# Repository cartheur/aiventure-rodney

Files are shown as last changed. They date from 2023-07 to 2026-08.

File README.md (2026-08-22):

# aiventure-rodney

A project revolving around Heiserman's 1979 robotics proposition. The focus is _scratch-building_ computer that possesses and executes self-learning machine code. They [ref]--(I think an Motorola 6800 computer design book) say this is _a dangerous practice_ having a comptuer self-generate code - with the notion that it programs - but if we do not start seriously exploring in slower formats (slow that our brains can recognize *good* from *bad*), then we we stay stuck. Given the time spent with _Ideal_, games will get one just so far; an effort begins today where we emplant Rodney onto a wheeled platform. Once there, we will backpropagate different kinds of dangerous things. I think this has been accomplished before, I mean the robot by the unknown designer and creator a late academic dubbed _Tati_. And I've watched his films, they are subtley brilliant.

## Challenge

This repository contains a revitialization of the idea of a self-programming robot coupled with the ambition to learn the deepest aspects of how a computer functions at its most basic level. The book, written in 1979, leverages an Intel 8085 8-bit (the very last CPU made to this specification) where the reader builds up the system from scratch including the logic, buffers, and memory systems. Additionally, a tape-drive storage interface is described. Not just an historical curiousity, Rodney continues to teach readers by having them build one step at a time. The challenge of this project is to make a build of the microcomputer system to examine the merit of the "self-programming" claim. On this rests *everything* claimed 'A.I.'. This is a total misnomer and will need to be discussed in great detail.

Current scope note: an `MTK-85`/single-board `8085` trainer was considered as a possible parallel development track and explicitly rejected. This repo stays focused on the Rodney-native `Vector 8801-6` wire-wrap path rather than a separate trainer-board line.

### The Build

There is _a lot_ of work to be done for this project. It is parceled into sections:

* [Chassis Design](/design/README.md)
* [The Front Panel UI](/build/5-front-panel/README.md)
* [Function-Select Circuitry](/build/6-function-select/README.md)
* [RAM and Ports](/build/7-ram-ports/README.md)
* [Motor-Drive Assembly](/build/8-motor-control/README.md)
* [The Microprocessor](/build/9-microprocessor/README.md)
* [Tests](/tests/README.md)

### Pubbing

The publication for this is drafted [here](https://github.com/pub-n-dub/native-self-programming).

### Errata

Tooling used for this project is kept [here](/tools/README.md).

As it is necessary to explore the algorithm of [ideal](https://github.com/cartheur/ideal), we are stretching into unknown realms. How do we document this unexpected journey?

* An alternative to the Von Neumann architecture is the [initiative](/literature/s41565-020-0738-x.pdf).
* A combination of hardware and software [implementation](https://en.wikipedia.org/wiki/In-memory_processing).
* What are some forward-looking paths, considering the initiatives, without going into the nanoscale esoteric?
* SRAM and DRAM are perfectly capable of performing in-memory logic operations while NAND Flash memory is fit for matrix–vector multiplication operations.
* In the context of the application-specific approach to computation, memory-based computational primitives can be used in a variety of tasks ranging from high-precision scientific computing to largely imprecise stochastic computing and everything in-between including deep learning in artificial neural networks (ANNs).
* Development of microFORTH in 1976 for processors like Intel 8080 and Motorola 6800.

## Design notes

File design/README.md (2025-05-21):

## The physical characteristics of this robot

The robot chassis is based on this diagram:

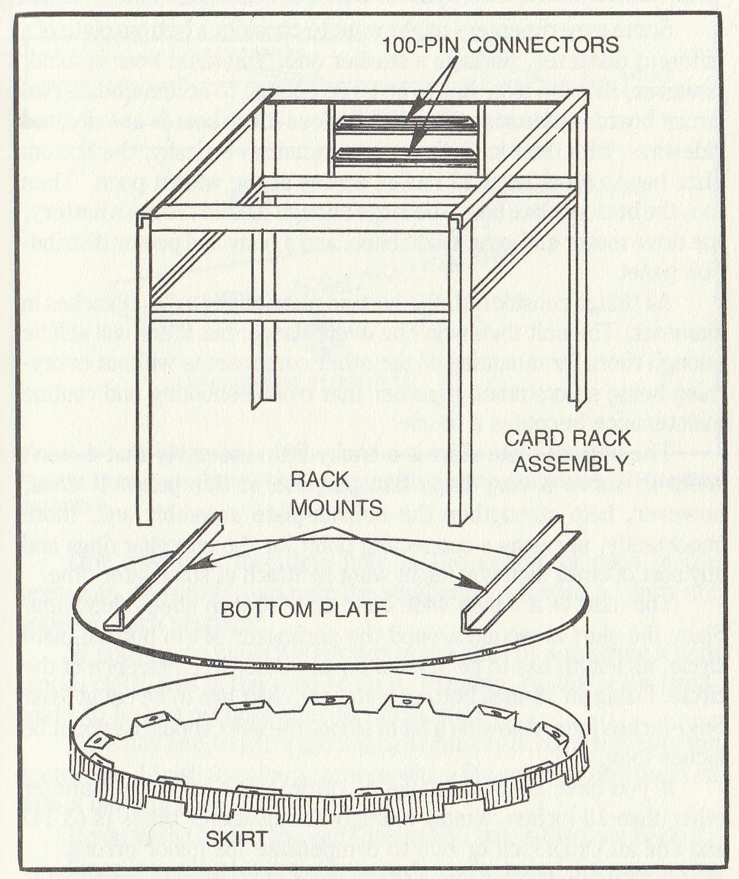
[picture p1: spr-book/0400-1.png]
base


Where the disk is 457 mm (18").

With an upward construct to hold the boards:

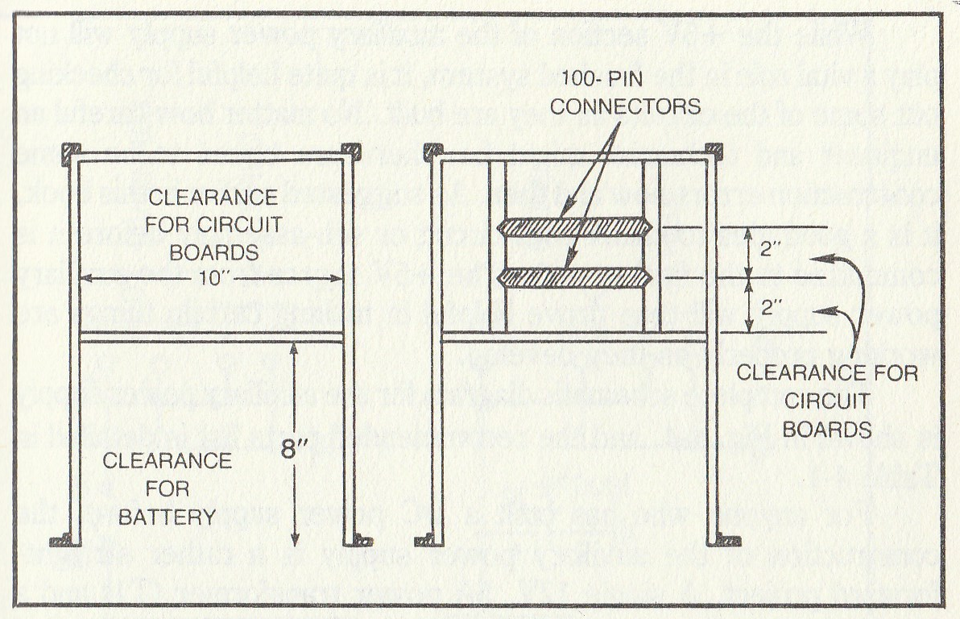
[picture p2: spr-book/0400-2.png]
rack


Re-contemplating the design architecture: Grok analyzed the photos and has come-up with his estimate, given the information regarding Vector 8801 boards that are mounted internally:

* Width: 280 mm
* Depth: 280 mm
* Height: 360 mm
* Weight: 23 kg

### The Vector board 8801-6 using a S-100 bus

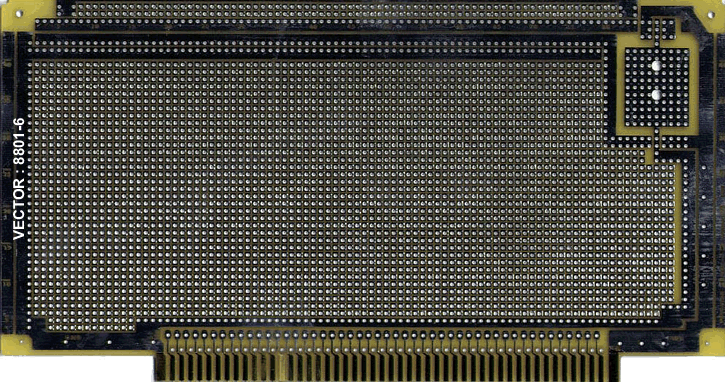
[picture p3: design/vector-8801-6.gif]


_Specification_

| Dimensions  (H x W x Thick) | 10.50" x 5.30" x 0.062"  (266.7mm x 134.6mm x 1.57mm) |
|---|---|
| Hole Diameter | 0.042" (1.067mm) Plated Thru |
| Grid | 0.100" x 0.100" square  (2.54mm x 2.54mm) |
| Circuit Pattern | Pad per hole - both sides |
| Material | FR4 |
| UL Flammability Class | 94V-0 |
| 16 Pin DIP Capacity | 80 |
| Wire-Wrap Terminals | T125, T126 |
| Wire-Wrap Socket Pins | R32 |
| Solder Connector | R681-3 |
| Wire-Wrap Connector | R681-2 |

_Description_

* 100 Gold plated edge contacts (50 each side) on 0.125"(3.175mm) centers
* Pad per hole (square) both sides
* I/O mounting area for ribbon cable header
* Row and column legends provided
* S-100 Form Factor
* Pin `1` and `51` committed to power.
* Pin `50` and `100` committed to ground.

### Grok-generated 3D printing design suggestions

The textual description is [here](/design/GROK.md), while details of FreeCAD design are [here](/design/PRINT.md).

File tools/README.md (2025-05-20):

## Tools to be used to accomplish assembly

This project will follow the advice of the author and perform wirewrapping for each of the connections, except soldering to the switches and LED connections.

_Wire_

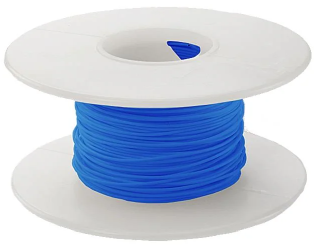
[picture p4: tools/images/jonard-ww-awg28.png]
ww-awg28


Several colors of wirewrap wire will be used to correspond to the different colors utilized in the [interface](/build/5-front-panel/README.md). These are:

* Blue
* Red (mock orange)
* Black (common)
* Raw tinned (common connection)
* Yellow
* Green

All are of the size:`AWG28`.

_Tooling_

The wirewrap tool to be used is this one:

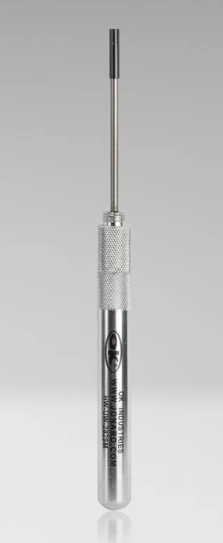
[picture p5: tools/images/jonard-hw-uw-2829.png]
ww-tool


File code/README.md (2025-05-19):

# Example 8085 Assembly Program with Self-Modifying Code

_The following is Grok output from my query of what Heiserman is claiming in his book:_

This Intel 8085 assembly program demonstrates self-modifying code, illustrating runtime adaptability as a crude mechanism for dynamic behavior, aligning with Turing’s idea of machines adapting to experience. It modifies a `JMP` instruction’s target address based on an input condition, while highlighting risks that led Intel to discourage such practices for the 8085.

## Program Description

- **Purpose**: Reads an input value at memory address `2000H` (e.g., simulating sensor data). If the value is ≥ 50, it modifies a `JMP` instruction to point to `HIGH_ROUTINE` (outputs “HIGH”). If < 50, it points to `LOW_ROUTINE` (outputs “LOW”).
- **Self-Modification**: Overwrites the `JMP` instruction’s 16-bit address at runtime to redirect program flow.
- **Context**: Shows adaptability but underscores risks like unpredictability, debugging complexity, and potential memory overwrites.

## How It Demonstrates Self-Modifying Code

1. **Dynamic Modification**:
   - The `JMP_MOD` instruction (initially `JMP 0000H`) is overwritten with the `JMP` opcode (`0C3H`) and the 16-bit address of either `LOW_ROUTINE` or `HIGH_ROUTINE` at `JMP_MOD`, `JMP_MOD+1`, and `JMP_MOD+2`.
   - This redirects program flow based on the input, showcasing runtime adaptability.

2. **Adaptability**:
   - The program adapts by selecting a routine based on the input value at `2000H` (e.g., 60 → `HIGH_ROUTINE`, 40 → `LOW_ROUTINE`), mimicking a response to environmental input, akin to Turing’s experiential learning concept.

3. **Risks Highlighted**:
   - **Unpredictability**: If the 8085 fetches the `JMP` instruction before modification completes, it may execute the outdated `JMP 0000H`, causing incorrect behavior.
   - **Debugging Difficulty**: The dynamic `JMP` target complicates tracing program flow, especially with 1980s tools like in-circuit emulators.
   - **Memory Overwrite Risk**: Errors in address calculations could overwrite critical code or data, reflecting Intel’s reliability concerns.

## Why This Is Crude

- **Not True Learning**: The modification is predefined (choosing between two routines), not a generalized response learned from experience, unlike Turing’s vision of neural-like learning.
- **Limited Scope**: Adaptability is limited to switching between two predefined paths, not a scalable learning mechanism.
- **Hardware Constraints**: The 8085’s 64 KB memory and simple fetch-execute cycle restrict complex self-modification.

## Notes

- **Simulation**: Assumes an input value at `2000H` (e.g., set by external hardware) and writes output to `2001H`. In real systems, I/O ports might be used.
- **Assembly Syntax**: Uses standard 8085 mnemonics, compatible with assemblers like Intel’s ASM80 or modern cross-assemblers.
- **Testing**: Set a value at `2000H` (e.g., 60 for high, 40 for low) and run on an 8085 emulator (e.g., Jubin’s 8085 Simulator). Check `2001H` for ‘H’ or ‘L’.

This example illustrates self-modifying code’s potential for runtime adaptability while highlighting its risks and limitations, reinforcing why Intel advised against it for the 8085.

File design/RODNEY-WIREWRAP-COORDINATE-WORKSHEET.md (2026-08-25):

# Rodney Wire-Wrap Coordinate Worksheet

First-pass socket worksheet for the `3 x Vector 8801-6` Rodney bench build.

This turns the block diagrams and placement plan into **board-local placement coordinates** that are concrete enough to start socket layout and hole counting.

Companion docs:

- [RODNEY-WIREWRAP-BLOCK-DIAGRAM.md](/home/cartheur/ame/aiventure/aiventure-github/cartheur/aiventure-rodney/design/RODNEY-WIREWRAP-BLOCK-DIAGRAM.md:1)
- [RODNEY-WIREWRAP-PLACEMENT-PLAN.md](/home/cartheur/ame/aiventure/aiventure-github/cartheur/aiventure-rodney/design/RODNEY-WIREWRAP-PLACEMENT-PLAN.md:1)
- [RODNEY-WIREWRAP-DESIGN-SPEC.md](/home/cartheur/ame/aiventure/aiventure-github/cartheur/aiventure-rodney/design/RODNEY-WIREWRAP-DESIGN-SPEC.md:1)

Rendered planning images:

- [Board A worksheet JPG](/home/cartheur/ame/aiventure/aiventure-github/cartheur/aiventure-rodney/diagrams/RodneyBoardA-worksheet.jpg)
- [Board B worksheet JPG](/home/cartheur/ame/aiventure/aiventure-github/cartheur/aiventure-rodney/diagrams/RodneyBoardB-worksheet.jpg)
- [Board C worksheet JPG](/home/cartheur/ame/aiventure/aiventure-github/cartheur/aiventure-rodney/diagrams/RodneyBoardC-worksheet.jpg)
- [Overall stack JPG](/home/cartheur/ame/aiventure/aiventure-github/cartheur/aiventure-rodney/diagrams/RodneyWirewrapWorksheetStack.jpg)

Silkscreen-style overlays on the actual board image:

- [Silkscreen overlay doc](/home/cartheur/ame/aiventure/aiventure-github/cartheur/aiventure-rodney/design/RODNEY-WIREWRAP-SILKSCREEN-OVERLAYS.md:1)

## Coordinate System

- Each board uses a **planning grid** in `0.1"` hole increments.
- Coordinates are written as `Xnn, Ynn`.
- `X1` is the left side of the usable component field.
- `Y1` is the top of the usable component field.
- The bottom connector/breakout band is reserved as `Y35-Y40`.
- Default orientation is viewed from the **component side**, with the edge connector at the bottom.
- `Pin-1 origin` means the coordinate marks the **pin 1 hole** for the socket.
- `E-W` means the long axis of the package runs left-to-right.

This worksheet is intentionally a **build-planning grid**, not a claim about the original Vector silkscreen row/column labels.

## Planning Lanes

Apply these on all three boards unless routing forces a local exception:

- `X1-X6`: power lane
- `X87-X96`: bus, breakout, or service lane
- `Y1-Y5`: test points, jumpers, and top-edge service area
- `Y35-Y40`: connector, power entry, and bus ingress/egress

## Package Span Reference

These spans are for worksheet planning only.

| Package | Typical Use Here | Span |
|---|---|---|
| DIP-14 narrow | `74LS04`, `74LS164`, `74LS93` | `7 x 4` |
| DIP-16 narrow | `74LS138`, `74LS139` | `8 x 4` |
| DIP-20 narrow | `74LS245`, `74LS373`, latch/buffer choices | `10 x 4` |
| DIP-28 wide | `6264`, `62256`, EEPROM | `14 x 7` |
| DIP-40 wide | `8085A` | `20 x 7` |

## Board A Worksheet

Role: CPU, clock/reset, latch, transceiver, coarse decode, bus breakout.

### Planned Placements

| Ref | Function | Package | Pin-1 origin | Orientation | Notes |
|---|---|---|---|---|---|
| `U1` | `8085A` CPU | DIP-40 wide | `X39, Y16` | `E-W` | keep central |
| `U2` | `74LS373` address latch | DIP-20 narrow | `X17, Y16` | `E-W` | bus-side pins face CPU |
| `U3` | `74LS245` data buffer | DIP-20 narrow | `X70, Y16` | `E-W` | short shared-data path |
| `U4` | `74LS138` coarse decode | DIP-16 narrow | `X72, Y24` | `E-W` | decode fan-out toward bus lane |
| `U5` | `74LS04` clock/reset glue | DIP-14 narrow | `X73, Y8` | `E-W` | keep clear of bus bundles |
| `Y1` | crystal | 2-pin oscillator part | `X61, Y8` | `E-W` | adjacent to `U5` |
| `SW1` | reset pushbutton | panel or PCB pushbutton | `X54, Y8` | `E-W` | top-edge access |
| `TP1-TP6` | `CLK`, `ALE`, `/RD`, `/WR`, `IO/M`, `/RESET_OUT` | test posts | `X10-X40, Y3` | row | leave clip clearance |
| `J1` | board bus header / service header | 2-row header | `X84, Y26` | vertical | export shared bus |
| `Cbulk` | board bulk capacitor | radial | `X4, Y31` | n/a | near power entry |

### Routing Intent

- `AD0-AD7` should stay between `U1` and `U2`.
- `D0-D7` shared path should stay between `U1` and `U3`.
- `CLK` and reset traces should stay in the upper-right quiet zone.
- Bus breakout should drop into `J1` without crossing the top test-point strip.

## Board B Worksheet

Role: program RAM, monitor ROM, learned-state memory, decode, MMA/MMD path.

### Planned Placements

| Ref | Function | Package | Pin-1 origin | Orientation | Notes |
|---|---|---|---|---|---|
| `U1` | `62256` main memory | DIP-28 wide | `X37, Y10` | `E-W` | selected part `Alliance AS6C62256-55PIN`; dominant board feature |
| `U2` | `74LS138` region decode | DIP-16 narrow | `X13, Y20` | `E-W` | close to bus ingress |
| `U3` | `74LS139` subdecode | DIP-16 narrow | `X24, Y20` | `E-W` | pairs with `U2` |
| `U4` | MMA low latch | DIP-20 narrow | `X48, Y20` | `E-W` | close to lower memory address side |
| `U5` | MMA high latch | DIP-20 narrow | `X60, Y20` | `E-W` | close to upper memory address side |
| `U6` | MMD path register / gate | DIP-20 narrow | `X73, Y20` | `E-W` | keep close to `U1` data side |
| `U7` | `6264` program RAM | DIP-28 wide | `X12, Y28` | `E-W` | selected part `Alliance AS6C6264-55PCN`; easy to isolate during bring-up |
| `U8` | EEPROM / monitor ROM | DIP-28 wide | `X61, Y28` | `E-W` | opposite side from program RAM |
| `TP1-TP8` | `/PRG_RAM_CS`, `/ROM_CS`, `/MMA_L_CS`, `/MMA_H_CS`, `/MMD_CS`, `MMA0`, `MMA8`, `D0` | test posts | `X10-X50, Y3` | row | keep contiguous |
| `J1` | bus in / service header | 2-row header | `X84, Y26` | vertical | one clean ingress point |
| `Cbulk` | board bulk capacitor | radial | `X4, Y31` | n/a | near power entry |

### Routing Intent

- `U4` and `U5` should sit adjacent to the `62256` address side.
- `U6` should sit on the `62256` data side with a short read/write gate path.
- `U7` and `U8` should route down toward the lower bus band rather than across `U1`.
- Decode outputs should fan from left to right, not back through the bus lane.

### Board B ZIF Clearance Note

If you choose `3 x 28-pin ZIFs` on Board B, treat `U1`, `U7`, and `U8` as **clearance footprints**, not just DIP bodies.

- keep at least one empty hole row around each of `U1`, `U7`, and `U8` where practical
- do not place tall headers, posts, or electrolytics immediately beside the ZIF lever side
- keep the area above `U7` and `U8` free of tie-downs or harness crossings
- leave `J1` wiring low and to the right so it does not interfere with the `U8` lever

The current Board B placement is acceptable for `3 x 28-pin ZIFs`, but only if we preserve those three memory areas as no-crowding zones during final socket placement.

## Board C Worksheet

Role: bench inputs, random source, output latch, LED observability, local decode.

### Planned Placements

| Ref | Function | Package | Pin-1 origin | Orientation | Notes |
|---|---|---|---|---|---|
| `SW1` | `ENVL` DIP switch pack | 8-position DIP switch | `X8, Y17` | `E-W` | selected part `CTS 195-8MST`; top/piano access |
| `SW2` | `ENVH` optional DIP switch | 8-position DIP switch | `X8, Y27` | `E-W` | selected part `CTS 195-8MST`; can leave unpopulated |
| `U1` | input buffer | DIP-20 narrow | `X29, Y17` | `E-W` | between switches and bus |
| `U2` | output latch | DIP-20 narrow | `X49, Y17` | `E-W` | short path to LEDs |
| `U3` | local decode | DIP-16 narrow | `X29, Y27` | `E-W` | local register select |
| `U4` | `TSWR` LFSR / random source | DIP-14 narrow | `X49, Y9` | `E-W` | distinct top-center block |
| `LED1-LED8` | `ACTL` LED row | LED bar or discrete row | `X73, Y17` | vertical row | keep readable |
| `LED9-LED16` | debug / `ACTH` row | LED bar or discrete row | `X73, Y27` | vertical row | optional second bank |
| `TP1-TP4` | `ENVL`, `TSWR`, `ACTL`, `spare` | test posts | `X10-X28, Y3` | row | top edge probing |
| `JP1-JP3` | mode / readback jumpers | 0.1" jumpers | `X74-X86, Y3` | row | configurable behavior |
| `J1` | bus in / service header | 2-row header | `X84, Y31` | vertical | lower-right ingress |
| `Cbulk` | board bulk capacitor | radial | `X4, Y31` | n/a | near power entry |

### Routing Intent

- Manual inputs stay left.
- Decode and buffering stay central.
- Visual outputs stay right.
- `TSWR` stays above the switch path so it does not get lost in LED or pull-up wiring.

### Optional Joy Circuit

If the `ETI Systems J1-00105` joystick is installed as **the joy circuit**:

- place the panel wiring landing point near the `SW2` / `ENVH` side of `Board C`
- map `JOY_UP`, `JOY_DN`, `JOY_LT`, and `JOY_RT` onto `4` `ENVH` input bits through the existing `U1` input-buffer path
- use `4 x 10k` pull-ups to `+5V` or one equivalent resistor network so each line idles high and the joystick contact pulls low when active
- keep the first-pass circuit simple: no latch, no ADC, and no extra state machine
- add optional small series resistors only if the panel wiring run proves noisy
- handle debounce in software first; add RC or Schmitt cleanup later only if testing shows a real need

## Board-to-Board Cable Worksheet

Use two main cable groups and one optional service group.

| Cable | Source | Destination | Signals |
|---|---|---|---|
| `CAB-A-B` | Board A `J1` | Board B `J1` | `A0-A15`, `D0-D7`, `/RD`, `/WR`, `IO/M`, `/RESET_OUT`, `+5V`, `GND` |
| `CAB-A-C` | Board A `J1` | Board C `J1` | `A0-A15`, `D0-D7`, `/RD`, `/WR`, `IO/M`, `/RESET_OUT`, `+5V`, `GND` |
| `CAB-SVC` optional | Board A service header | Board B/C service posts | `CLK`, `ALE`, `READY`, spare debug lines |

## Practical Build Order

1. Mark the power lane, bus lane, top service strip, and bottom connector band on all three boards.
2. Place only the largest sockets first: `8085A`, `62256`, `6264`, EEPROM, and the two main central latches.
3. Dry-fit headers and test-post rows before soldering sockets permanently.
4. Confirm wrap-tool hand clearance around `U1` on each board.
5. Add decouplers and bulk capacitors before any dense signal wrapping.

## Swap / ZIF Strategy

These are the devices most worth isolating for swap testing:

| Priority | Ref | Device | Recommendation | Reason |
|---|---|---|---|---|
| `1` | `U8` | EEPROM / monitor ROM | use a **ZIF on top of a machine-pin wire-wrap socket** | most likely image-swapped device during bring-up |
| `2` | `U7` | `6264` program RAM | use a **ZIF on top of a machine-pin wire-wrap socket** if you have one | useful for RAM substitution and fault isolation |
| `3` | `U1` Board A | `8085A` CPU | keep mechanically isolated and consider ZIF only if you expect CPU swapping | helpful if testing multiple 8085s, but ZIF height and lever access matter |
| `4` | `U1` Board B | `62256` main memory | normal wire-wrap socket is fine unless you expect repeated memory experiments | usually less frequently swapped than ROM or program RAM |

Recommended default:

- definitely ZIF: `U8` EEPROM
- good candidate for ZIF: `U7` program RAM
- optional ZIF: `Board A U1` `8085A`
- usually leave normal: `Board B U1` `62256`

If you are committing to `3 x 28-pin ZIFs` on Board B, promote `Board B U1` from optional to planned and preserve clearance around all three memory positions from the start.

Mechanical caution:

- A ZIF should plug into a **machine-pin/socket-pin carrier**, not directly into fragile loose headers.
- For Board B, the intended stack is: **Vector board -> soldered machine-pin wire-wrap socket -> plugged-in 28-pin ZIF -> device under test**.
- Leave extra side clearance for the ZIF lever, especially around `Board A U1` and `Board B U8`.
- On the current layout, `Board B U8` is the cleanest ZIF location, `Board B U7` is also reasonable, and `Board B U1` is workable if its surrounding wrap field is kept open.

## Assumptions and Cautions

- These are **first-pass placement coordinates**, not museum-faithful original socket locations.
- `U4-U6` on Board B and `U1-U4` on Board C are defined by role and package size; exact part substitutions may shift placement by a hole or two.
- If you decide to move EEPROM to Board A later, Board B has enough room to reclaim that block as a debug header or wider MMD section.
- Before committing to wrap, it would still be smart to print this worksheet and do one paper overlay against the actual `8801-6`.

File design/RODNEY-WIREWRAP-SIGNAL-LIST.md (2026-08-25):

# Rodney Wire-Wrap Signal List

Board-to-board signal list for the `3 x Vector 8801-6` bench-first Rodney self-programming core.

Companion to:

- [RODNEY-WIREWRAP-DESIGN-SPEC.md](/home/cartheur/ame/aiventure/aiventure-github/cartheur/aiventure-rodney/design/RODNEY-WIREWRAP-DESIGN-SPEC.md:1)
- [RODNEY-WIREWRAP-DECODE-TABLE.md](/home/cartheur/ame/aiventure/aiventure-github/cartheur/aiventure-rodney/design/RODNEY-WIREWRAP-DECODE-TABLE.md:1)
- [RODNEY-WIREWRAP-PLACEMENT-PLAN.md](/home/cartheur/ame/aiventure/aiventure-github/cartheur/aiventure-rodney/design/RODNEY-WIREWRAP-PLACEMENT-PLAN.md:1)

## Board Names

- `Board A`: CPU and bus support
- `Board B`: memory and decode
- `Board C`: bench I/O and observability

## Naming Convention

- `Axx` means address line
- `Dxx` means data line
- leading `/` means active-low
- `MMA` means main-memory address register path
- `MMD` means main-memory data path

## Interconnect Philosophy

- `Board A` is the bus source.
- `Board B` is the primary bus consumer for memory.
- `Board C` is the bus consumer for memory-mapped I/O.
- Keep all bus lines straight-through and avoid unnecessary daisy-chained detours.
- Route from `Board A` to `Board B` first, then to `Board C`, unless physical rack placement makes `A -> C -> B` materially shorter.

## System Buses

## Address Bus

These are the de-multiplexed, stable address lines after the `74LS373` latch on `Board A`.

| Signal | Source | Destinations | Notes |
|---|---|---|---|
| `A0` | Board A | Board B, Board C | latched low address |
| `A1` | Board A | Board B, Board C | |
| `A2` | Board A | Board B, Board C | |
| `A3` | Board A | Board B, Board C | |
| `A4` | Board A | Board B, Board C | |
| `A5` | Board A | Board B, Board C | |
| `A6` | Board A | Board B, Board C | |
| `A7` | Board A | Board B, Board C | |
| `A8` | Board A | Board B, Board C | direct from 8085 |
| `A9` | Board A | Board B, Board C | |
| `A10` | Board A | Board B, Board C | |
| `A11` | Board A | Board B, Board C | |
| `A12` | Board A | Board B, Board C | |
| `A13` | Board A | Board B, Board C | |
| `A14` | Board A | Board B, Board C | |
| `A15` | Board A | Board B, Board C | |

## Data Bus

| Signal | Source | Destinations | Notes |
|---|---|---|---|
| `D0` | shared | Board B, Board C | keep stub short |
| `D1` | shared | Board B, Board C | |
| `D2` | shared | Board B, Board C | |
| `D3` | shared | Board B, Board C | |
| `D4` | shared | Board B, Board C | |
| `D5` | shared | Board B, Board C | |
| `D6` | shared | Board B, Board C | |
| `D7` | shared | Board B, Board C | |

## CPU Control Signals

| Signal | Source | Destinations | Notes |
|---|---|---|---|
| `ALE` | Board A | Board A local, Board B optional test | usually only local, but export to test post |
| `/RD` | Board A | Board B, Board C | memory and I/O reads |
| `/WR` | Board A | Board B, Board C | memory and I/O writes |
| `IO/M` | Board A | Board B, Board C | decode qualifier |
| `/RESET_OUT` | Board A | Board B, Board C | fan out to reset tables/latches |
| `CLK` | Board A | Board B optional, Board C optional | only if synchronous logic on remote boards needs it |
| `READY` | Board A | local | optional export if wait-state logic later added |
| `HOLD` | local tie | local | not exported in first build |
| `HLDA` | Board A | test post only | optional |

## Power and Ground

| Signal | Source | Destinations | Notes |
|---|---|---|---|
| `+5V` | power entry | Boards A, B, C | heavier gauge wire |
| `GND` | power entry | Boards A, B, C | multiple returns preferred |
| `+12V` optional | future | Board C / actuator stage | not required for bench-first logic |

## Board A Local Signals

These do not need to leave `Board A` except to test posts.

| Signal | Purpose |
|---|---|
| `AD0-AD7` | raw multiplexed 8085 low address/data bus |
| `CLK_INT` | oscillator output |
| `RESET_RC` | reset timing node |
| `LATCH_EN` | same function as `ALE`, local reference |

## Board B Interface

## Memory Devices

| Logical Function | Suggested Device | Bus Signals |
|---|---|---|
| program RAM | `6264` | `A0-A12`, `D0-D7`, `/PRG_RAM_CS`, `/RD`, `/WR` |
| EEPROM/monitor | `28C16` or `28C64` | `A0-A12`, `D0-D7`, `/ROM_CS`, `/RD`, `/WR` optional |
| main memory | `62256` | CPU-visible via `MMA` and `MMD` register path, not directly linear CPU map unless desired |

## Board B Internal Control Signals

| Signal | Source | Destination | Notes |
|---|---|---|---|
| `/PRG_RAM_CS` | Board B decode | 6264 | `0000h-1FFFh` |
| `/ROM_CS` | Board B decode | EEPROM | `2000h-3FFFh` |
| `/MMA_L_CS` | Board B decode | MMA low latch | `8004h` |
| `/MMA_H_CS` | Board B decode | MMA high latch | `8005h` |
| `/MMD_CS` | Board B decode | MMD data register / main memory data path | `8006h` |
| `/MAIN_RAM_CS` | Board B local | 62256 | generated from MMA path, not CPU address bus directly |
| `MMA0-MMA7` | MMA low latch | 62256 address | lower learned-state address |
| `MMA8-MMA15` | MMA high latch | 62256 address | upper learned-state address |

## Board B Main-Memory Path

Recommended implementation:

- CPU writes `8004h` to load `MMA low`
- CPU writes `8005h` to load `MMA high`
- CPU reads or writes `8006h` to access the byte at `main_memory[MMA]`

Signal detail:

| Signal | Source | Destination | Notes |
|---|---|---|---|
| `MMA_L[7:0]` | low latch | main memory address lines `A0-A7` | |
| `MMA_H[7:0]` | high latch | main memory address lines `A8-A15` | upper unused bits may be tied or reserved |
| `MMD_IN[7:0]` | CPU data bus | 62256 data path during write | |
| `MMD_OUT[7:0]` | 62256 data path | CPU data bus during read | |
| `/MMD_READ_GATE` | decode + `/RD` | data path enable | |
| `/MMD_WRITE_GATE` | decode + `/WR` | data path write enable | |

## Board C Interface

## I/O Registers

| Logical Function | Address | Direction |
|---|---|---|
| `ENVL` | `8000h` | read |
| `ENVH` optional | `8001h` | read |
| `TSWR` pseudo-random source | `8002h` | read |
| `ACTL` | `8008h` | write |
| `ACTH` optional | `8009h` | write |

## Board C Internal Control Signals

| Signal | Source | Destination | Notes |
|---|---|---|---|
| `/ENVL_CS` | Board C decode | input buffer or switch read path | |
| `/ENVH_CS` | Board C decode | optional second input port | |
| `/TSWR_CS` | Board C decode | LFSR/random source | |
| `/ACTL_CS` | Board C decode | output latch | |
| `/ACTH_CS` | Board C decode | optional output latch | |

## Recommended ENVL Bit Assignment

Bench-first assignment:

| Bit | Name | Meaning |
|---:|---|---|
| `D0` | `LMR` | left motor reverse or symbolic action feedback |
| `D1` | `LMF` | left motor forward or left run status |
| `D2` | `RMR` | right motor reverse or symbolic action feedback |
| `D3` | `RMF` | right motor forward or right run status |
| `D4` | `LSTALL` | left-side fault or stall |
| `D5` | `RSTALL` | right-side fault or stall |
| `D6` | `FEED` | charge/feed/contact |
| `D7` | `HUNGRY` or spare | internal need bit or spare |

This keeps later Beta/Gamma mapping close to the book’s naming scheme without forcing exact original hardware.

Optional joy circuit overlay:

- if the `ETI Systems J1-00105` operator joystick is installed, treat it as **the joy circuit**
- recommended named inputs: `JOY_UP`, `JOY_DN`, `JOY_LT`, `JOY_RT`
- preferred first-pass mapping: land the joy circuit on `ENVH` or another spare `Board C` read path so the baseline `ENVL` motor or status mapping stays intact
- alternative temporary mapping: repurpose spare `ENVL` bits during bench experiments if a dedicated second read path is not yet populated
- intended use: human environmental feedback, corrective cueing, reward-direction tagging, and manual behavior nudging during trainer experiments

## Recommended ACTL Bit Assignment

| Bit | Name | Meaning |
|---:|---|---|
| `D0-D3` | action nibble | primary learned response code |
| `D4-D5` | confidence passthrough or debug | optional LED mirror |
| `D6-D7` | spare | future actuator or debug use |

## Cross-Board Cable Groups

## Group 1: main bus cable

Recommended between `Board A` and `Board B`:

- `A0-A15`
- `D0-D7`
- `/RD`
- `/WR`
- `IO/M`
- `/RESET_OUT`
- `+5V`
- `GND`

## Group 2: I/O bus cable

Recommended between `Board A` and `Board C`:

- `A0-A15`
- `D0-D7`
- `/RD`
- `/WR`
- `IO/M`
- `/RESET_OUT`
- `+5V`
- `GND`

## Group 3: optional service cable

Only if physically useful:

- `CLK`
- `ALE`
- `READY`
- spare debug lines

## Test Points

Add these on each board:

### Board A

- `CLK`
- `/RESET_OUT`
- `ALE`
- `/RD`
- `/WR`
- `IO/M`
- `A0`
- `A15`
- `D0`
- `D7`

### Board B

- `/PRG_RAM_CS`
- `/ROM_CS`
- `/MMA_L_CS`
- `/MMA_H_CS`
- `/MMD_CS`
- one `MMA` low bit
- one `MMA` high bit
- one main-memory data bit

### Board C

- `/ENVL_CS`
- `/TSWR_CS`
- `/ACTL_CS`
- `ENVL D0`
- `TSWR D0`
- `ACTL D0`

## Grounding Notes

- Use multiple ground wraps between boards, not a single return.
- Run one dedicated heavier `+5V` feed per board.
- Tie logic grounds first before bringing up the CPU.

## Revision Notes

This signal list is intentionally conservative. It favors simpler routing and clear observability over connector minimization.

For the current physical build, we are using `2` edge connectors total and hard-wiring `Board C` into the stack harness. That keeps `Board A` and `Board B` removable during CPU and memory bring-up while leaving the lower-risk bench I/O board fixed.

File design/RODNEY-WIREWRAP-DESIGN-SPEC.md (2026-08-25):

# Rodney Self-Programming Core

Design spec for a new wire-wrap implementation on `Vector 8801-6` plugboards.

## Purpose

This spec defines a **bench-first** hardware build that preserves the book's actual self-programming mechanism:

- environment-indexed main memory
- Beta confidence update loop
- Gamma generalization pass

It does **not** attempt a museum-faithful chip-for-chip recreation of every 1979 board. The goal is a buildable, debuggable system that can run the same class of learning behavior on new wire-wrapped hardware.

## Scope

This design covers the minimum viable self-programming core:

- `8085A` CPU
- writable program memory
- writable main memory
- simple environment inputs
- simple action outputs
- random source
- bench I/O for bring-up
- optional expansion path to motors and sensors later

This first build is intended to validate the self-programming claim on the bench before integrating with a mobile robot chassis.

## Design Principles

- Keep the logical model from the book, even when parts change.
- Prefer parts that are still obtainable in DIP packages.
- Reduce wire-wrap risk by using fewer chips and clearer decode boundaries.
- Make the first system observable: LEDs, DIP switches, test headers, single-step-friendly reset and halt controls.
- Preserve the separation between:
  - program store
  - learned main memory
  - environment inputs
  - action outputs

## Assumptions

- We are reproducing the **behavioral architecture**, not every original schematic detail.
- The CPU remains `8085A`.
- The original `2114` and `2147` RAMs may be replaced with newer SRAM where that simplifies the build.
- The first version uses **bench environment simulation** with switches instead of motors and charger sensing.
- A later version can map the same logical ports to real sensors and actuators.

## System Architecture

## Functional Blocks

1. `CPU board`
   - `8085A`
   - clock
   - reset
   - address latch for multiplexed low address bus
   - data bus transceiver/buffering
   - expansion headers

2. `memory board`
   - program RAM
   - optional monitor/bootstrap EEPROM
   - main memory
   - decode logic

3. `I/O board`
   - `ENVL` input
   - optional `ENVH` input
   - `ACTL` output
   - optional `ACTH` output
   - random source
   - status LEDs
   - bench control inputs

## Recommended Board Partition

Use `3 x Vector 8801-6` boards.

- `Board A`: CPU and bus support
- `Board B`: memory and decode
- `Board C`: bench I/O and observability

This keeps the wire-wrap density reasonable and follows the spirit of the repo's existing split-board work.

## Logical Memory and I/O Map

Suggested initial map:

- `0000h-1FFFh` program RAM, `8 KB`
- `2000h-3FFFh` monitor/EEPROM window, optional, `8 KB`
- `4000h-7FFFh` main memory, `16 KB`
- `8000h` `ENVL`
- `8001h` `ENVH`, optional
- `8002h` random source
- `8004h` main-memory address low register
- `8005h` main-memory address high register
- `8006h` main-memory data register
- `8008h` `ACTL`
- `8009h` `ACTH`, optional

Notes:

- This is not a claim about the exact original book map.
- It is a clean memory-mapped organization that preserves the same concepts.
- If desired, the port labels can later be aliased in source to match book terminology more closely.

## Data Model

## Environment

Minimum first-pass environment:

- `ENVL`, `8 bits`
  - reserve bits for:
    - left run state
    - left stall
    - right run state
    - right stall
    - feed/contact
    - hungry or internal need
    - spare 2 bits

Optional:

- `ENVH`, `8 bits`
  - additional sensor growth

## Action

Minimum first-pass action:

- `ACTL`, `8 bits`
  - lower nibble for motion or symbolic response code
  - upper bits reserved for flags, lamps, or later actuator expansion

Optional:

- `ACTH`, `8 bits`

## Learned Main-Memory Word

Store one byte per environment state in the first system:

- lower nibble: action code
- upper 2 bits: confidence
- remaining bits: reserved

This matches the Beta/Gamma evidence well enough to prototype the learning mechanism cleanly.

## Bring-Up Strategy

Phase 1:

- build the CPU board
- prove reset, clock, address latch, and RAM execution

Phase 2:

- add bench `ENVL` switches and `ACTL` LEDs
- run Alpha/Beta routines with random source

Phase 3:

- add main-memory board and validate confidence update behavior

Phase 4:

- enable Gamma generalization pass

Phase 5:

- only after bench validation, map `ENV` and `ACT` lines to real robot electronics

## Recommended IC Choices

## CPU and bus

- `8085A` DIP-40
- `74LS373` for AD0-AD7 latch
- `74LS245` for data bus buffering
- `74LS138` for decode
- `74LS00` and `74LS04` for glue logic

Rationale:

- These are easier to source than some original parts.
- `74LS245` is a practical substitute for older bus-interface parts in a fresh build.

## Memory

- `6264` SRAM, `8 KB x 8`, for program RAM
  - selected first-pass part: `Alliance AS6C6264-55PCN`, `DIP-28`, `55ns`
- `62256` SRAM, `32 KB x 8`, for main memory
  - selected first-pass part: `Alliance AS6C62256-55PIN`, `DIP-28`, `55ns`
- `28C16` or `28C64` EEPROM for bootstrap or monitor ROM

Rationale:

- Fewer chips
- easier wire-wrap routing
- simpler power and troubleshooting

## Random source

Use one of these:

1. `74LS164` pseudo-random LFSR
2. `74LS93` plus XOR feedback
3. noise source plus Schmitt trigger if later needed

Recommendation:

- start with a synchronous pseudo-random generator using TTL

## Bench I/O

- `74LS273` latch for LED output register
- DIP switch packs for `ENVL` and `ENVH`
  - selected first-pass part: `CTS 195-8MST`, through-hole, `8-position`, piano/top-actuated
- LED bar or discrete LEDs for `ACTL` and debug signals

## Electrical Requirements

- `+5V` logic rail, regulated
- current first-pass bench source: `+5V` USB battery clipped onto the logic rail with `2` HP `5004A` signature-analyzer style grabber leads
- separate bench `+12V` only if later actuator hardware is attached
- local `0.1uF` decoupler per IC
- one bulk capacitor per board, `47uF` to `470uF`
- star-ish grounding between boards
- short bus runs between board connectors where possible

Preferred bring-up strategy:

- use the lightweight USB battery setup for first power-up, reset checks, and initial logic validation
- fall back to a wall-powered bench supply only if behavior suggests power droop, clip resistance, or inadequate current delivery

Bring-up caution:

- confirm the USB source holds close to `5V` with the full logic load attached
- clip both `+5V` and `GND` at firm board input points, not at random logic nodes
- if reset or clock behavior looks unstable, suspect power-source droop or clip resistance early

## Wire-Wrap Construction Rules

- Use machine-pin wire-wrap sockets only.
- Put one `0.1uF` capacitor physically adjacent to each IC power pair.
- Reserve one edge of each board for bus ingress and egress.
- Keep the address and data buses straight and color-coded.
- Run power and ground first, then clock/reset, then bus, then decode, then local signals.
- Use heavier insulated wire for power rails and `30 AWG` Kynar for logic wraps.
- Add test posts for:
  - `CLK`
  - `RESET`
  - `/RD`
  - `/WR`
  - `ALE`
  - `IO/M`
  - `A0`
  - `A15`
  - `D0`
  - `D7`

## Bill of Materials

## Core Boards

| Item | Qty | Notes |
|---|---:|---|
| Vector `8801-6` wire-wrap plugboard | 3 | CPU, memory, I/O |
| 100-pin wire-wrap edge connector | 2 | use on `Board A` and `Board B`; hard-wire `Board C` in the stack |
| Vector wire-wrap terminals or equivalent | 300+ | optional depending on board strategy |

## CPU Board BoM

| Item | Qty | Notes |
|---|---:|---|
| `8085A` DIP-40 | 1 | CPU |
| `74LS373` DIP-20 | 1 | multiplexed address latch |
| `74LS245` DIP-20 | 1 | data bus transceiver |
| `74LS138` DIP-16 | 1 | decode |
| `74LS00` DIP-14 | 1 | glue logic |
| `74LS04` DIP-14 | 1 | invert/reset shaping |
| crystal `6.144 MHz` or `5 MHz` | 1 | choose one standard and code to it |
| crystal load capacitors `22pF` | 2 | if crystal circuit requires |
| reset pushbutton | 1 | front-edge or off-board |
| `10k` resistor | 2 | reset pull-up/pull-down as needed |
| `1uF` to `10uF` capacitor | 1 | reset timing |
| `0.1uF` ceramic capacitors | 6 | decoupling |
| `47uF` electrolytic | 1 | board bulk |
| DIP-40 wire-wrap socket | 1 | CPU |
| DIP-20 wire-wrap socket | 2 | latch, transceiver |
| DIP-16 wire-wrap socket | 1 | decoder |
| DIP-14 wire-wrap socket | 2 | glue logic |
| 0.1" male header strips | as needed | debug and board interconnect |

## Memory Board BoM

| Item | Qty | Notes |
|---|---:|---|
| `6264` SRAM DIP-28 | 1 | program RAM |
| `62256` SRAM DIP-28 | 1 | main memory |
| `28C16` or `28C64` EEPROM DIP-24/28 | 1 | optional monitor/bootstrap |
| `74LS138` DIP-16 | 1 | memory select |
| `74LS139` DIP-16 | 1 | extra decode |
| `74LS32` DIP-14 | 1 | decode glue, optional |
| `74LS00` DIP-14 | 1 | decode glue |
| `74LS273` DIP-20 | 2 | MA low/high latches if using explicit MMA registers |
| `74LS245` DIP-20 | 1 | optional data-path isolation |
| `0.1uF` ceramic capacitors | 8 | decoupling |
| `47uF` electrolytic | 1 | board bulk |
| DIP-28 wire-wrap socket | 3 | SRAM and EEPROM |
| DIP-20 wire-wrap socket | 3 | latches/buffer |
| DIP-16 wire-wrap socket | 2 | decoders |
| DIP-14 wire-wrap socket | 2 | glue |

## I/O Board BoM

| Item | Qty | Notes |
|---|---:|---|
| `74LS244` DIP-20 | 1 | input buffering |
| `74LS273` DIP-20 | 1 | output latch |
| `74LS165` or switch-direct input path | 1 | optional switch capture |
| `74LS164` or `74HC164` DIP-14 | 1 | random/LFSR basis |
| `74LS86` DIP-14 | 1 | XOR feedback for PRNG |
| DIP switch, `8-position` | 2 | `ENVL`, optional `ENVH` |
| LEDs, `5mm` | 16 | `ACTL`, debug, status |
| LED resistors `330R` | 16 | one per LED |
| momentary switches | 2 | step/test or mode control |
| `10k` resistor network or discrete | 2 | switch pull resistors |
| `0.1uF` ceramic capacitors | 6 | decoupling |
| `47uF` electrolytic | 1 | board bulk |
| DIP-20 wire-wrap socket | 2 | buffer/latch |
| DIP-14 wire-wrap socket | 2 | PRNG glue |

## Construction Materials

| Item | Qty | Notes |
|---|---:|---|
| `30 AWG` Kynar wire-wrap wire | 3 to 5 spools | use multiple colors |
| heavier hookup wire for power, `22-24 AWG` | 1 spool each | red and black minimum |
| wire-wrap tool, manual or electric | 1 | required |
| unwrap tool | 1 | required |
| temperature-controlled soldering iron | 1 | for connectors, regulators, headers |
| logic probe | 1 | highly recommended |
| oscilloscope | 1 | strongly recommended |
| bench `+5V` supply | 1 | current-limited |

## Optional Expansion BoM

These are not required for the first bench validation:

| Item | Qty | Notes |
|---|---:|---|
| `8255` PPI DIP-40 | 1 | if wider I/O is preferred over discrete logic |
| UART or serial monitor hardware | 1 | optional debug convenience |
| NVRAM or battery backup circuit | 1 | preserve learned memory |
| relay or transistor motor driver stage | later | for mobile Rodney |
| analog sensor front-end hardware | later | for richer environment bits |

### Analog Sensor Preview

If we want to preview a richer `ENVL` input path without changing the baseline Rodney bring-up, the cleanest branch is a small analog front-end prototype that converts real-world signals into stable logic bits.

Suggested preview targets:

- ambient light or directed light level
- microphone or sound-trigger level

Suggested preview parts:

| Item | Qty | Notes |
|---|---:|---|
| `LM324` quad op-amp DIP-14 | 1 | gain, buffering, simple active filtering |
| `LM339` quad comparator DIP-14 | 1 | converts analog levels into stable TTL-style threshold outputs |
| `DIP-14` wire-wrap socket | 2 | one each for `LM324` and `LM339` |
| photoresistor or photodiode | 1 to 2 | light input source |
| electret microphone capsule | 1 | sound input source |
| microphone bias resistor `2.2k` to `10k` | 1 to 2 | microphone front-end bias |
| resistor assortment | small set | `1k`, `10k`, `47k`, `100k`, `1M` for gain, dividers, pull-ups, hysteresis |
| trimmer potentiometer `10k` or `100k` | 2 | adjustable thresholds for light and sound channels |
| capacitor assortment | small set | `1nF`, `10nF`, `100nF`, `1uF` for coupling, filtering, and timing |
| `0.1uF` ceramic decoupling capacitors | 2 | local supply bypass, one per IC minimum |
| `1N4148` small-signal diodes | 2 to 4 | optional input clamp or envelope shaping |
| LED plus series resistor | 2 | one activity or threshold LED per preview channel |
| test posts or header pins | 4 to 8 | expose analog node, comparator output, and ground |

Light-sensing preview path:

1. sensor divider using photoresistor or photodiode
2. optional `LM324` gain or buffering stage
3. `LM339` threshold stage with adjustable hysteresis
4. logic-level output to a spare Rodney input bit or a test LED

Sound-sensing preview path:

1. electret microphone with bias resistor
2. AC-coupled `LM324` gain stage
3. optional envelope or low-pass shaping
4. `LM339` threshold stage with adjustable trip level
5. logic-level output to a spare Rodney input bit or a test LED

Preview intent:

- prove that Rodney can accept conditioned non-switch inputs
- keep analog work off the baseline digital boards until thresholds are understood
- reduce risk by treating light and sound sensing as an external bench module first

## Preferred Part Strategy

- Use genuine or tested `8085A` parts.
- Use `LS` TTL where timing compatibility matters.
- Use `LS` parts throughout this build; no `HCT` substitutions are planned.
- Use new-old-stock or modern SRAM in DIP packages to reduce the chip count.
- Do not optimize for historical purity on the first wire-wrap pass.

## Software Expectations

The software stack should be brought up in this order:

1. RAM test and bus test
2. simple monitor or loader
3. Alpha behavior
4. Beta confidence update loop
5. Gamma generalization

The assembly should abstract hardware with symbols for:

- `ENVL`
- `ENVH`
- `ACTL`
- `ACTH`
- `TSWR`
- `MMAL`
- `MMAH`
- `MMDL`

## Risks

- Wire-wrap density around the memory board can get messy quickly.
- Clock and reset faults will masquerade as software faults.
- Using too many historical small RAM chips will multiply failure points.
- Gamma verification is behavioral, so poor observability will slow debugging.
- Bench-first validation is essential before motors or charging hardware are added.

## Acceptance Criteria

The build is successful when it can:

1. execute a RAM-resident 8085 program reliably after repeated resets
2. read bench `ENVL` inputs and drive `ACTL` LEDs
3. store learned response bytes in main memory
4. increment and decrement confidence
5. trigger Gamma on confidence transitions
6. write generalized responses back into low-confidence entries

## Recommended Next Artifacts

- board-to-board signal list
- address decode truth table
- wire-wrap placement plan per board
- symbolic 8085 hardware include file
- Gamma-oriented bench test plan

## File Placement

This spec is intentionally high-level enough to guide:

- schematic capture later
- wire-wrap placement drawings
- source code porting of Beta/Gamma routines
- purchasing and staging of parts

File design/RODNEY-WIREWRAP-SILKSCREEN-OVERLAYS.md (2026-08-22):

# Rodney Wire-Wrap Silkscreen Overlays

These overlays place the Rodney board partitions directly onto the actual `Vector 8801-6` board image from [design/vector-8801-6.gif](/home/cartheur/ame/aiventure/aiventure-github/cartheur/aiventure-rodney/design/vector-8801-6.gif:1).

Use this set when you want a **silkscreen-like placement aid** for laying out wire-wrap sockets on the real board format.

## Files

- [Blank placement reference JPG](/home/cartheur/ame/aiventure/aiventure-github/cartheur/aiventure-rodney/diagrams/Vector8801-6-placement-reference.jpg)
- [Board A silkscreen JPG](/home/cartheur/ame/aiventure/aiventure-github/cartheur/aiventure-rodney/diagrams/RodneyBoardA-silkscreen.jpg)
- [Board B silkscreen JPG](/home/cartheur/ame/aiventure/aiventure-github/cartheur/aiventure-rodney/diagrams/RodneyBoardB-silkscreen.jpg)
- [Board C silkscreen JPG](/home/cartheur/ame/aiventure/aiventure-github/cartheur/aiventure-rodney/diagrams/RodneyBoardC-silkscreen.jpg)

## Legend

- White rounded outline: socket or placement body
- Yellow dot: `pin 1`
- Top numeric labels: `X` hole coordinates
- Left labels: `Y` hole coordinates
- Labels inside each block: part name and `pin1 X/Y`

## Notes

- These overlays use the same placement coordinates as [RODNEY-WIREWRAP-COORDINATE-WORKSHEET.md](/home/cartheur/ame/aiventure/aiventure-github/cartheur/aiventure-rodney/design/RODNEY-WIREWRAP-COORDINATE-WORKSHEET.md:1).
- The mapping is tuned to the actual board photo in the repo, not to a fresh vector trace.
- It is intended for fast socket placement and visual sanity-checking, not for archival-faithful reconstruction of factory legends.
- For the current memory-board plan, treat `Board B U1`, `U7`, and `U8` as **ZIF clearance zones** if using `3 x 28-pin ZIFs`.

## Regeneration

Run:

```bash
python3 diagrams/render_rodney_silkscreen_overlays.py
```

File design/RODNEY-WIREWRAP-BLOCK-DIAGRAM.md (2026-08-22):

# Rodney Wire-Wrap Block Diagram

Block-based layout sketch for the `3 x Vector 8801-6` bench-first Rodney build.

This is intentionally coarse. It is meant to help us iterate on:

- board partitioning
- major chip grouping
- bus flow
- operator access

before we commit to exact socket coordinates.

Companion docs:

- [RODNEY-WIREWRAP-DESIGN-SPEC.md](/home/cartheur/ame/aiventure/aiventure-github/cartheur/aiventure-rodney/design/RODNEY-WIREWRAP-DESIGN-SPEC.md:1)
- [RODNEY-WIREWRAP-SIGNAL-LIST.md](/home/cartheur/ame/aiventure/aiventure-github/cartheur/aiventure-rodney/design/RODNEY-WIREWRAP-SIGNAL-LIST.md:1)
- [RODNEY-WIREWRAP-DECODE-TABLE.md](/home/cartheur/ame/aiventure/aiventure-github/cartheur/aiventure-rodney/design/RODNEY-WIREWRAP-DECODE-TABLE.md:1)
- [RODNEY-WIREWRAP-PLACEMENT-PLAN.md](/home/cartheur/ame/aiventure/aiventure-github/cartheur/aiventure-rodney/design/RODNEY-WIREWRAP-PLACEMENT-PLAN.md:1)

## Overall Stack

```text
                      Rodney Wire-Wrap Stack

         +-------------------+     +-------------------+
         |   Board A         |====>|   Board B         |
         |   CPU / Bus       |====>|   Memory / Decode |
         +-------------------+     +-------------------+
                  ||
                  || shared address / data / control
                  \/
         +-------------------+
         |   Board C         |
         |   Bench I/O       |
         +-------------------+
```

## Bus-Level Functional Diagram

```text
   +---------+    +-------------+    +-------------+    +-------------+
   | 8085A   |--->| Addr Latch  |--->| Memory Bd   |<-->| Main Memory |
   | CPU     |    | 74LS373     |    | Decode      |    | + MMA/MMD   |
   +---------+    +-------------+    +-------------+    +-------------+
        |                 |
        |                 +-------------------------------+
        |                                                 |
        v                                                 v
   +-------------+                                 +-------------+
   | Data Buffer |<------------------------------->| Bench I/O   |
   | 74LS245     |                                 | ENVL/ACTL   |
   +-------------+                                 | TSWR/LEDs   |
                                                   +-------------+
```

## Vector 8801-6 Orientation

Assumed orientation for all three boards:

```text
        Top edge
   +--------------------------------------+
   |                                      |
   |         component area               |
   |                                      |
   |                                      |
   +--------------------------------------+
   | 100-pin edge connector / backplane   |
   +--------------------------------------+
        Bottom edge
```

## Board A: CPU / Bus Board

```text
        Top edge
   +------------------------------------------------------+
   | [TP CLK] [TP ALE] [TP RD] [TP WR] [TP IO/M] [RESET]  |
   |                                                      |
   | [XTAL] [74LS04]                         [74LS138]    |
   |                                                      |
   | [74LS373]           [8085A CPU]        [74LS245]    |
   |                                                      |
   | [PWR BULK]                            [BUS HEADER]   |
   +------------------------------------------------------+
   |                edge connector / bus out              |
   +------------------------------------------------------+
        Bottom edge
```

### Board A Intent

- `8085A` stays central.
- `74LS373` stays physically close to the multiplexed low bus.
- `74LS245` sits on the shared data side.
- clock/reset parts stay away from dense LED or switch wiring.
- test points stay on the top edge for probing.

## Board B: Memory / Decode Board

```text
        Top edge
   +------------------------------------------------------+
   | [TP PRG] [TP ROM] [TP MMA-L] [TP MMA-H] [TP MMD]    |
   |                                                      |
   |                 [62256 MAIN MEMORY]                  |
   |                                                      |
   | [74LS138] [74LS139]   [MMA LATCHES]   [MMD PATH]    |
   |                                                      |
   | [6264 PROGRAM RAM]        [EEPROM / MONITOR ROM]    |
   |                                                      |
   | [PWR BULK]                            [BUS HEADER]   |
   +------------------------------------------------------+
   |                edge connector / bus in               |
   +------------------------------------------------------+
        Bottom edge
```

### Board B Intent

- decode sits between the incoming bus and the memory devices.
- `62256` is the dominant block because it holds learned state.
- `6264` and EEPROM stay lower and easier to isolate during bring-up.
- `MMA` and `MMD` blocks stay close to main memory because they are the self-programming path.

## Board C: Bench I/O Board

```text
        Top edge
   +------------------------------------------------------+
   | [TP ENVL] [TP TSWR] [TP ACTL]   [MODE/JUMPERS]      |
   |                                                      |
   | [TSWR LFSR]                         [DEBUG LEDs]     |
   |                                                      |
   | [ENVL DIP] [INPUT BUF] [OUTPUT LATCH] [ACTL LEDs]   |
   |                                                      |
   | [ENVH DIP] [LOCAL DECODE]            [ACTH LEDs]    |
   |                                                      |
   | [PWR BULK]                            [BUS HEADER]   |
   +------------------------------------------------------+
   |                edge connector / bus in               |
   +------------------------------------------------------+
        Bottom edge
```

### Board C Intent

- switches stay human-accessible.
- LEDs stay readable during debugging.
- the random source is visible and isolated from the switch area.
- decode stays local to the register functions on this board.

## Inter-Board Wiring View

```text
                      Address A0-A15
                +------------------------+
                |                        |
                v                        v
   +-------------------+         +-------------------+
   | Board A           |         | Board B           |
   | CPU / Bus         |-------->| Memory / Decode   |
   |                   |         |                   |
   | D0-D7 <---------->|---------| D0-D7             |
   | RD WR IO/M ------>|---------| control in        |
   +-------------------+         +-------------------+
                |
                | Address / Data / Control
                v
   +-------------------+
   | Board C           |
   | Bench I/O         |
   | ENVL / TSWR /     |
   | ACTL / LEDs       |
   +-------------------+
```

## Self-Programming Path

This is the path we care most about for Rodney-specific behavior:

```text
 ENVL switches/sensors
        |
        v
   +-----------+
   |  CPU      |
   | 8085A     |
   +-----------+
        |
        | choose learned-state address
        v
   +-----------+        +-----------+
   | MMA low   |------->|           |
   | MMA high  |------->| 62256     |
   +-----------+        | Main Mem  |
        ^               |           |
        |               +-----------+
        |                    |
        |                learned byte
        |                    v
        |               +-----------+
        +---------------| MMD path  |
                        +-----------+
                              |
                              v
                           ACTL LEDs
```

## Suggested Iteration Questions

Before moving to coordinates, these are the right questions to answer:

- Is `3-board` partitioning still the right split?
- Do we want the EEPROM on `Board B`, or should it move to `Board A`?
- Do we want `ENVH` populated on revision 1, or leave the footprint only?
- Do we want a direct debug header for the `MMA` and `MMD` path?
- Do we want the random source on `Board C`, or fold it into `Board B`?

## Next Step After Approval

If this block diagram feels right, the next artifact should be a **socket-level coordinate worksheet** for each board, not yet a full schematic.

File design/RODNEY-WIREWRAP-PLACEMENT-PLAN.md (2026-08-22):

# Rodney Wire-Wrap Placement Plan

Suggested physical placement plan for a `3-board Vector 8801-6` wire-wrap Rodney core.

Board dimensions come from [design/README.md](/home/cartheur/ame/aiventure/aiventure-github/cartheur/aiventure-rodney/design/README.md:1): `10.5" x 5.3"` `Vector 8801-6`.

This plan is meant to reduce wrap density and make probing practical. It is not a photographic reconstruction of the original Rodney boards.

## Orientation Convention

For each board in this document:

- `edge connector` is at the bottom
- `top` means the board edge opposite the connector
- `left` and `right` are as viewed from the component side

## Rack Order

Recommended left-to-right or front-to-back logical order:

1. `Board A` CPU
2. `Board B` memory
3. `Board C` I/O

Reason:

- CPU sits centrally in the logical design.
- Memory gets shortest heavy bus usage.
- I/O board stays accessible for switches, LEDs, and observation.

## Global Placement Rules

- Put bus-facing devices nearest the connector side.
- Put human-facing devices nearest the outer edges.
- Keep oscillators and reset circuitry away from dense LED wiring.
- Put decoders near the middle of the board, not at the extremes.
- Reserve one full vertical lane on each board for power distribution.
- Reserve one header strip per board for debug posts.

## Board A: CPU and Bus Support

## Primary Functions

- `8085A`
- address latch
- bus transceiver
- reset
- clock
- bus export headers

## Recommended Zones

### Bottom zone, near edge connector

- board interconnect headers
- power entry
- main bus breakout points

Reason:

- shortest path from connector to bus spine

### Center zone

- `8085A`

Reason:

- centralizes fan-out to address, data, and control lines

### Upper-left zone

- `74LS373` address latch

Reason:

- very short runs from `AD0-AD7` and `ALE`

### Upper-right zone

- `74LS245`
- `74LS138`

Reason:

- keeps bus and coarse decode grouped

### Far-right or top edge

- crystal
- load capacitors
- `74LS04` clock/reset glue
- reset pushbutton

Reason:

- keep oscillator physically separate from wider bus bundles and LED noise

### Top edge

- test posts for:
  - `CLK`
  - `ALE`
  - `/RD`
  - `/WR`
  - `IO/M`
  - `/RESET_OUT`

## Board A Placement Sketch

```text
Top
+--------------------------------------------------+
| TP TP TP TP TP TP   XTAL RESET   74LS04         |
|                                                  |
| 74LS373                8085A             74LS245 |
|                                                  |
|                           74LS138               |
|                                                  |
| PWR lane                            BUS headers  |
|                                                  |
| Edge connector / board-to-board breakout         |
+--------------------------------------------------+
Bottom
```

## Board B: Memory and Decode

## Primary Functions

- program RAM
- EEPROM
- main memory
- MMA low latch
- MMA high latch
- MMD path
- memory decode

## Recommended Zones

### Bottom zone

- incoming bus header from `Board A`
- outgoing service header if needed

### Center-left

- `6264` program RAM

### Center-right

- EEPROM / monitor ROM

### Upper center

- `62256` main memory

Reason:

- main memory is the board’s focal device and should get the clearest routing

### Left-middle

- `74LS138` and `74LS139`

Reason:

- decode should sit between bus ingress and the controlled devices

### Right-middle

- `MMA low` and `MMA high` latches
- optional MMD gating transceiver or latch

Reason:

- these form the indirect access path to main memory and should sit close to the `62256`

### Top edge

- test posts:
  - `/PRG_RAM_CS`
  - `/ROM_CS`
  - `/MMA_L_CS`
  - `/MMA_H_CS`
  - `/MMD_CS`
  - `MMA0`
  - `MMA8`
  - `D0`

## Board B Placement Sketch

```text
Top
+--------------------------------------------------+
| TP TP TP TP TP TP TP TP                          |
|                                                  |
|                  62256 MAIN MEMORY               |
|                                                  |
| 74LS138 74LS139     MMA L/H      MMD GATE        |
|                                                  |
| 6264 PROGRAM RAM           EEPROM / MONITOR      |
|                                                  |
| PWR lane                            BUS lane      |
|                                                  |
| Edge connector / bus in                          |
+--------------------------------------------------+
Bottom
```

## Board C: Bench I/O and Observability

## Primary Functions

- `ENVL` switch input
- optional `ENVH` switch input
- `TSWR` pseudo-random source
- `ACTL` LED output
- optional `ACTH`
- bench status indicators

## Recommended Zones

### Bottom zone

- bus ingress from `Board A`
- decode header

### Left side

- DIP switch packs for `ENVL`
- optional second pack for `ENVH`

Reason:

- easy operator access

### Center

- input buffer
- output latch
- local decode

### Right side

- LED row for `ACTL`
- second LED row for debug or `ACTH`

Reason:

- direct visual observation during Beta/Gamma runs

### Upper center

- `TSWR` pseudo-random source

Reason:

- keeps it distinct from manual switch inputs

### Top edge

- debug posts
- optional mode jumpers

## Board C Placement Sketch

```text
Top
+--------------------------------------------------+
| TP TP TP TP      TSWR / LFSR        MODE JUMPERS |
|                                                  |
| ENVL SW1      INPUT BUF   OUTPUT LATCH   ACTL LEDs|
|                                                  |
| ENVH SW2      LOCAL DECODE              DBG LEDs |
|                                                  |
| PWR lane                            BUS lane      |
|                                                  |
| Edge connector / bus in                          |
+--------------------------------------------------+
Bottom
```

## Power Routing Plan

On every board:

- one vertical `+5V` rail lane
- one vertical `GND` rail lane
- local decoupling at every IC
- one bulk capacitor close to power entry

Preferred color convention:

- red: `+5V`
- black: `GND`
- blue: data bus
- yellow: address bus
- green: control
- white: local board signals

## Wrap Density Guidance

## Board A

Highest-risk areas:

- around `8085A`
- around `74LS373`
- around `74LS245`

Mitigation:

- orient `74LS373` and `74LS245` so their bus-side pins face the CPU
- keep decode outputs pointed away from the bus spine

## Board B

Highest-risk areas:

- `62256` plus `MMA` latches
- decode fan-out

Mitigation:

- place `MMA` latches directly adjacent to the main-memory address side
- keep program RAM and EEPROM on the opposite side of the board from `MMD` path logic

## Board C

Highest-risk areas:

- LED resistor wiring
- switch pull networks

Mitigation:

- use resistor networks where possible
- keep LED wiring to one edge to avoid crossing the data bus repeatedly

## Serviceability Rules

- leave at least one empty hole row between major DIP packages where practical
- place all sockets in the same orientation per board unless routing strongly argues otherwise
- never bury reset or clock parts under dense wrap bundles
- leave enough space near test points for clip probes

## Suggested Build Sequence By Board

### Board A

1. sockets
2. power and ground
3. reset and clock
4. CPU-to-latch wiring
5. CPU-to-transceiver wiring
6. export bus headers

### Board B

1. sockets
2. power and ground
3. decode
4. program RAM and ROM
5. MMA latches
6. main memory path

### Board C

1. sockets
2. power and ground
3. input switches
4. output LEDs
5. random source
6. local decode

## Mechanical Fit Notes

Using the repo’s rack assumptions:

- allow generous side access for wrap tool rotation
- keep the I/O board on the most accessible side of the rack
- avoid placing frequently changed jumpers toward the rack interior

## Recommended Next Step

Translate this plan into a per-board hole-grid worksheet before starting wrap. A simple coordinate sheet with socket origins will prevent a lot of rework.

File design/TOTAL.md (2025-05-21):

# PLA Filament Requirement for All 3D Printed Robot Parts

This document clarifies the scope of the previous PLA filament estimate and provides a revised calculation for the total amount of 1.75 mm PLA filament required to 3D print all parts of the robot, including the circular bottom plate, skirt, card rack assembly, rack mounts, and wheels. The calculations use a 20% infill, 3 perimeter shells, 4 top/bottom layers, and PLA material properties.

## Clarification of Previous Estimate

The previous estimate focused **only on the circular bottom plate and the attached skirt**:
- **Circular Plate (Bottom Plate)**:
  - Two thickness options: 0.5 inches (12.7 mm) and 0.75 inches (19.05 mm).
- **Skirt**:
  - Height: 2 inches (50.8 mm), Thickness: 0.25 inches (6.35 mm).
- **Filament Usage** (20% infill, 3 shells at 0.4 mm each, 4 top/bottom layers at 0.2 mm each):
  - **Design 1 (0.5-inch thick plate)**: 890.71 cm³, or 370.31 meters of 1.75 mm filament.
  - **Design 2 (0.75-inch thick plate)**: 1,116.26 cm³, or 464.24 meters of 1.75 mm filament.

This estimate did **not** include the card rack assembly, rack mounts, or wheels, as the focus was on the circular plate and skirt in the context of structural analysis and material requirements for that specific component.

## Revised Estimate: Including All Parts

Below is the total PLA filament required for all 3D printed parts of the robot, using the same assumptions:
- **Material**: PLA (density: 1.24 g/cm³).
- **Filament**: 1.75 mm diameter (mass per unit length = 2.982 g/m).
- **Infill**: 20% for all parts.
- **Shells**: 3 perimeters (1.2 mm total thickness).
- **Top/Bottom Layers**: 4 layers per side (0.8 mm total per side).

### 1. Circular Plate + Skirt (Recap)

- **Design 1 (0.5-inch thick plate)**: 890.71 cm³ (370.31 m).
- **Design 2 (0.75-inch thick plate)**: 1,116.26 cm³ (464.24 m).

### 2. Card Rack Assembly

- **Dimensions**:
  - Overall: 11 inches × 11 inches × 13 inches (279.4 mm × 279.4 mm × 330.2 mm).
- **Components**:
  - **Vertical Supports**: 4 beams, each 12.7 mm × 12.7 mm × 330.2 mm.
  - **Top/Bottom Frames**: 2 frames, each 279.4 mm × 279.4 mm with a 12.7 mm thick border (inner dimensions 253.9 mm × 253.9 mm).
  - **Shelves**: 2 shelves, each 279.4 mm × 279.4 mm × 6.35 mm.
- **Volume**:
  - **Vertical Supports**:
    - Volume per support = 12.7 mm × 12.7 mm × 330.2 mm = 53,239.3 mm³ = 53.24 cm³.
    - Total for 4 supports = 4 × 53.24 cm³ = 212.96 cm³.
  - **Top/Bottom Frames**:
    - Outer Area = 279.4 mm × 279.4 mm = 78,064.4 mm².
    - Inner Area = 253.9 mm × 253.9 mm = 64,465.2 mm².
    - Frame Area = 78,064.4 mm² - 64,465.2 mm² = 13,599.2 mm².
    - Volume per frame = 13,599.2 mm² × 12.7 mm = 172,709.8 mm³ = 172.71 cm³.
    - Total for 2 frames = 2 × 172.71 cm³ = 345.42 cm³.
  - **Shelves**:
    - Area = 78,064.4 mm².
    - Volume per shelf = 78,064.4 mm² × 6.35 mm = 495,709.0 mm³ = 495.71 cm³.
    - Total for 2 shelves = 2 × 495.71 cm³ = 991.42 cm³.
- **Total Volume (Solid)**:
  - Total = 212.96 cm³ + 345.42 cm³ + 991.42 cm³ = 1,549.80 cm³.
- **Shells and Top/Bottom Layers**:
  - **Shells** (3 shells, 1.2 mm thick):
    - Perimeter (approximate as a square) = 4 × 279.4 mm = 1,117.6 mm.
    - Height = 330.2 mm.
    - Outer Shell Volume = 1,117.6 mm × 330.2 mm × 1.2 mm = 442,833.8 mm³ = 442.83 cm³.
    - Inner Shell Volume (inner perimeter ≈ 4 × 253.9 mm = 1,015.6 mm) = 1,015.6 mm × 330.2 mm × 1.2 mm = 402,464.6 mm³ = 402.46 cm³.
  - **Top/Bottom Layers** (4 layers, 0.8 mm per side):
    - Area = 78,064.4 mm².
    - Volume per side = 78,064.4 mm² × 0.8 mm = 62,451.5 mm³ = 62.45 cm³.
    - Total = 62.45 cm³ × 2 = 124.90 cm³.
  - **Shelves (Top/Bottom Layers)**:
    - Each shelf: 2 shelves × 2 × 62.45 cm³ = 249.80 cm³.
- **Infill Volume**:
  - Total Volume = 1,549.80 cm³.
  - Subtract shells and top/bottom: 1,549.80 cm³ - (442.83 cm³ + 402.46 cm³ + 124.90 cm³ + 249.80 cm³) = 329.81 cm³.
  - Infill Volume = 0.2 × 329.81 cm³ = 65.96 cm³.
- **Total PLA Volume for Rack**:
  - Total = 442.83 cm³ + 402.46 cm³ + 124.90 cm³ + 249.80 cm³ + 65.96 cm³ = 1,285.95 cm³.

### 3. Rack Mounts

- **Dimensions**:
  - 4 L-shaped brackets, each leg 50.8 mm × 50.8 mm, thickness 12.7 mm, height 25.4 mm.
- **Volume**:
  - Volume per bracket (approximate as two prisms, subtract overlap):
    - Each leg = 50.8 mm × 12.7 mm × 25.4 mm = 16,388.5 mm³ = 16.39 cm³.
    - Total per bracket = 2 × 16.39 cm³ - (12.7 mm × 12.7 mm × 25.4 mm) = 32.78 cm³ - 4.10 cm³ = 28.68 cm³.
    - Total for 4 brackets = 4 × 28.68 cm³ = 114.72 cm³.
- **Shells** (3 shells, 1.2 mm thick):
  - Perimeter (L-shape) = 2 × (50.8 mm + 25.4 mm) = 152.4 mm.
  - Height = 12.7 mm.
  - Outer Shell Volume per bracket = 152.4 mm × 12.7 mm × 1.2 mm = 2,322.6 mm³ = 2.32 cm³.
  - Inner Shell Volume (inner perimeter ≈ 2 × (50.8 - 2.4) + 2 × (25.4 - 2.4) = 142.8 mm) = 142.8 mm × 12.7 mm × 1.2 mm = 2,176.5 mm³ = 2.18 cm³.
  - Total Shells for 4 brackets = 4 × (2.32 cm³ + 2.18 cm³) = 18.00 cm³.
- **Top/Bottom Layers**:
  - Area per bracket = 50.8 mm × 50.8 mm = 2,580.6 mm².
  - Volume per side = 2,580.6 mm² × 0.8 mm = 2,064.5 mm³ = 2.06 cm³.
  - Total for 4 brackets = 4 × 2 × 2.06 cm³ = 16.48 cm³.
- **Infill Volume**:
  - Total Volume = 114.72 cm³.
  - Subtract shells and top/bottom: 114.72 cm³ - (18.00 cm³ + 16.48 cm³) = 80.24 cm³.
  - Infill Volume = 0.2 × 80.24 cm³ = 16.05 cm³.
- **Total PLA Volume for Rack Mounts**:
  - Total = 18.00 cm³ + 16.48 cm³ + 16.05 cm³ = 50.53 cm³.

### 4. Wheels

- **Dimensions**:
  - 4 wheels, each 3.5 inches (88.9 mm) in diameter, 1 inch (25.4 mm) wide.
- **Volume**:
  - Volume per wheel = π × (44.45 mm)² × 25.4 mm = 157,697.6 mm³ = 157.70 cm³.
  - Total for 4 wheels = 4 × 157.70 cm³ = 630.80 cm³.
- **Shells**:
  - Outer circumference = π × 88.9 mm = 279.3 mm.
  - Height = 25.4 mm.
  - Outer Shell Volume per wheel = 279.3 mm × 25.4 mm × 1.2 mm = 8,514.2 mm³ = 8.51 cm³.
  - Inner Shell Volume (inner diameter ≈ 86.5 mm, circumference = 271.7 mm) = 271.7 mm × 25.4 mm × 1.2 mm = 8,281.9 mm³ = 8.28 cm³.
  - Total Shells for 4 wheels = 4 × (8.51 cm³ + 8.28 cm³) = 67.16 cm³.
- **Top/Bottom Layers**:
  - Area per wheel = π × (44.45 mm)² = 6,202.2 mm².
  - Volume per side = 6,202.2 mm² × 0.8 mm = 4,961.8 mm³ = 4.96 cm³.
  - Total for 4 wheels = 4 × 2 × 4.96 cm³ = 39.68 cm³.
- **Infill Volume**:
  - Total Volume = 630.80 cm³.
  - Subtract shells and top/bottom: 630.80 cm³ - (67.16 cm³ + 39.68 cm³) = 523.96 cm³.
  - Infill Volume = 0.2 × 523.96 cm³ = 104.79 cm³.
- **Total PLA Volume for Wheels**:
  - Total = 67.16 cm³ + 39.68 cm³ + 104.79 cm³ = 211.63 cm³.

### 5. Total PLA for All Parts

- **Design 1 (0.5-inch thick plate)**:
  - Plate + Skirt: 890.71 cm³.
  - Card Rack Assembly: 1,285.95 cm³.
  - Rack Mounts: 50.53 cm³.
  - Wheels: 211.63 cm³.
  - **Total Volume** = 890.71 cm³ + 1,285.95 cm³ + 50.53 cm³ + 211.63 cm³ = 2,438.82 cm³.
  - **Mass** = 2,438.82 cm³ × 1.24 g/cm³ = 3,024.14 g.
  - **Filament Length** = 3,024.14 g / 2.982 g/m = 1,013.93 m.
- **Design 2 (0.75-inch thick plate)**:
  - Plate + Skirt: 1,116.26 cm³.
  - Card Rack Assembly: 1,285.95 cm³.
  - Rack Mounts: 50.53 cm³.
  - Wheels: 211.63 cm³.
  - **Total Volume** = 1,116.26 cm³ + 1,285.95 cm³ + 50.53 cm³ + 211.63 cm³ = 2,664.37 cm³.
  - **Mass** = 2,664.37 cm³ × 1.24 g/cm³ = 3,303.82 g.
  - **Filament Length** = 3,303.82 g / 2.982 g/m = 1,107.86 m.

## Final Answer

- **Design 1 (0.5-inch thick plate)**:
  - Total PLA Required for All Parts: **2,438.82 cm³**, equivalent to **1,013.93 meters** of 1.75 mm filament (~3.02 kg, or ~3.1 spools of 1 kg filament).
- **Design 2 (0.75-inch thick plate)**:
  - Total PLA Required for All Parts: **2,664.37 cm³**, equivalent to **1,107.86 meters** of 1.75 mm filament (~3.30 kg, or ~3.3 spools of 1 kg filament).

## Notes

- The previous estimate (370.31 m for Design 1, 464.24 m for Design 2) only included the circular plate and skirt, confirming that it did not account for the card rack, mounts, and wheels.
- A standard 1 kg spool of PLA filament is ~330 meters (for 1.75 mm filament). Design 1 requires ~3.1 spools, and Design 2 requires ~3.3 spools. Add 10-20% extra filament for waste, supports, or failed prints.
- The parts are designed to be printed separately (e.g., plate in quadrants, rack components, etc.), so filament usage can be distributed across multiple print jobs.

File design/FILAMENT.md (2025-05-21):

# PLA Filament Requirement for Circular Plate Designs

This document calculates the amount of PLA filament (1.75 mm diameter) required to 3D print the circular bottom plate and skirt of a robot, considering two design options for the plate's thickness: 0.5 inches and 0.75 inches. The calculation accounts for the volume of material, infill percentage, and typical 3D printing settings.

## Design Specifications

- **Circular Plate (Bottom Plate)**:
  - Diameter: 18 inches (457.2 mm).
  - Thickness Options:
    - Design 1: 0.5 inches (12.7 mm).
    - Design 2: 0.75 inches (19.05 mm, recommended for a higher safety factor).
- **Skirt** (attached to the plate):
  - Outer Diameter: 18 inches (457.2 mm).
  - Height: 2 inches (50.8 mm).
  - Thickness: 0.25 inches (6.35 mm).
- **Material**: PLA.
  - **Density**: 1.24 g/cm³ (1240 kg/m³).
- **Filament**: 1.75 mm diameter PLA filament.
  - Cross-sectional area = π × (0.875 mm)² = 2.405 mm².
  - Mass per unit length = 2.405 mm² × 1 mm × 1.24 g/cm³ = 0.002982 g/mm = 2.982 g/m.
- **Infill Percentage**: 20% infill for the plate and skirt (common for structural parts). Outer shells and top/bottom layers are solid (100% infill).

## Step 1: Volume of the Circular Plate and Skirt

### Circular Plate (Bottom Plate)

- **Area of the Plate**:
  - Radius = 457.2 mm / 2 = 228.6 mm.
  - Area = π × (228.6 mm)² = 164,021.7 mm².
- **Volume for Design 1 (0.5 inches = 12.7 mm thick)**:
  - Volume = 164,021.7 mm² × 12.7 mm = 2,083,075.6 mm³ = 2,083.08 cm³.
- **Volume for Design 2 (0.75 inches = 19.05 mm thick)**:
  - Volume = 164,021.7 mm² × 19.05 mm = 3,124,613.4 mm³ = 3,124.61 cm³.

### Skirt

- **Dimensions**:
  - Outer Diameter: 457.2 mm (radius = 228.6 mm).
  - Inner Diameter: 457.2 mm - 2 × 6.35 mm = 444.5 mm (inner radius = 222.25 mm).
  - Height: 50.8 mm.
- **Volume**:
  - Outer Area = π × (228.6 mm)² = 164,021.7 mm².
  - Inner Area = π × (222.25 mm)² = 155,026.7 mm².
  - Cross-sectional Area = 164,021.7 mm² - 155,026.7 mm² = 8,995 mm².
  - Volume = 8,995 mm² × 50.8 mm = 456,946 mm³ = 456.95 cm³.

### Total Volume (Plate + Skirt)

- **Design 1 (0.5-inch thick plate)**:
  - Total Volume = 2,083.08 cm³ + 456.95 cm³ = 2,540.03 cm³.
- **Design 2 (0.75-inch thick plate)**:
  - Total Volume = 3,124.61 cm³ + 456.95 cm³ = 3,581.56 cm³.

## Step 2: Adjust for Infill and Shells

In 3D printing, the part has an infill structure (20% infill) with solid outer shells and top/bottom layers. Let’s calculate the effective PLA volume.

### Shells and Top/Bottom Layers

- **Shells (Outer Walls)**:
  - Assume 3 perimeter shells (wall thickness = 0.4 mm per shell, so 3 shells = 1.2 mm).
  - **Outer Shell Volume**:
    - Outer circumference = π × 457.2 mm = 1,436.5 mm.
    - Height (Design 1) = 50.8 mm + 12.7 mm = 63.5 mm.
    - Height (Design 2) = 50.8 mm + 19.05 mm = 69.85 mm.
    - Volume (Design 1) = 1,436.5 mm × 63.5 mm × 1.2 mm = 109,471.5 mm³ = 109.47 cm³.
    - Volume (Design 2) = 1,436.5 mm × 69.85 mm × 1.2 mm = 120,409.7 mm³ = 120.41 cm³.
  - **Inner Shell Volume** (inside the skirt):
    - Inner circumference = π × 444.5 mm = 1,396.9 mm.
    - Volume (Design 1) = 1,396.9 mm × 63.5 mm × 1.2 mm = 106,466.6 mm³ = 106.47 cm³.
    - Volume (Design 2) = 1,396.9 mm × 69.85 mm × 1.2 mm = 117,084.2 mm³ = 117.08 cm³.
- **Top and Bottom Layers**:
  - Assume 4 solid layers (0.2 mm per layer, so 4 × 0.2 mm = 0.8 mm per side).
  - Top/Bottom Area = 164,021.7 mm².
  - Volume per side = 164,021.7 mm² × 0.8 mm = 131,217.4 mm³ = 131.22 cm³.
  - Total Top + Bottom = 131.22 cm³ × 2 = 262.44 cm³ (same for both designs).

### Infill Volume

- **Infill Percentage**: 20%.
- **Design 1**:
  - Total Volume = 2,540.03 cm³.
  - Subtract shells and top/bottom: 2,540.03 cm³ - (109.47 cm³ + 106.47 cm³ + 262.44 cm³) = 2,061.65 cm³.
  - Infill Volume = 0.2 × 2,061.65 cm³ = 412.33 cm³.
- **Design 2**:
  - Total Volume = 3,581.56 cm³.
  - Subtract shells and top/bottom: 3,581.56 cm³ - (120.41 cm³ + 117.08 cm³ + 262.44 cm³) = 3,081.63 cm³.
  - Infill Volume = 0.2 × 3,081.63 cm³ = 616.33 cm³.

### Total PLA Volume (Shells + Top/Bottom + Infill)

- **Design 1**:
  - Total = 109.47 cm³ + 106.47 cm³ + 262.44 cm³ + 412.33 cm³ = 890.71 cm³.
- **Design 2**:
  - Total = 120.41 cm³ + 117.08 cm³ + 262.44 cm³ + 616.33 cm³ = 1,116.26 cm³.

## Step 3: Convert Volume to Filament Length

- **Mass of PLA**:
  - Density = 1.24 g/cm³.
  - **Design 1**: Mass = 890.71 cm³ × 1.24 g/cm³ = 1,104.48 g.
  - **Design 2**: Mass = 1,116.26 cm³ × 1.24 g/cm³ = 1,384.16 g.
- **Filament Length**:
  - Mass per meter of 1.75 mm filament = 2.982 g/m.
  - **Design 1**: Length = 1,104.48 g / 2.982 g/m = 370.31 m.
  - **Design 2**: Length = 1,384.16 g / 2.982 g/m = 464.24 m.

## Final Answer

- **Design 1 (0.5-inch thick plate)**:
  - PLA Required: **890.71 cm³**, equivalent to **370.31 meters** of 1.75 mm filament.
- **Design 2 (0.75-inch thick plate)**:
  - PLA Required: **1,116.26 cm³**, equivalent to **464.24 meters** of 1.75 mm filament.

Be aware that A 1 kg spool of 1.75 mm PLA filament contains approximately 335.14 meters of filament.

## Notes

- **Accuracy**: This assumes 20% infill, 3 perimeter shells, and 4 top/bottom layers. Adjusting these settings (e.g., infill percentage, shell count, layer height) will change filament usage.
- **Practical Considerations**:
  - A standard 1 kg spool of PLA filament is ~330 meters (for 1.75 mm filament).
  - **Design 1** requires slightly more than one spool (~1.12 spools).
  - **Design 2** requires about 1.4 spools.
  - Account for potential waste (e.g., failed prints, support material) by adding 10-20% extra filament.
- **Splitting the Plate**: The 18-inch diameter plate is too large for most 3D printers, so it’s designed to be printed in 4 quadrants. Filament usage per quadrant is roughly 1/4 of the total, plus a small amount for connectors (e.g., dovetail joints or screw holes).

This estimate provides the material requirements for printing the circular plate and skirt for both design options.

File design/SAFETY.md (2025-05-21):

# Structural Analysis: Does the Circular Plate Thickness Compensate for a 23 kg Robot Weight Using PLA?

This analysis evaluates whether the 0.5-inch thick circular bottom plate of a robot can support its approximate weight of 23 kg when 3D printed using PLA. The plate's structural integrity is assessed for bending stress and deflection, considering PLA's material properties and the robot's load distribution.

Filament (PLA) particulars are detailed [here](/design/FILAMENT.md).

## Key Parameters

- **Bottom Plate Dimensions**:
  - Diameter: 18 inches (457.2 mm).
  - Thickness: 0.5 inches (12.7 mm).
- **Robot Weight**: 23 kg.
  - Weight in Newtons: 23 kg × 9.81 m/s² = 225.63 N.
- **Material**: PLA (Polylactic Acid, a common 3D printing material).
  - **Density**: ~1.24 g/cm³ (1240 kg/m³).
  - **Tensile Strength**: ~50 MPa.
  - **Flexural Strength**: ~80 MPa (resistance to bending).
  - **Young’s Modulus**: ~3.5 GPa (3500 N/mm², stiffness).
- **Load Distribution**: Assumed to be uniform across the plate for initial analysis, with a worst-case point load scenario for the battery.

## Step 1: Calculate the Weight of the Bottom Plate

- **Volume of the Bottom Plate**:
  - Radius = 457.2 mm / 2 = 228.6 mm.
  - Area = π × (228.6 mm)² = 164,021.7 mm².
  - Thickness = 12.7 mm.
  - Volume = Area × Thickness = 164,021.7 mm² × 12.7 mm = 2,083,075.6 mm³ = 2,083.08 cm³.
- **Mass of the Bottom Plate**:
  - Density of PLA = 1.24 g/cm³.
  - Mass = Volume × Density = 2,083.08 cm³ × 1.24 g/cm³ = 2,583.02 g = 2.58 kg.

The plate weighs 2.58 kg, contributing a small portion to the total 23 kg. The remaining weight (20.42 kg) comes from the rack, circuit boards, battery, wheels, and other components.

## Step 2: Load Analysis

The total weight of 225.63 N is supported by the plate, which rests on 4 wheels near the edges. We’ll analyze both a uniform load and a worst-case point load scenario.

### Load Distribution

- **Uniform Load**:
  - Area of the plate = 164,021.7 mm².
  - Pressure = Force / Area = 225.63 N / 164,021.7 mm² = 0.001375 N/mm² = 0.001375 MPa.
  This is very low compared to PLA’s strengths (50 MPa tensile, 80 MPa flexural), so compressive failure is not a concern.
- **Point Load Consideration**:
  - Battery: ~6 kg (58.86 N), assumed over a 200 mm × 200 mm area.
  - Rack and components: ~14 kg (137.34 N), over the rack’s 279.4 mm × 279.4 mm footprint.
  - Wheels and other parts: ~2.42 kg (23.74 N), near the edges.

### Bending Stress (Simplified Analysis)

The plate is approximated as a circular plate, simply supported at the edges (by the wheels), with a central load from the rack and battery.

#### Uniform Load Case

- **Maximum Deflection** (for a simply supported circular plate with uniform load):
  - Formula: δ = (3 × w × R⁴ × (5 + ν)) / (16 × E × t³ × (1 - ν)).
    - w = load per unit area = 0.001375 N/mm².
    - R = radius = 228.6 mm.
    - t = thickness = 12.7 mm.
    - E = Young’s Modulus = 3500 N/mm².
    - ν = Poisson’s ratio for PLA ≈ 0.36.
  - δ = (3 × 0.001375 × (228.6)⁴ × (5 + 0.36)) / (16 × 3500 × (12.7)³ × (1 - 0.36)).
  - (228.6)⁴ = 2,732,310,417.6 mm⁴.
  - 5 + 0.36 = 5.36.
  - (12.7)³ = 2,048.38 mm³.
  - 1 - 0.36 = 0.64.
  - δ ≈ 0.653 mm (negligible compared to the 12.7 mm thickness).

- **Maximum Bending Stress**:
  - Formula: σ = (3 × w × R² × (1 + ν)) / (4 × t²).
  - σ = (3 × 0.001375 × (228.6)² × (1 + 0.36)) / (4 × (12.7)²).
  - (228.6)² = 52,257.96 mm².
  - 1 + 0.36 = 1.36.
  - (12.7)² = 161.29 mm².
  - σ ≈ 0.361 MPa (far below PLA’s 80 MPa flexural strength).

#### Point Load Case (Battery, Worst Case)

- Battery load: 6 kg = 58.86 N, over a 200 mm × 200 mm area.
- Pressure = 58.86 N / (200 × 200) mm² = 0.0014715 N/mm².
- **Bending Stress** (central point load, simply supported circular plate):
  - Formula: σ = (3 × F × R) / (2 × π × t²).
  - F = 58.86 N, R = 228.6 mm, t = 12.7 mm.
  - σ = (3 × 58.86 × 228.6) / (2 × π × (12.7)²).
  - σ ≈ 39.81 MPa.

This stress (39.81 MPa) is below PLA’s flexural strength (80 MPa), but 3D-printed PLA often has reduced strength due to layer adhesion (effective strength ~48-64 MPa). Safety factor ≈ 1.2-1.6, which is low for a critical component.

## Step 3: Does the Thickness Compensate?

- **Bending Stress**: 39.81 MPa (point load case) vs. PLA’s 80 MPa flexural strength (safety factor 1.2-1.6 for 3D-printed PLA).
- **Deflection**: 0.653 mm (uniform load), negligible relative to the 12.7 mm thickness.
- **Conclusion**: The 0.5-inch (12.7 mm) thickness can support the 23 kg load, but the safety factor is low for a 3D-printed PLA part, especially under concentrated loads. PLA’s anisotropic nature and print imperfections could further reduce reliability.

## Step 4: Recommendations to Improve Safety

To increase the safety factor, consider the following options:

1. **Increase Thickness**:
   - Increase to 15 mm (0.59 inches):
     - New σ = (3 × 58.86 × 228.6) / (2 × π × (15)²) ≈ 28.49 MPa.
     - Safety factor = 80 / 28.49 ≈ 2.8 (or 1.7-2.2 for 3D-printed PLA).
   - New mass = 2,083.08 cm³ × (15 / 12.7) × 1.24 g/cm³ ≈ 3.05 kg (still a small fraction of 23 kg).
2. **Reinforce the Plate**:
   - Add radial ribs on the underside (e.g., 8 ribs, 5 mm thick, 20 mm high) to increase stiffness.
3. **Use a Stronger Material**:
   - Switch to PETG (flexural strength ~90 MPa) or ABS (~75 MPa) for better durability.
4. **Distribute the Load**:
   - Mount the battery and rack closer to the wheels to reduce central bending stress.

## Final Answer

The 0.5-inch (12.7 mm) thickness of the circular plate can support the 23 kg weight when made of PLA, with a maximum bending stress of ~39.81 MPa (below PLA’s 80 MPa flexural strength). However, the safety factor is low (1.2-1.6 for 3D-printed PLA), making it riskier for long-term use or concentrated loads. Increasing the thickness to 15 mm or adding ribs would provide a safer design with a higher safety factor (~1.7-2.8).

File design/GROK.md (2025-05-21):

# 3D Printed Model Suggestion for Robot with 18-Inch Circular Base

This model is designed for a robot with an 18-inch circular base, incorporating a card rack assembly to fit Vector 8801-6 S-100 bus boards (10.5 inches × 5.3 inches). The design is modular to facilitate 3D printing on standard printers. The actual design suggestions are [here](/design/PRINT.md).

## Key Dimensions and Components

### Circular Base (Bottom Plate with Skirt)
- **Bottom Plate**:
  - Shape: Circular disc
  - Diameter: 18 inches (457.2 mm)
  - Thickness: 0.5 inches (12.7 mm)
- **Skirt**:
  - Shape: Cylindrical ring
  - Outer Diameter: 18 inches (457.2 mm)
  - Height: 2 inches (50.8 mm)
  - Thickness: 0.25 inches (6.35 mm)
- **Features**:
  - Mounting holes for 4 wheels (4-inch diameter cutouts for 3.5-inch wheels).
  - Holes for rack mounts, spaced for an 11-inch × 11-inch rack footprint, centered on the plate.

### Card Rack Assembly
- **Dimensions**:
  - Width: 11 inches (279.4 mm)
  - Depth: 11 inches (279.4 mm)
  - Height: 13 inches (330.2 mm)
- **Structure**:
  - Frame: Rectangular with 0.5-inch (12.7 mm) thick vertical supports.
  - Shelves: Two shelves for circuit boards:
    - Spacing: 2 inches (50.8 mm) between shelves.
    - Position: One at 8 inches (203.2 mm) from the bottom (above battery section), another at 10 inches (254 mm).
    - Shelf Thickness: 0.25 inches (6.35 mm).
  - 100-Pin Connectors: Space for S-100 bus connectors (10.5 inches long) at the back of each shelf.
- **Features**:
  - Open sides for wiring access.
  - Mounting points at the bottom for attachment to the bottom plate.

### Rack Mounts
- **Shape**: 4 L-shaped brackets.
- **Dimensions**:
  - Each bracket: 2 inches × 2 inches (50.8 mm × 50.8 mm), 0.5 inches (12.7 mm) thick.
  - Height: 1 inch (25.4 mm).
- **Features**:
  - Holes for bolts to attach to the bottom plate and rack.

### Wheels (Optional)
- **Dimensions**:
  - Diameter: 3.5 inches (88.9 mm)
  - Width: 1 inch (25.4 mm)
- **Features**:
  - Axle hole: 0.25-inch (6.35 mm) diameter.
- **Quantity**: 4 wheels.

## Assembly Notes
- **Base Assembly**: Attach the skirt to the bottom plate (glue or screw segments if printed separately). Mount wheels to the underside using axles and bearings.
- **Rack Assembly**: Assemble the frame (vertical supports, top/bottom frames, shelves) and attach S-100 connectors (sourced separately).
- **Mounting**: Secure the rack to the bottom plate using the rack mounts.
- **Additional Components**: Source the battery, Vector 8801-6 boards, wiring, and sensors separately.

## 3D Printing Suggestions
- **Material**: PLA or PETG for most parts; ABS or nylon for wheels if durability is needed.
- **Infill**:
  - Base and rack frame: 20-30%
  - Rack mounts and wheels: 50-75%
- **Supports**: Needed for the skirt and some rack components (e.g., shelves).
- **Print Bed Size**: If smaller than 18 inches, print the base in 4 quadrants (~9 inches wide each). Rack components and wheels fit on standard beds (e.g., 220 mm × 220 mm).

### Model Breakdown for Printing
1. **Bottom Plate + Skirt**:
   - 4 quadrants, each ~9 inches (228.6 mm) wide.
   - Skirt printed separately or in segments.
2. **Card Rack Assembly**:
   - 4 vertical supports (13 inches tall).
   - Top/bottom frames (11 inches × 11 inches).
   - 2 shelves (11 inches × 11 inches).
3. **Rack Mounts**: 4 L-shaped brackets.
4. **Wheels**: 4 wheels, 3.5 inches in diameter.

## Scaling Considerations
If the 18-inch base is too large, scale down to 75% (base becomes 13.5 inches), but this may make the rack too small for the Vector 8801-6 boards. Instead, print the rack at 100% scale and adjust the base and mounts accordingly.

## Summary
This model includes an 18-inch diameter base with a 2-inch skirt, a card rack (11 inches × 11 inches × 13 inches) for S-100 boards, 4 rack mounts, and 4 wheels (3.5 inches in diameter). It’s designed for modular printing and assembly, with additional components (S-100 connectors, battery, boards) sourced separately.

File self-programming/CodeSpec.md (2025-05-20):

# Revised 8085 Self-Modifying Program with LED Indicators

The Intel 8085 assembly program is modified to use the Serial Output Data (SOD) pin to control an LED, indicating when self-programming occurs. It retains the original functionality—reading an input at `2000H`, comparing it to 50, and modifying a `JMP` to point to `HIGH_ROUTINE` or `LOW_ROUTINE`—while adding `SIM` instructions to light the LED during self-modification.

## Revised Program Description
- **Purpose**: Reads an input at `2000H`. If ≥ 50, modifies a `JMP` to `HIGH_ROUTINE` (outputs ‘H’ at `2001H`). If < 50, to `LOW_ROUTINE` (outputs ‘L’).
- **Self-Modification**: Overwrites the `JMP` at `JMP_MOD` with opcode `0C3H` and the routine’s address.
- **LED Indicator**: SOD controls an LED, on (SOD low) during self-modification, off (SOD high) otherwise.
- **Changes**:
  - Initializes SOD high (LED off) at start.
  - Sets SOD low (LED on) before self-modification.
  - Sets SOD high (LED off) after self-modification.

## Key Modifications
1. **SOD Initialization**: Sets SOD high (LED off) at program start.
2. **LED On**: Sets SOD low (LED on) before modifying `JMP_MOD`.
3. **LED Off**: Sets SOD high (LED off) after modification.
4. **Unchanged Logic**: Self-modification and output logic remain identical.

## Circuit Reminder
- **LED Connection**:
  - LED anode to 5V, cathode to 330Ω–470Ω resistor, resistor to SOD (pin 4).
  - SOD low turns LED on; SOD high turns it off.
  - For brighter LEDs, use a BC548 transistor: SOD to base via 1kΩ resistor, emitter to ground, LED cathode to collector, anode to 5V via 330Ω resistor.
- **Other Connections**:
  - Ground TRAP, RST 5.5–7.5, and INTR.
  - Use a 6 MHz crystal and reset circuit (10µF capacitor, 10kΩ resistor).

## Testing
- **Setup**:
  - Use an 8085 trainer kit or emulator (e.g., GNUSim8085).
  - Set input at `2000H` (e.g., 60 or 40).
  - Connect LED to SOD.
- **Expected Behavior**:
  - LED off during input reading/comparison.
  - LED on briefly (~20–30 µs at 3 MHz) during self-modification.
  - LED off during routines.
  - `2001H` shows ‘H’ or ‘L’.
- **Visibility**: LED on-time is short; add a delay loop for better visibility if needed.
- **Debugging**:
  - Verify `SIM` instructions and SOD connections.
  - Ground interrupts.

## Notes
- **SOD Control**: `SIM` uses SOE (bit 6 = 1). Values `40H` (SOD low) and `C0H` (SOD high) control the LED.
- **Timing**: Self-modification takes ~20–30 µs; repeated runs may be needed to see LED.
- **Safety**: Check LED polarity, resistor, and clock/reset stability.

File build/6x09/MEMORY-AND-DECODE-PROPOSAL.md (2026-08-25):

# `6x09` Memory And Decode Proposal

This proposal keeps the current Rodney bench-first software contract as stable as possible while adapting it to a `6809` or `6309`.

## Design Goal

Keep these interfaces intact:

- `ENVL`
- `ENVH`
- `TSWR`
- `MMA_L`
- `MMA_H`
- `MMD`
- `ACTL`
- `ACTH`

That way the learning model stays recognizable even though the CPU and assembly change.

## Recommended Memory Map

Use a single `64 KB` linear map with everything memory-mapped.

| Address range | Function | Notes |
|---|---|---|
| `0000-$1FFF` | program RAM | runtime load area |
| `2000-$7FFF` | scratch / expansion RAM | optional direct CPU-visible work area |
| `8000` | `ENVL` | read-only |
| `8001` | `ENVH` | read-only optional |
| `8002` | `TSWR` | read-only pseudo-random source |
| `8004` | `MMA_L` | write learned-memory low address |
| `8005` | `MMA_H` | write learned-memory high address |
| `8006` | `MMD` | read/write learned-memory data |
| `8008` | `ACTL` | write action latch |
| `8009` | `ACTH` | write optional second action latch |
| `A000-$DFFF` | learned main memory backing decode region | implementation-dependent |
| `E000-$FFEF` | monitor / support ROM | stable service routines |
| `FFF0-$FFFF` | vectors | must be valid at reset |

## Why Keep The Same Logical Addresses

Keeping the same register addresses reduces risk in three places:

- documentation stays aligned with the current design spec
- assembly porting becomes semantic rather than architectural
- `Board B` and `Board C` can remain mostly the same conceptually

## Reset Vector Requirement

This is the biggest map difference from the current `8085` ROM style.

The `6809` reset sequence fetches vectors from the top of memory, so ROM must exist at the high end of the address space.

That means the support ROM should be decoded so that:

- vector space at `FFF0-$FFFF` is always valid
- executable ROM body is reachable nearby, commonly at `E000-$FFFF` or similar

## Preferred ROM Layout

Recommended first pass:

| Address range | Function |
|---|---|
| `E000-$EFFF` | support ROM body |
| `F000-$FFEF` | extra ROM service space |
| `FFF0-$FFFF` | vectors |

This lets the ROM:

- own reset cleanly
- host stable monitor and service calls
- avoid awkward reset overlays

## Decode Strategy

Recommended approach:

- use coarse high-address decode first
- generate sub-selects for `8000` page I/O
- keep `MMA` and `MMD` as explicit decoded registers

First-pass decode goals:

1. deterministic reset fetch
2. simple chip-select visibility on a logic probe
3. minimum glue depth between CPU and memory

## Learned Memory Path

The current Rodney redesign uses indirect access to learned state:

1. write `MMA_L`
2. write `MMA_H`
3. read or write `MMD`

That should remain unchanged on `6x09`.

Why keep it:

- it matches the repo's current Rodney interpretation
- it keeps learned state conceptually separate from program RAM
- it simplifies Beta and Gamma porting

## `6809` Versus `6309` Impact On The Map

Very little should change in the memory map itself.

The difference is mainly software opportunity:

- `6309` can accelerate scanning and table work later
- vectors, I/O layout, and learned-memory addressing can remain identical

## Recommended Rev 1 Rule

Do not spend time on banking in the first `6x09` build.

Keep:

- one linear map
- one ROM region
- one program RAM region
- one learned-memory mechanism

Banking can come later if Gamma or monitor growth genuinely demands it.

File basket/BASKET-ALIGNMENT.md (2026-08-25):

# Basket Alignment To Current Rodney Build

Alignment of [`basket/basket-items.xls`](/home/cartheur/ame/aiventure/aiventure-github/cartheur/aiventure-rodney/basket/basket-items.xls:1) against the current baseline build target in [`build-of-materials/RODNEY-3BOARD-SINGLE-SHEET-BOM.md`](/home/cartheur/ame/aiventure/aiventure-github/cartheur/aiventure-rodney/build-of-materials/RODNEY-3BOARD-SINGLE-SHEET-BOM.md:1).

Last updated: `2026-08-25`

## Scope

- This compares the shopping basket to the current **3-board Rodney bench build**.
- The goal is to see which basket items already support the build, which only partly support it, which baseline parts are still missing, and which basket items are for future work rather than the current machine.
- Quantities below are compared to the baseline build BOM, not to legacy Rodney parts lists.

## Direct Matches Or Better-Than-Needed Coverage

| Basket item | Basket qty | Build need | Status | Notes |
|---|---:|---:|---|---|
| `AS6C6264-55PCN` | 6 | 1 | covered | baseline needs `1` for `Board B U7`; leaves strong spare margin |
| `195-8MST` | 10 | 2 | covered | matches current selected `Board C` DIP switch |
| `AT28C64B-15PU` | 10 | 1 | covered | baseline EEPROM plus spares |
| `SN74LS32N` | 10 | 1 | covered | matches optional planned `Board B` glue part |
| `SN74LS86AN` | 10 | 1 | covered | covers `Board C` XOR feedback |
| `SN74LS164N` | 10 | 1 | covered | covers `Board C` pseudo-random source |
| `SN74LS273N` | 10 | 3 | covered | baseline uses `2` on `Board B` and `1` on `Board C` |
| `SN74LS245N` | 20 | 2 | covered | baseline uses `1` on `Board A` and `1` on `Board B` |
| `SN74LS138N` | 10 | 2 | covered | baseline uses `1` on `Board A` and `1` on `Board B` |
| `SN74LS139AN` | 10 | 1 | covered | covers `Board B` subdecode |
| `22pF` ceramic capacitor | 10 | 2 | covered | enough for the `5 MHz` crystal load pair |
| `0.1uF` capacitor | 100 | 17 | covered | enough for baseline decoupling with wide spare margin |
| `10uF` electrolytic | 100 | 1 | covered | enough for reset timing or other small bulk use |
| `47uF` electrolytic | 20 | 3 | covered | enough for one bulk capacitor per board |
| `228-1290-00-0602J` 3M `28`-contact socket | 6 | 3 required `DIP-28 ZIF` | covered | enough for the full `U1/U7/U8` ZIF plan on two Rodney units, with no spare beyond that |

## Partial Coverage Or Needs Confirmation

| Basket item | Basket qty | Build need | Status | Notes |
|---|---:|---:|---|---|
| `123-47-628-41-001000` Mill-Max wire-wrap socket | 10 | 3 | covered for baseline | enough for one unit and contributes strong margin toward a two-unit build when combined with on-hand inventory |
| `D0820-42` Harwin `DIP-20` wire-wrap socket | 20 | 6 | covered for baseline | resolves the main `DIP-20` socket shortage and gives useful margin for a two-unit build when combined with on-hand inventory |
| `RN60D3300FB14` `330R` resistor | 100 | 16 | covered for baseline | enough for a single unit with strong margin and materially improves two-unit LED-resistor readiness when combined with on-hand stock |
| `MF1/4DCT52R1001F` `1k` resistor | 100 | 4 | covered | far exceeds the baseline optional `1k` stock target |
| `3365/40-CUT-LENGTH` 40-conductor ribbon cable | 3 ft | 2 lengths | partial | likely enough for a single baseline machine, but probably light for two complete units unless the cable runs are kept very short |
| `09185406904` Harting `40P` male IDC long lever | 2 | connectorized cable hardware | partial | useful for the connectorized harness path |
| `09185406804` Harting `40P` female IDC | 2 | connectorized cable hardware | partial | useful for the connectorized harness path |
| `40-600-21` Aries `40`-pin header | 2 | `4` header strips | partial | may help with header stock, but the baseline BOM still calls for more header material |
| `ESW-120-44-T-D` Samtec elevated socket strip | 2 | `4` header strips | partial | potentially useful interconnect stock, but not a direct replacement for all planned `0.1"` male headers |
| Same Sky pushbuttons (`PB5` / `PB4L`) | 4 total | 3 total switches | partial | quantity is enough for `reset` plus `2` momentary switches, but these are panel-mount industrial parts and should be checked against the intended mounting approach |

## Missing From The Basket For The Baseline Build

These items do not appear in the basket in a clear baseline-ready form.

This is a basket-only gap list, not a combined readiness verdict. Some of these items are now present in `inventory/list.csv`; use the `Final Fitness Check` section below for the current combined `inventory + basket` status.

| Build item | Qty | Notes |
|---|---:|---|
| Vector `8801-6` wire-wrap plugboard | 3 | core board set |
| `100-pin` wire-wrap edge connector | 2 | `Board A` and `Board B` |
| `8085A` | 1 | baseline CPU |
| `74LS373` | 1 | `Board A` address latch |
| `74LS04` | 1 | `Board A` clock/reset glue |
| `74LS00` | 2 | `Board A` and `Board B` |
| `62256` SRAM | 1 | `Board B U1` main memory |
| `74LS244` | 1 | `Board C` input buffer |
| `5 MHz` crystal | 1 | basket has `16 MHz`, not the current selected part |
| `10k` resistors | 10 total baseline stock target | `2` for reset plus `8` extra in BOM |
| `1k` resistors | 4 | optional glue / indicator stock from baseline BOM |
| `330R` LED resistors | 16 | one per LED on `Board C` |
| `10k` resistor network or equivalent pull-up parts | 2 | for switch pulls on `Board C` |
| `5mm` LEDs | 16 | operator and debug indicators |
| DIP-40 wire-wrap socket | 1 | CPU socket |
| DIP-20 wire-wrap socket | 6 | `A, B, C` |
| DIP-16 wire-wrap socket | 3 | `A, B` |
| DIP-14 wire-wrap socket | 5 | `A, B, C` |
| `DIP-28 ZIF` socket | 3 required | planned for `U1`, `U7`, `U8` |
| `0.1"` male header strips | 4 | bus, service, debug |
| test posts / turret posts | 18 | top-edge minimum |
| hard-wire harness anchor points | 1 set | `Board C` |
| `30 AWG` Kynar wire-wrap wire | 3 to 5 spools | multiple colors preferred |
| `22-24 AWG` red hookup wire | 1 spool | `+5V` |
| `22-24 AWG` black hookup wire | 1 spool | `GND` |
| cable lacing / clamps / zip ties | 1 pack | harness management |
| standoffs / board supports | 1 set | 3-board stack support |
| labels / tape flags | 1 pack | build aid |
| `+5V` USB battery supply | 1 | baseline bring-up source |
| HP `5004A` style clip leads | 2 | bring-up clips |
| wire-wrap tool | 1 | required bench tool |
| unwrap tool | 1 | strongly recommended |
| logic probe | 1 | recommended |
| oscilloscope | 1 | recommended |

## Basket Items That Look Like Future Stock Or Non-Baseline Extras

These are not wrong purchases, but they are not required to assemble the current baseline machine.

| Basket item | Why it is extra for the current build |
|---|---|
| `BPA08B` side-actuated DIP switch | repo already treats this as future variant stock, not current `Board C` |
| `AT28C256-15PU` | future EEPROM stock, not baseline |
| `SN74LS85N` | planned experiment / decision-logic stock, not baseline |
| `LM324AN` op-amp | useful for the new light and sound analog-preview path, not part of the current digital baseline |
| Raspberry Pi HDMI cable | not part of Rodney baseline BOM |
| TE `5749180-1` DIN connector | not in current baseline BOM |
| `LM339AN` comparator | not in current baseline BOM |
| resettable fuses `MF-R050-AP`, `MF-R110-AP`, `MF-R075-AP` | not in current baseline BOM |
| `ATS16B-E` `16 MHz` crystal | current BOM selects `5 MHz` |
| `1N5819` | not in current baseline BOM |
| `1N4148` | not in current baseline BOM |
| `1uF` film capacitor | not required by current baseline BOM |
| `100pF`, `470pF`, `1000pF`, `4700pF`, `0.01uF` capacitors | not required by current baseline BOM |
| `3386P-1-103LF` trimmer | not in current baseline BOM |
| `USBLC6-2SC6` ESD part | not in current baseline BOM |
| `M20-9994045` Harwin horizontal pin header | not clearly needed for current baseline BOM |
| `ATMEGA328P-PU` | not part of current Rodney baseline build |
| Newhaven `0116GZ-FSW-GBW` LCD | not part of current Rodney baseline build |
| Displaytech `204G BC BW` LCD | not part of current Rodney baseline build |
| Same Sky `PTNS2-4515M-B10` slide potentiometer | not part of current Rodney baseline build |
| `CD74HC4051E` analog mux | not part of current Rodney baseline build |

## Recommended Basket Direction

If the goal is to make the basket line up with the current build target:

1. Keep the directly matching memory, logic, switch, and capacitor items.
2. Treat the `DIP-28` socket situation as unresolved until the exact socket types are confirmed.
3. Add the missing baseline CPU, main memory, support logic, sockets, LEDs, resistors, wiring, connectors, and mechanical items listed above.
4. Decide whether the non-baseline extras should stay in this order as future stock or move to a separate expansion basket.
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

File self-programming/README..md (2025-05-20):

# Modified 8085 Self-Modifying Program with LED Indicators

To indicate when the 8085 assembly program performs self-programming, the original example is modified to use the Serial Output Data (SOD) pin to control an LED, lighting it during the self-modification process. This leverages the 8085’s serial output, aligns with the program’s purpose, and highlights risks Intel cautioned against, such as unpredictability and debugging challenges.
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

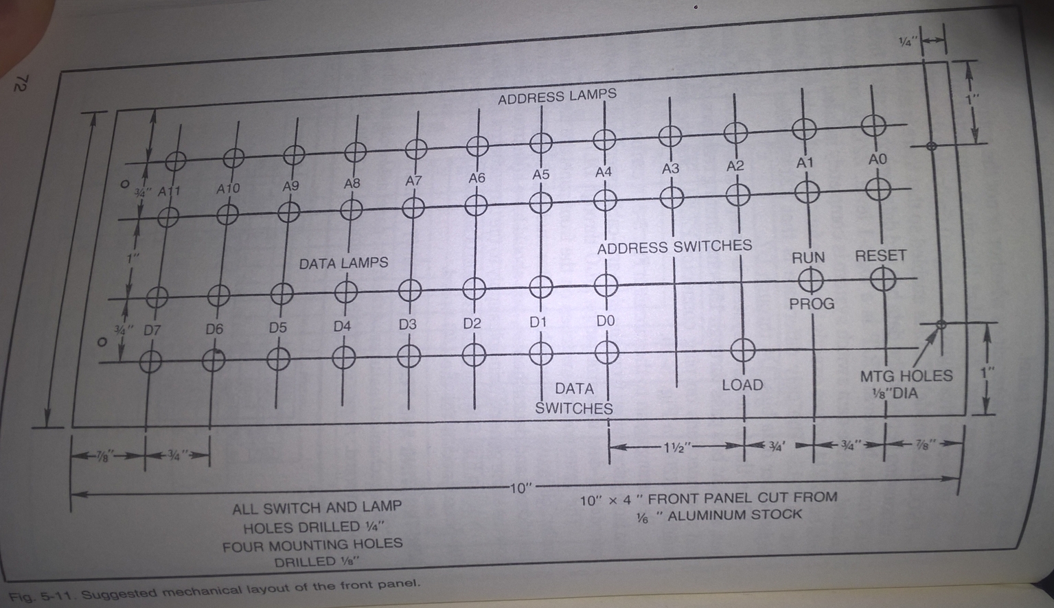
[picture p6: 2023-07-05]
book/figures/panel_design_book.jpg

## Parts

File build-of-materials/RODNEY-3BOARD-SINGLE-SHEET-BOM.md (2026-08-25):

# Rodney 3-Board Single-Sheet BOM

Single-sheet build of materials for the current `3 x Vector 8801-6` bench-first Rodney wire-wrap build.

This BOM matches the current planning docs:

- [design/RODNEY-WIREWRAP-DESIGN-SPEC.md](/home/cartheur/ame/aiventure/aiventure-github/cartheur/aiventure-rodney/design/RODNEY-WIREWRAP-DESIGN-SPEC.md:1)
- [design/RODNEY-WIREWRAP-COORDINATE-WORKSHEET.md](/home/cartheur/ame/aiventure/aiventure-github/cartheur/aiventure-rodney/design/RODNEY-WIREWRAP-COORDINATE-WORKSHEET.md:1)
- [design/RODNEY-WIREWRAP-SILKSCREEN-OVERLAYS.md](/home/cartheur/ame/aiventure/aiventure-github/cartheur/aiventure-rodney/design/RODNEY-WIREWRAP-SILKSCREEN-OVERLAYS.md:1)

Use this as the bench checklist for whether we have everything needed to start placing sockets and wiring the first-pass machine.

## Assumptions

- This is the **new 3-board bench build**, not a strict reproduction of the original 1979 board set.
- EEPROM is included for the current plan.
- `ENVH` and `ACTH/debug` footprints are included even if you choose not to populate them on rev A.
- The stack uses **2 edge connectors total**, with the third board hard-wired into the stack harness.
- Preferred choice: connectorized `Board A` and `Board B`, hard-wired `Board C`.
- Quantities below are **required build quantities**, not current stock counts.

## Single-Sheet BOM

| Check | Category | Item | Footprint | Qty | Board / Use | Notes |
|---|---|---|---|---:|---|---|
| `[ ]` | Core | Vector `8801-6` wire-wrap plugboard | `S-100 / 100-pin board` | 3 | A, B, C | one board per function |
| `[ ]` | Core | 100-pin wire-wrap edge connector | `100-pin edge connector` | 2 | Board A, Board B | `Board C` is hard-wired |
| `[ ]` | Core | 0.1" male header strips | `0.1" header` | 4 | all boards | bus, service, debug |
| `[ ]` | Core | test posts / turret posts | `turret / post` | 18 | all boards | `6 + 8 + 4` top-edge minimum |
| `[ ]` | Core | hard-wire interboard harness anchor points | `lug / header / clamp` | 1 set | Board C | header, solder lugs, or strain-relieved tie points |
| `[ ]` | CPU board | `8085A` | `DIP-40` | 1 | Board A | CPU |
| `[ ]` | CPU board | `74LS373` | `DIP-20` | 1 | Board A | address latch |
| `[ ]` | CPU board | `74LS245` | `DIP-20` | 1 | Board A | data transceiver |
| `[ ]` | CPU board | `74LS138` | `DIP-16` | 1 | Board A | coarse decode |
| `[ ]` | CPU board | `74LS04` | `DIP-14` | 1 | Board A | clock/reset glue |
| `[ ]` | CPU board | `74LS00` | `DIP-14` | 1 | Board A | glue logic |
| `[ ]` | CPU board | crystal `5 MHz` | `2-pin crystal` | 1 | Board A | selected standard; already purchased in original parts list |
| `[ ]` | CPU board | crystal load capacitors `22pF` | `radial / ceramic` | 2 | Board A | if crystal circuit uses them |
| `[ ]` | CPU board | reset pushbutton | `panel / PCB switch` | 1 | Board A | top-edge service area |
| `[ ]` | CPU board | `10k` resistor | `axial resistor` | 2 | Board A | reset network |
| `[ ]` | CPU board | `1uF` to `10uF` capacitor | `radial electrolytic` | 1 | Board A | reset timing |
| `[ ]` | Memory board | `62256` SRAM | `DIP-28` | 1 | Board B | main memory; selected part: `Alliance AS6C62256-55PIN` |
| `[ ]` | Memory board | `6264` SRAM | `DIP-28` | 1 | Board B | program RAM; selected part: `Alliance AS6C6264-55PCN` |
| `[ ]` | Memory board | `AT28C64B-15PU` EEPROM | `DIP-28` | 1 | Board B | monitor / bootstrap; selected part |
| `[ ]` | Memory board | `74LS138` | `DIP-16` | 1 | Board B | region decode |
| `[ ]` | Memory board | `74LS139` | `DIP-16` | 1 | Board B | subdecode |
| `[ ]` | Memory board | `74LS273` | `DIP-20` | 2 | Board B | `MMA low`, `MMA high` |
| `[ ]` | Memory board | `74LS245` | `DIP-20` | 1 | Board B | `MMD` path / data isolation |
| `[ ]` | Memory board | `74LS00` | `DIP-14` | 1 | Board B | decode glue |
| `[ ]` | Memory board | `74LS32N` | `DIP-14` | 1 | Board B | planned decode / glue flexibility; datasheet in repo |
| `[ ]` | I/O board | `74LS244` | `DIP-20` | 1 | Board C | input buffer |
| `[ ]` | I/O board | `74LS273` | `DIP-20` | 1 | Board C | output latch |
| `[ ]` | I/O board | `74LS164` | `DIP-14` | 1 | Board C | pseudo-random source |
| `[ ]` | I/O board | `74LS86` | `DIP-14` | 1 | Board C | XOR feedback |
| `[ ]` | I/O board | `8-position` DIP switch | `DIP switch, 8-pos` | 2 | Board C | `ENVL`, `ENVH`; selected part: `CTS 195-8MST`, through-hole, piano/top-actuated |
| `[ ]` | I/O board | `5mm` LEDs | `T-1 3/4` | 16 | Board C | `ACTL` plus debug / `ACTH` |
| `[ ]` | I/O board | LED resistors `330R` | `axial resistor` | 16 | Board C | one per LED |
| `[ ]` | I/O board | momentary switches | `panel / PCB switch` | 2 | Board C | mode / test |
| `[ ]` | I/O board | `10k` resistor network or discrete pull-ups | `SIP network or axial` | 2 | Board C | switch pulls |
| `[ ]` | Sockets | DIP-40 wire-wrap socket | `DIP-40 WW socket` | 1 | Board A | `8085A` |
| `[ ]` | Sockets | DIP-28 wire-wrap socket | `DIP-28 WW socket` | 3 | Board B | `62256`, `6264`, EEPROM |
| `[ ]` | Sockets | DIP-20 wire-wrap socket | `DIP-20 WW socket` | 6 | A, B, C | `1 + 3 + 2` |
| `[ ]` | Sockets | DIP-16 wire-wrap socket | `DIP-16 WW socket` | 3 | A, B | `1 + 2` |
| `[ ]` | Sockets | DIP-14 wire-wrap socket | `DIP-14 WW socket` | 5 | A, B, C | `2 + 2 + 1` |
| `[ ]` | Sockets | DIP-28 ZIF socket | `DIP-28 ZIF` | 3 required | Board B | plugs into soldered DIP-28 machine-pin WW sockets at `U1`, `U7`, and `U8`; `1` spare recommended |
| `[ ]` | Passive | `0.1uF` ceramic decoupling capacitors | `radial / ceramic` | 17 | all boards | one per IC minimum |
| `[ ]` | Passive | bulk electrolytic `47uF` to `470uF` | `radial electrolytic` | 3 | A, B, C | one per board |
| `[ ]` | Passive | extra `10k` resistors | `axial resistor` | 8 | general | pull-ups, glue, spare |
| `[ ]` | Passive | extra `1k` resistors | `axial resistor` | 4 | general | optional indicators / glue |
| `[ ]` | Wiring | `30 AWG` Kynar wire-wrap wire | `spool` | 3 to 5 spools | all boards | multiple colors preferred |
| `[ ]` | Wiring | `22-24 AWG` hookup wire, red | `spool` | 1 spool | power | `+5V` |
| `[ ]` | Wiring | `22-24 AWG` hookup wire, black | `spool` | 1 spool | power | `GND` |
| `[ ]` | Wiring | 16- to 26-conductor ribbon or grouped cable | `cable` | 2 lengths | `CAB-A-B`, `CAB-A-C` | one connectorized cable and one fixed harness |
| `[ ]` | Wiring | cable lacing, zip ties, or harness clamps | `consumable` | 1 pack | stack harness | recommended for the hard-wired board |
| `[ ]` | Mechanical | standoffs / board supports | `hardware set` | 1 set | rack | enough for 3 boards |
| `[ ]` | Mechanical | labels or masking tape flags | `consumable` | 1 pack | build aid | cable and signal marking |
| `[ ]` | Power | `+5V` USB battery supply | `USB power bank` | 1 | bring-up | selected bench source for first logic bring-up |
| `[ ]` | Power | HP `5004A` signature-analyzer clip leads | `grabber / clip lead` | 2 | bring-up | used to clip `+5V` and `GND` onto board input pins |
| `[ ]` | Power | wall-powered `+5V` bench supply | `bench supply` | 1 optional | fallback | use only if the USB source shows droop or unstable behavior |
| `[ ]` | Tools | `Batronix BX32P Barlino II` programmer | `USB EPROM / EEPROM programmer` | 1 optional | ROM programming | recommended programmer for planned `28C` EEPROMs and likely compatible with older `ST MC27C128` EPROM parts |
| `[ ]` | Tools | wire-wrap tool | `hand tool` | 1 | build | manual or powered |
| `[ ]` | Tools | unwrap tool | `hand tool` | 1 | build | strongly recommended |
| `[ ]` | Tools | `Weller` soldering iron | `bench tool` | 1 | build | connectors, headers |
| `[ ]` | Tools | logic probe | `bench tool` | 1 | debug | recommended |
| `[ ]` | Tools | oscilloscope | `bench instrument` | 1 | debug | recommended |

## Quick Totals

Baseline first-pass build:

| Type | Qty |
|---|---:|
| Boards | 3 |
| Edge connectors | 2 |
| ICs on sockets | 19 to 20 |
| Wire-wrap sockets total | 18 |
| DIP-28 memory devices populated | 3 |
| Top-edge test posts minimum | 18 |
| LEDs | 16 |
| DIP switch packs | 2 |
| Bulk capacitors | 3 |
| `0.1uF` decouplers minimum | 17 |

Expansion-oriented stock guidance:

| Type | Qty |
|---|---:|
| Spare `6264` devices to keep on hand | 1 to 2 |
| Total `6264` devices including baseline | 2 to 3 |
| Total DIP-28 memory devices on hand including baseline and spare `6264`s | 4 to 5 |
| Spare DIP-28 wire-wrap sockets | 1 to 2 |
| Spare DIP-28 ZIF sockets | 1 recommended |

Counting note:

- baseline `19` assumes the `74LS32N` position is left unpopulated
- baseline `20` assumes that `74LS32N` is populated

## Recommended Swap-Isolation Targets

If you want to reserve ZIF capability without overcomplicating the build, prioritize in this order:

1. `Board B U8` EEPROM / monitor ROM
2. `Board B U7` `6264` program RAM
3. `Board B U1` `62256` only if you plan active learned-memory experiments with multiple SRAMs

For the current plan, we are reserving:

- `3 x DIP-28 ZIF` on Board B for `U1`, `U7`, and `U8`
- `1` additional spare `DIP-28 ZIF` is recommended for purchasing convenience and replacement margin

Board B placement note:

- keep lever-clearance space around all three `28-pin` memory positions
- avoid placing tall posts or bulk harness tie-downs immediately beside `U8`
- intended stack is `board -> WW socket -> ZIF -> memory chip`

## Notes Against Existing Repo Inventory

- The repo already references the key board family and several compatible parts in [build-of-materials/Parts-List.csv](/home/cartheur/ame/aiventure/aiventure-github/cartheur/aiventure-rodney/build-of-materials/Parts-List.csv:1) and [build-of-materials/BOM_Rodney.csv](/home/cartheur/ame/aiventure/aiventure-github/cartheur/aiventure-rodney/build-of-materials/BOM_Rodney.csv:1), but those lists mix original-machine parts with this newer 3-board plan.
- This sheet is meant to be the simplified current-build target list.
- For the `2-connector` build, `Board C` is the best hard-wired candidate because it is the least likely board to need repeated removal during CPU and memory bring-up.
- Current bench-power plan is a `+5V` USB battery with `2` HP `5004A` signature-analyzer style clips landing on board power-input pins; verify stable `5V` under load and keep a solid common ground before CPU bring-up.

## Selected Memory Part

Current selected `U7` program RAM:

- `Alliance AS6C6264-55PCN`
- `8K x 8`
- `DIP-28` PDIP
- commercial temp grade `0C to 70C`
- preferred over `AS6C6264-55PIN` because the industrial-temperature variant costs about `EUR 5` more per device without adding useful value for the current bench build

Current selected `U1` main memory:

- `Alliance AS6C62256-55PIN`
- `32K x 8`
- `DIP-28` PDIP
- industrial temp grade `-40C to +85C`
- direct fit for the current `Board B U1` footprint and `28-pin ZIF` plan

Current selected `U8` monitor EEPROM:

- `AT28C64B-15PU`
- `8K x 8`
- `DIP-28` PDIP
- selected as the current EEPROM purchase part for monitor / bootstrap use
- direct fit for the current `Board B U8` footprint and `28-pin ZIF` plan

Current selected `SW1` and `SW2` input switches:

- `CTS 195-8MST`
- `8-position` DIP switch
- through-hole
- piano / top-actuated
- tape sealed
- selected because it matches the current `Board C` operator-facing switch layout better than the side-actuated `BPA` family

Future variant stock:

- `2 x BPA08B`
- retained as stock for possible future miniaturized or side-access board variants
- not planned for the current `Board C` Rodney build

Optional operator-feedback control:

- `1 x ETI Systems J1-00105` joystick is now on hand and is a strong optional `Board C` add-on for environmental-feedback training work
- call this optional block **the joy circuit**
- treat it as a `4-way` digital input device rather than an analog position control
- recommended use: map `up`, `down`, `left`, and `right` into `4` spare `Board C` input lines through the existing input-buffer path
- recommended signal names: `JOY_UP`, `JOY_DN`, `JOY_LT`, `JOY_RT`
- recommended electrical treatment: add pull-ups or pull-downs as needed and handle debounce in software first unless tests show a real need for hardware cleanup
- best early role: human-in-the-loop correction, reward-direction cueing, manual behavior nudging, or explicit environment-response tagging during training experiments
- integration stance: optional only, not part of the baseline first-pass machine, but a very plausible second-step operator interface once `Board C` bring-up is stable

Forward-looking memory note:

- EEPROM datasheet support has been added to this BoM workflow for the current monitor / bootstrap path.
- Keep some additional `256K`-class memory devices in reserve as future stock, not as a current required build item.
- Rationale: if `GAMMA-1` succeeds and the project grows into heavier learned-state or `DELTA-1` experimental work, we may want more memory headroom while we refine how Rodney's environment model interacts with the machine-intelligence scheme.

## Memory Expansion Options

This BoM is still centered on the current first-pass configuration, but we should scope purchases broadly enough to support nearby memory experiments without reworking the ordering list.

Current baseline:

- `U7` populated as `1 x 6264` program RAM
- `U8` populated as `1 x AT28C64B-15PU` EEPROM / monitor device
- direct-mapped program RAM at `0000h-1FFFh`

Supported alternate population paths:

- populate `U8` with a second `6264` instead of EEPROM if we want `2 x` directly addressed program RAM regions
- keep `U8` as EEPROM and retain the current balanced bring-up path of RAM plus monitor / bootstrap
- reserve bank-switched program-RAM experiments as a later option if we want multiple RAM images without consuming additional address regions

BoM scoping guidance:

- keep the current required quantities unchanged for the first build
- stock at least `1-2` extra `6264` devices for alternate `U7` / `U8` experiments
- stock spare `DIP-28` wire-wrap sockets and `DIP-28 ZIF` sockets so `U8` can remain a flexible memory site
- keep a small amount of jumper, header, or strap hardware on hand for alternate chip-select routing or bank-select experiments

Design impact note:

- adding a second directly addressed program RAM device is a modest decode and wiring change, not a full architecture change
- the larger constraint is physical socket allocation on `Board B`, because the current memory plan centers on `U1` main memory, `U7` program RAM, and `U8` EEPROM / ROM
- a true fourth memory site would be a future board-layout revision rather than a first-pass BoM requirement

Bank-switched program RAM note:

- one possible later scheme is to keep the CPU-visible program window at `0000h-1FFFh` and select between two physical RAM banks with a bank-select bit
- practical implementation: qualify `/PRG_RAM_CS` with one extra bank-select stage so only one RAM device is enabled at a time
- likely control methods: jumper-select for coarse experiments, or a latch / memory-mapped control bit for software-controlled bank switching
- likely extra parts: small jumper/header stock, one latch or flip-flop device if software-controlled selection is desired, and a small amount of extra glue logic
- main software caution: do not switch away from the currently executing bank unless the switching routine lives in EEPROM / monitor ROM or another always-visible code region
- recommendation: treat bank switching as a second-phase experiment after first-pass direct-mapped bring-up is stable

Recommended ROM programmer:

- `Batronix BX32P Barlino II`
- suitable for `28C` parallel EEPROM workflow
- likely suitable for the older `ST MC27C128` EPROM already on hand
- lets us support either the EEPROM or EPROM `U8` path with one tool class

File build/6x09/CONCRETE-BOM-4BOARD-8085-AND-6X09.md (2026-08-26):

# Concrete BOM: `4`-Board Rodney With `8085` And `6x09`

Concrete parts plan for building:

- `Board A-8085`
- `Board A-6x09`
- `Board B`
- `Board C`

This assumes you want one shared `Board B` and one shared `Board C`, with two alternate CPU boards built in parallel.

This file intentionally de-emphasizes the edge-connector strategy because you already have a specific physical plan for that area.

Companion references:

- [RODNEY-3BOARD-SINGLE-SHEET-BOM-6X09.md](/home/cartheur/ame/aiventure/aiventure-github/cartheur/aiventure-rodney/build/6x09/RODNEY-3BOARD-SINGLE-SHEET-BOM-6X09.md:1)
- [RODNEY-3BOARD-SINGLE-SHEET-BOM-8085-REFERENCE.md](/home/cartheur/ame/aiventure/aiventure-github/cartheur/aiventure-rodney/build/6x09/RODNEY-3BOARD-SINGLE-SHEET-BOM-8085-REFERENCE.md:1)
- [6X09-BOM-DELTA.md](/home/cartheur/ame/aiventure/aiventure-github/cartheur/aiventure-rodney/build/6x09/6X09-BOM-DELTA.md:1)
- [6X09-MISSING-PARTS-CHECKLIST.md](/home/cartheur/ame/aiventure/aiventure-github/cartheur/aiventure-rodney/build/6x09/6X09-MISSING-PARTS-CHECKLIST.md:1)
- [AN002-GA144-CRYSTAL-BOUNDARY.md](/home/cartheur/ame/aiventure/aiventure-github/cartheur/aiventure-rodney/build/6x09/AN002-GA144-CRYSTAL-BOUNDARY.md:1)
- [AN002-171106-OSC.pdf](/home/cartheur/ame/aiventure/aiventure-github/cartheur/aiventure-rodney/build/6x09/AN002-171106-OSC.pdf)

## Build Intent

The point of this plan is:

- keep the current Rodney memory and I/O architecture stable
- preserve the `8085` path
- add a separate `6x09` CPU board for direct comparison
- avoid rebuilding `Board B` and `Board C` twice

## Boundary Marker

This document marks the hardware boundary before any introduction of a `GA144`.

Scope of this BOM:

- conventional socketed CPU boards
- one `Board A-8085`
- one `Board A-6x09`
- shared `Board B`
- shared `Board C`

Out of scope for this BOM:

- any `GA144` board
- any `GA144` support circuitry
- any mixed `6x09` / `GA144` hybrid backplane or handoff scheme

If a `GA144` path is pursued, it should be treated as the next architectural layer after this concrete CPU-board boundary.

More exact interpretation:

- this BOM ends at the conventional crystal-clocked CPU boundary
- the `GA144` path begins at the resonant frequency of that crystal

So the crystal is the borderline between:

- conventional socketed CPU timing and support logic
- the next `GA144` architectural regime

Branch note:

- just before establishing that boundary, the `Board A-6x09` concept was about to use a `74LS74` as part of a more conventional clock-divider / phase-generation scheme
- that approach remains documented here as the near-term conventional option, but it is now explicitly de-emphasized relative to the `GA144` crystal-boundary interpretation described by `AN002`
- see `AN002`

## Board Set

- `1 x Board A-8085`
- `1 x Board A-6x09`
- `1 x Board B`
- `1 x Board C`

Total boards:

- `4 x Vector 8801-6`

## Edge / Interconnect Note

Use your existing connector and interconnect plan.

This BOM therefore treats the following as planning placeholders only:

- board-to-board edge connectors
- fixed harness details
- cable-end hardware selection

The real focus here is the electronics population.

## `Board A-8085`

### ICs

- `1 x 8085A`
- `1 x SN74LS373N`
- `1 x SN74LS245N`
- `1 x SN74LS138N`
- `1 x SN74LS04N`
- `1 x SN74LS00N`

### Clock / reset

- `1 x 5 MHz crystal`
- `2 x 22pF` capacitors
- `1 x` reset pushbutton
- `2 x 10k` resistors
- `1 x 1uF to 10uF` reset capacitor

### Sockets

- `1 x DIP-40` wire-wrap socket
- `1 x DIP-20` wire-wrap socket
- `1 x DIP-16` wire-wrap socket
- `2 x DIP-14` wire-wrap sockets

### Board-local passives

- `6 x 0.1uF` decoupling capacitors minimum
- `1 x 47uF to 470uF` bulk capacitor

## `Board A-6x09`

First-pass target CPU:

- `1 x MC6809P`

Later validation CPU:

- `1 x HD63C09RP` drop-in test on the same board

From `Rev. 1` onward:

- `GA144` inclusion is assumed on `Board A` at the crystal boundary
- see [AN002-171106-OSC.pdf](/home/cartheur/ame/aiventure/aiventure-github/cartheur/aiventure-rodney/build/6x09/AN002-171106-OSC.pdf)

### ICs

- `1 x MC6809P`
- `1 x SN74LS245N`
- `1 x SN74LS138N`
- `1 x SN74LS04N`
- `1 x SN74LS00N`
- `1 x SN74LS74N` optional / de-emphasized
- `1 x SN74LS14N`

### Clock / reset

- `1 x` canned oscillator module
- `1 x` optional external clock header or jumper block
- `1 x` reset pushbutton
- `5 x 10k` resistors
- `1 x 1uF to 10uF` reset capacitor

### Sockets

- `1 x DIP-40` wire-wrap socket
- `1 x DIP-20` wire-wrap socket
- `1 x DIP-16` wire-wrap socket
- `3 x DIP-14` wire-wrap sockets

### Board-local passives

- `7 x 0.1uF` decoupling capacitors minimum
- `1 x 47uF to 470uF` bulk capacitor
- small clock-support passive set as required by final `E/Q` implementation

Clock note:

- the `SN74LS74N` remains listed only because the conventional `6x09` branch was about to use it for a less elegant divider / phase-generation path
- the cleaner direction is to let `GA144` handle crystal excitation and resonance-finding behavior as described by `AN002`
- if that direction holds, `SN74LS74N` should be considered provisional rather than foundational

### `6309` Hardware Note

No mandatory extra support hardware is required just to run an `HD63C09RP` in an `MC6809P`-compatible first pass.

Recommended stance:

- design `Board A-6x09` for `MC6809P` bring-up
- validate `HD63C09RP` as a drop-in second step
- only revisit timing if you later push clock speed or use `HD63C09RP`-specific software aggressively

## `Board B`

### ICs

- `1 x AS6C62256-55PIN`
- `1 x AS6C6264-55PCN`
- `1 x AT28C64B-15PU`
- `1 x SN74LS138N`
- `1 x SN74LS139AN`
- `2 x SN74LS273N`
- `1 x SN74LS245N`
- `1 x SN74LS00N`
- `1 x SN74LS32N`

### Sockets

- `3 x DIP-28` wire-wrap sockets
- `3 x DIP-28 ZIF` sockets if you want the current swap-friendly plan
- `3 x DIP-20` wire-wrap sockets
- `1 x DIP-16` wire-wrap socket
- `2 x DIP-14` wire-wrap sockets

### Board-local passives

- `9 x 0.1uF` decoupling capacitors minimum
- `1 x 47uF to 470uF` bulk capacitor

## `Board C`

### ICs

- `1 x SN74LS244N`
- `1 x SN74LS273N`
- `1 x SN74LS164N`
- `1 x SN74LS86AN`

### Operator and display parts

- `2 x 8-position` DIP switches
- `16 x 5mm` LEDs
- `16 x 330R` resistors
- `2 x` momentary pushbuttons
- `2 x` pull-up resistor networks or equivalent discrete pull-ups

### Sockets

- `2 x DIP-20` wire-wrap sockets
- `2 x DIP-14` wire-wrap sockets

### Board-local passives

- `4 x 0.1uF` decoupling capacitors minimum
- `1 x 47uF to 470uF` bulk capacitor

## Combined Electronics Totals

### CPUs

- `1 x 8085A`
- `1 x MC6809P`
- `1 x HD63C09RP` reserved for validation, not simultaneous installation

### Memory

- `1 x AS6C62256-55PIN`
- `1 x AS6C6264-55PCN`
- `1 x AT28C64B-15PU`

### TTL and glue

- `1 x SN74LS373N`
- `3 x SN74LS245N`
- `3 x SN74LS138N`
- `1 x SN74LS139AN`
- `3 x SN74LS273N`
- `3 x SN74LS00N`
- `1 x SN74LS32N`
- `2 x SN74LS04N`
- `1 x SN74LS244N`
- `1 x SN74LS164N`
- `1 x SN74LS86AN`
- `1 x SN74LS74N`
- `1 x SN74LS14N`

### Clock and reset

- `1 x 5 MHz crystal`
- `2 x 22pF`
- `1 x` canned oscillator module
- `2 x` reset pushbuttons total
- `7 x 10k` resistors minimum on the two CPU boards
- `2 x 1uF to 10uF` reset capacitors

### Sockets

- `2 x DIP-40` wire-wrap sockets
- `7 x DIP-20` wire-wrap sockets
- `3 x DIP-16` wire-wrap sockets
- `6 x DIP-14` wire-wrap sockets
- `3 x DIP-28` wire-wrap sockets
- `3 x DIP-28 ZIF` sockets

### Shared passives and indicators

- `26 x 0.1uF` decoupling capacitors minimum
- `4 x` bulk electrolytics
- `16 x 330R`
- `16 x LEDs`
- `2 x` DIP switch packs

## Stock Fit Notes

This concrete plan fits the current repo stock fairly well in concept, but several parts are still not tracked cleanly in `inventory/list.csv`.

Most likely strong fits:

- CPUs
- memory devices
- `DIP-40`, `DIP-28`, `DIP-16`, and `DIP-14` sockets
- wire-wrap wire
- board stock for one `4-board` set

Most likely weak or untracked areas:

- some TTL entries not normalized into the inventory CSV
- `330R` quantity if the CSV is treated as strict truth
- `DIP-20` socket quantity if the CSV is treated as strict truth
- canned oscillator module choice
- operator switches, test posts, and small bench accessories

## `HD63C09RP` Versus `MC6809P`

### No additional mandatory hardware for first-pass compatibility

If you use the `HD63C09RP` as a drop-in test CPU on the same conservative board:

- no extra memory hardware
- no extra decode hardware
- no extra I/O hardware

### Additional support only if you pursue higher-performance use

Potential later support work:

- revalidate ROM and bus timing at higher clock rates
- possibly revisit wait-state strategy if you drive the board faster
- consider software changes only if you want native `HD63C09RP` instructions or modes

### Practical recommendation

- build and debug `Board A-6x09` with `MC6809P`
- confirm ROM fetch, RAM handoff, `MMA/MMD`, and Beta seed behavior
- only then test the `HD63C09RP`

## Suggested Next Artifact

The next high-value document would be:

- a socket-level `Board A-6x09` population and clock note

That would let the provisional oscillator entry collapse into a final part choice and tighten the `6x09` inventory gap analysis.

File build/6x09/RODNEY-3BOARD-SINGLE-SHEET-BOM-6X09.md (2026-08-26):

# Rodney `6x09` 3-Board Single-Sheet BOM

Single-sheet build of materials for the current `3 x Vector 8801-6` bench-first Rodney redesign targeting `MC6809P` first and `HD63C09RP` compatibility second.

This BOM is specific to the `build/6x09` redesign track and does **not** replace the canonical `8085` BOM.

Companion docs:

- [6X09-BOM-DELTA.md](/home/cartheur/ame/aiventure/aiventure-github/cartheur/aiventure-rodney/build/6x09/6X09-BOM-DELTA.md:1)
- [BOARD-A-SIGNAL-SUBSTITUTIONS.md](/home/cartheur/ame/aiventure/aiventure-github/cartheur/aiventure-rodney/build/6x09/BOARD-A-SIGNAL-SUBSTITUTIONS.md:1)
- [MEMORY-AND-DECODE-PROPOSAL.md](/home/cartheur/ame/aiventure/aiventure-github/cartheur/aiventure-rodney/build/6x09/MEMORY-AND-DECODE-PROPOSAL.md:1)
- [BRING-UP-PLAN.md](/home/cartheur/ame/aiventure/aiventure-github/cartheur/aiventure-rodney/build/6x09/BRING-UP-PLAN.md:1)

## Assumptions

- This is the `6x09` behavioral-architecture build, not a historically strict Heiserman `8085` reconstruction.
- First-pass CPU target is `MC6809P`.
- Board and software layout should remain compatible with a later `HD63C09RP` drop-in test.
- The logical `ENVL` / `ACTL` / `MMA` / `MMD` model is preserved.
- All I/O remains memory-mapped.
- ROM must occupy high memory so the CPU can fetch vectors at `FFF0-FFFF`.
- `Board A` clock-generation details are still provisional; the BOM therefore includes a required clock block but marks exact implementation notes as provisional.

## Single-Sheet BOM

| Check | Category | Item | Footprint | Qty | Board / Use | Notes |
|---|---|---|---|---:|---|---|
| `[ ]` | Core | Vector `8801-6` wire-wrap plugboard | `S-100 / 100-pin board` | 3 | `A, B, C` | one board per function |
| `[ ]` | Core | `100-pin` wire-wrap edge connector | `100-pin edge connector` | 2 | `Board A`, `Board B` | `Board C` remains hard-wired |
| `[ ]` | Core | `0.1"` male header strips | `0.1" header` | 4 | all boards | bus, service, debug |
| `[ ]` | Core | test posts / turret posts | `turret / post` | 18 | all boards | `6 + 8 + 4` top-edge minimum |
| `[ ]` | Core | hard-wire interboard harness anchor points | `lug / header / clamp` | 1 set | `Board C` | header, solder lugs, or strain-relieved tie points |
| `[ ]` | CPU board | `MC6809P` CPU | `DIP-40` | 1 | `Board A` | first-pass target CPU |
| `[ ]` | CPU board | `HD63C09RP` compatibility | note | 1 note | `Board A` | layout and software should allow later drop-in validation |
| `[ ]` | CPU board | `74LS245` | `DIP-20` | 1 | `Board A` | provisional data-bus buffering / inter-board isolation |
| `[ ]` | CPU board | `74LS138` | `DIP-16` | 1 | `Board A` | provisional coarse decode or chip-select assist |
| `[ ]` | CPU board | `74LS04` | `DIP-14` | 1 | `Board A` | provisional clock/reset glue |
| `[ ]` | CPU board | `74LS00` | `DIP-14` | 1 | `Board A` | provisional glue logic |
| `[ ]` | CPU board | canned oscillator or conservative clock source | module / oscillator | 1 | `Board A` | provisional `6x09` clock block; exact part depends on final `E/Q` generation plan |
| `[ ]` | CPU board | clock-support passives | assorted small passives | 1 set | `Board A` | only as required by final clock block |
| `[ ]` | CPU board | reset pushbutton | `panel / PCB switch` | 1 | `Board A` | top-edge service area |
| `[ ]` | CPU board | `10k` resistor | `axial resistor` | 5 | `Board A` | reset network plus inactive pulls for `NMI`, `IRQ`, and `FIRQ` |
| `[ ]` | CPU board | `1uF` to `10uF` capacitor | `radial electrolytic` | 1 | `Board A` | reset timing |
| `[ ]` | Memory board | `62256` SRAM | `DIP-28` | 1 | `Board B` | learned main memory; selected part `AS6C62256-55PIN` |
| `[ ]` | Memory board | `6264` SRAM | `DIP-28` | 1 | `Board B` | program RAM; selected part `AS6C6264-55PCN` |
| `[ ]` | Memory board | `AT28C64B-15PU` EEPROM | `DIP-28` | 1 | `Board B` | support ROM; decode at high memory for vector fetch |
| `[ ]` | Memory board | `74LS138` | `DIP-16` | 1 | `Board B` | region decode |
| `[ ]` | Memory board | `74LS139` | `DIP-16` | 1 | `Board B` | subdecode |
| `[ ]` | Memory board | `74LS273` | `DIP-20` | 2 | `Board B` | `MMA low`, `MMA high` |
| `[ ]` | Memory board | `74LS245` | `DIP-20` | 1 | `Board B` | `MMD` path / data isolation |
| `[ ]` | Memory board | `74LS00` | `DIP-14` | 1 | `Board B` | decode glue |
| `[ ]` | Memory board | `74LS32N` | `DIP-14` | 1 | `Board B` | planned decode / glue flexibility |
| `[ ]` | I/O board | `74LS244` | `DIP-20` | 1 | `Board C` | input buffer |
| `[ ]` | I/O board | `74LS273` | `DIP-20` | 1 | `Board C` | output latch |
| `[ ]` | I/O board | `74LS164` | `DIP-14` | 1 | `Board C` | pseudo-random source |
| `[ ]` | I/O board | `74LS86` | `DIP-14` | 1 | `Board C` | XOR feedback |
| `[ ]` | I/O board | `8-position` DIP switch | `DIP switch, 8-pos` | 2 | `Board C` | `ENVL`, `ENVH`; selected part `CTS 195-8MST` |
| `[ ]` | I/O board | `5mm` LEDs | `T-1 3/4` | 16 | `Board C` | `ACTL` plus debug / `ACTH` |
| `[ ]` | I/O board | LED resistors `330R` | `axial resistor` | 16 | `Board C` | one per LED |
| `[ ]` | I/O board | momentary switches | `panel / PCB switch` | 2 | `Board C` | mode / test |
| `[ ]` | I/O board | `10k` resistor network or discrete pull-ups | `SIP network or axial` | 2 | `Board C` | switch pulls |
| `[ ]` | Sockets | `DIP-40` wire-wrap socket | `DIP-40 WW socket` | 1 | `Board A` | `MC6809P` / `HD63C09RP` CPU socket |
| `[ ]` | Sockets | `DIP-28` wire-wrap socket | `DIP-28 WW socket` | 3 | `Board B` | `62256`, `6264`, EEPROM |
| `[ ]` | Sockets | `DIP-20` wire-wrap socket | `DIP-20 WW socket` | 5 | `A, B, C` | `1 + 3 + 1` |
| `[ ]` | Sockets | `DIP-16` wire-wrap socket | `DIP-16 WW socket` | 2 | `A, B` | `1 + 1` |
| `[ ]` | Sockets | `DIP-14` wire-wrap socket | `DIP-14 WW socket` | 4 | `A, B, C` | `2 + 1 + 1` |
| `[ ]` | Sockets | `DIP-28 ZIF` socket | `DIP-28 ZIF` | 3 required | `Board B` | `U1`, `U7`, and `U8`; `1` spare recommended |
| `[ ]` | Passive | `0.1uF` ceramic decoupling capacitors | `radial / ceramic` | 15 | all boards | one per IC minimum in current first-pass population |
| `[ ]` | Passive | bulk electrolytic `47uF` to `470uF` | `radial electrolytic` | 3 | `A, B, C` | one per board |
| `[ ]` | Passive | extra `10k` resistors | `axial resistor` | 8 | general | pull-ups, glue, spare |
| `[ ]` | Passive | extra `1k` resistors | `axial resistor` | 4 | general | optional indicators / glue |
| `[ ]` | Wiring | `30 AWG` Kynar wire-wrap wire | `spool` | 3 to 5 spools | all boards | multiple colors preferred |
| `[ ]` | Wiring | `22-24 AWG` hookup wire, red | `spool` | 1 spool | power | `+5V` |
| `[ ]` | Wiring | `22-24 AWG` hookup wire, black | `spool` | 1 spool | power | `GND` |
| `[ ]` | Wiring | `16- to 26-conductor` ribbon or grouped cable | `cable` | 2 lengths | `CAB-A-B`, `CAB-A-C` | one connectorized cable and one fixed harness |
| `[ ]` | Wiring | cable lacing, zip ties, or harness clamps | `consumable` | 1 pack | stack harness | recommended for the hard-wired board |
| `[ ]` | Mechanical | standoffs / board supports | `hardware set` | 1 set | rack | enough for `3` boards |
| `[ ]` | Mechanical | labels or masking tape flags | `consumable` | 1 pack | build aid | cable and signal marking |
| `[ ]` | Power | `+5V` USB battery supply | `USB power bank` | 1 | bring-up | selected bench source for first logic bring-up |
| `[ ]` | Power | HP `5004A` signature-analyzer clip leads | `grabber / clip lead` | 2 | bring-up | used to clip `+5V` and `GND` onto board input pins |
| `[ ]` | Power | wall-powered `+5V` bench supply | `bench supply` | 1 optional | fallback | use if the USB source shows droop or unstable behavior |
| `[ ]` | Tools | `Batronix BX32P Barlino II` programmer | `USB EPROM / EEPROM programmer` | 1 optional | ROM programming | suitable for planned `28C` EEPROM workflow |
| `[ ]` | Tools | wire-wrap tool | `hand tool` | 1 | build | manual or powered |
| `[ ]` | Tools | unwrap tool | `hand tool` | 1 | build | strongly recommended |
| `[ ]` | Tools | `Weller` soldering iron | `bench tool` | 1 | build | connectors, headers |
| `[ ]` | Tools | logic probe | `bench tool` | 1 | debug | recommended |
| `[ ]` | Tools | oscilloscope | `bench instrument` | 1 | debug | strongly recommended for `E/Q`, reset, and vector-fetch bring-up |

## Quick Totals

Baseline first-pass `6x09` build:

| Type | Qty |
|---|---:|
| Boards | 3 |
| Edge connectors | 2 |
| ICs on sockets | 16 plus `1` CPU and `1` ROM |
| Wire-wrap sockets total | 15 |
| DIP-28 memory devices populated | 3 |
| Top-edge test posts minimum | 18 |
| LEDs | 16 |
| DIP switch packs | 2 |
| Bulk capacitors | 3 |
| `0.1uF` decouplers minimum | 15 |

Counting note:

- `Board A` intentionally drops the `74LS373` from the `8085` baseline
- the exact clock module is still provisional and therefore not counted as a DIP IC

## Board A Notes

- `74LS373` is intentionally omitted from this BOM.
- CPU choice for bring-up should be `MC6809P`; validate `HD63C09RP` after the baseline board is stable.
- The clock source entry is intentionally generic because the final `E/Q` generation method has not yet been frozen.
- If the final `Board A` schematic proves that `74LS245` or `74LS138` is unnecessary, remove them in the next revision of this `6x09` BOM only.

## ROM And Map Notes

- Program RAM remains at `0000-1FFF`.
- ROM should decode into `E000-FFEF`.
- vectors must remain valid at `FFF0-FFFF`.
- `ENVL`, `ENVH`, `TSWR`, `MMA_L`, `MMA_H`, `MMD`, `ACTL`, and `ACTH` remain memory-mapped in the `8000` page.

## Inventory Fit

This BOM aligns well with the current on-hand stock snapshot:

- CPUs are already on hand for both `MC6809P` and `HD63C09RP`
- memory devices are already well covered
- the required TTL family is mostly already present
- the main unresolved item is the exact `Board A` clock implementation, not overall parts availability

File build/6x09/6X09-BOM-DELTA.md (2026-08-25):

# Rodney `6x09` BOM Delta

This document defines the parts delta between the current `8085` Rodney bench build and the proposed `6809` / `6309` redesign track.

It does **not** modify the original `8085` BOM documents.

Local reference copies used by this folder:

- [RODNEY-3BOARD-SINGLE-SHEET-BOM-8085-REFERENCE.md](/home/cartheur/ame/aiventure/aiventure-github/cartheur/aiventure-rodney/build/6x09/RODNEY-3BOARD-SINGLE-SHEET-BOM-8085-REFERENCE.md:1)
- [RODNEY-3BOARD-SINGLE-SHEET-BOM-8085-REFERENCE.csv](/home/cartheur/ame/aiventure/aiventure-github/cartheur/aiventure-rodney/build/6x09/RODNEY-3BOARD-SINGLE-SHEET-BOM-8085-REFERENCE.csv:1)
- [RODNEY-ON-HAND-STOCK-REFERENCE.md](/home/cartheur/ame/aiventure/aiventure-github/cartheur/aiventure-rodney/build/6x09/RODNEY-ON-HAND-STOCK-REFERENCE.md:1)

Related `6x09` design notes:

- [BOARD-A-SIGNAL-SUBSTITUTIONS.md](/home/cartheur/ame/aiventure/aiventure-github/cartheur/aiventure-rodney/build/6x09/BOARD-A-SIGNAL-SUBSTITUTIONS.md:1)
- [MEMORY-AND-DECODE-PROPOSAL.md](/home/cartheur/ame/aiventure/aiventure-github/cartheur/aiventure-rodney/build/6x09/MEMORY-AND-DECODE-PROPOSAL.md:1)
- [BRING-UP-PLAN.md](/home/cartheur/ame/aiventure/aiventure-github/cartheur/aiventure-rodney/build/6x09/BRING-UP-PLAN.md:1)

## Summary

The `6x09` redesign reuses most of:

- the physical `3-board` structure
- all `Board B` memory devices
- nearly all `Board C` bench I/O devices
- most sockets, wiring, headers, passives, and bench tooling

The main BOM impact is concentrated on `Board A`.

In practical terms:

- `Board B` is mostly unchanged
- `Board C` is effectively unchanged
- `Board A` is partly reusable and partly a respin

## Keep As-Is

These parts remain directly useful with no design change implied.

### Core and mechanical

- `Vector 8801-6` boards
- `100-pin` edge connectors
- `0.1"` header strips
- test posts / turret posts
- harness anchor hardware
- standoffs / supports

### Memory board

- `62256` SRAM
- `6264` SRAM
- `AT28C64B-15PU` EEPROM
- `74LS138`
- `74LS139`
- `74LS273` for `MMA_L` and `MMA_H`
- `74LS245` for `MMD` path isolation
- `74LS00`
- `74LS32`

### I/O board

- `74LS244`
- `74LS273`
- `74LS164`
- `74LS86`
- `8-position` DIP switches
- LEDs
- LED resistors
- momentary switches
- pull-ups / resistor networks

### Shared stock

- `DIP-28` wire-wrap sockets
- `DIP-20` wire-wrap sockets
- `DIP-16` wire-wrap sockets
- `DIP-14` wire-wrap sockets
- `DIP-28 ZIF` sockets
- `0.1uF` decouplers
- bulk capacitors
- `10k`, `1k`, `330R` resistor stock
- `30 AWG` Kynar
- red and black hookup wire
- ribbon cable / grouped cable
- USB bench power concept
- clip leads
- soldering and wire-wrap tools

## Drop From The `6x09` Variant

These items are specific to the `8085` baseline and should not appear in the `6x09` BOM unless a later schematic creates a new reason for them.

- `8085A`
- `74LS373` low-address latch used for `AD0-AD7` de-multiplexing

Why:

- the `6809` / `6309` present separate address and data buses
- the `ALE`-driven latch path is no longer the board's defining feature

## Replace

These baseline BOM items need explicit replacement or reclassification in the `6x09` BOM.

| `8085` baseline item | `6x09` action | Current recommendation |
|---|---|---|
| `8085A` CPU | replace | use `6809` for bring-up, validate `6309` later |
| `DIP-40` CPU socket tagged `8085A` | retain but relabel | still a `DIP-40` CPU socket if final package stays `6809P` / `6309RP` |
| `5 MHz` crystal plan | replace or mark provisional | final `6x09` clock source must follow the chosen `E/Q` strategy |
| `74LS04` clock/reset glue | retain but redesign role | still likely useful, but not as a copied `8085` clock network |
| `74LS00` glue logic on `Board A` | retain but redesign role | still likely useful, but exact gates depend on `R/W`, reset, and ROM timing |
| `74LS245` `Board A` transceiver | retain provisionally | likely still useful for inter-board bus buffering, but direction logic must be redone |

## Add Or Promote For The `6x09` BOM

These are not guaranteed new purchases, but they need to be explicit in the `6x09` BOM rather than left implied by the `8085` design.

- `6809` CPU entry
- `6309` compatibility note
- `Board A` `E` / `Q` clock-generation block
- `Board A` reset and vector-fetch timing notes
- pull-ups for `NMI`, `IRQ`, and `FIRQ`
- any wait-state or `MRDY` support if the final board needs it

## Board-By-Board Delta

### Board A

Keep:

- `DIP-40` CPU socket footprint class
- reset pushbutton
- `10k` reset-network resistors
- reset timing capacitor
- top-edge test-point strategy
- optional `74LS245`
- optional `74LS138`
- likely `74LS04`
- likely `74LS00`

Drop:

- `8085A`
- `74LS373`
- any `ALE`-specific routing assumption

Rework:

- clock source
- reset timing details
- ROM / RAM read-write timing assumptions
- `R/W`-derived control strobes

### Board B

Keep almost unchanged:

- `62256`
- `6264`
- EEPROM
- `74LS138`
- `74LS139`
- `74LS273`
- `74LS245`
- `74LS00`
- `74LS32`

Main `6x09` change:

- ROM decoding must satisfy high-memory vector fetch at `FFF0-FFFF`

### Board C

Keep unchanged in first pass:

- input buffer
- output latch
- pseudo-random source
- switches
- LEDs
- pull-ups

## Inventory Fit

Using [inventory/list.csv](/home/cartheur/ame/aiventure/aiventure-github/cartheur/aiventure-rodney/inventory/list.csv:1) and the current on-hand summary:

Already covered well:

- `6809` CPUs
- `6309` CPUs
- `62256`
- `6264`
- `AT28C64B`
- `74LS00`
- `74LS04`
- `74LS373` even though the `6x09` variant likely drops it
- `DIP-40`, `DIP-28`, `DIP-16`, and `DIP-14` sockets
- boards, connectors, wire, and memory stock

Covered but still schematic-dependent:

- whether the existing `5 MHz` crystals are the right fit for the final `6x09` clock method
- whether `74LS245` remains the preferred `Board A` buffer part
- whether one `74LS138` is enough on `Board A` or if decode shifts more heavily to `Board B`

## Current Readiness Verdict

For a first `6809` prototype, the stock situation looks promising.

For a final `6x09` BOM, the unresolved items are not general availability problems. They are mostly:

- exact `Board A` clock design
- exact `Board A` control-glue design
- whether the first pass should be `6809`-only or explicitly `6809` / `6309` dual-qualified

## Recommended Next BOM Step

Before declaring the `6x09` parts list finished, add one more artifact:

- a `Board A` device-level draft schematic or socket map

Once that exists, the open BOM questions should collapse quickly into:

- confirmed keep items
- confirmed deletions
- a very short list of truly new parts, if any

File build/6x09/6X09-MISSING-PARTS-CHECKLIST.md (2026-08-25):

# Rodney `6x09` Missing Parts Checklist

Working checklist for the current `6x09` BOM against the tracked inventory.

This file is intentionally pragmatic. It separates:

- parts that appear genuinely missing from `inventory/list.csv`
- parts that appear short in quantity
- parts that may already exist physically but are not tracked cleanly enough yet

Primary references:

- [RODNEY-3BOARD-SINGLE-SHEET-BOM-6X09.md](/home/cartheur/ame/aiventure/aiventure-github/cartheur/aiventure-rodney/build/6x09/RODNEY-3BOARD-SINGLE-SHEET-BOM-6X09.md:1)
- [inventory/list.csv](/home/cartheur/ame/aiventure/aiventure-github/cartheur/aiventure-rodney/inventory/list.csv:1)
- [RODNEY-ON-HAND-STOCK-REFERENCE.md](/home/cartheur/ame/aiventure/aiventure-github/cartheur/aiventure-rodney/build/6x09/RODNEY-ON-HAND-STOCK-REFERENCE.md:1)
- [build-of-materials/RODNEY-ON-HAND-STOCK.md](/home/cartheur/ame/aiventure/aiventure-github/cartheur/aiventure-rodney/build-of-materials/RODNEY-ON-HAND-STOCK.md:1)

Date basis:

- checked against repo state on `2026-08-25`

## 1. Missing From `inventory/list.csv`

These parts are required by the current `6x09` BOM but do not appear explicitly in `inventory/list.csv`.

### TTL and logic support

- `[ ]` `74LS245` x2 total
- `[ ]` `74LS138` x2 total
- `[ ]` `74LS139` x1
- `[ ]` `74LS273` x3 total
- `[ ]` `74LS244` x1
- `[ ]` `74LS164` x1
- `[ ]` `74LS86` x1
- `[ ]` `74LS32N` x1

### Operator / panel parts

- `[ ]` `8-position` DIP switch x2
- `[ ]` reset / momentary pushbuttons x3 total

### Socket and service items

- `[ ]` `DIP-28 ZIF` socket x3 required
- `[ ]` `0.1"` header strips x4
- `[ ]` test posts / turret posts x18
- `[ ]` hard-wire harness anchor hardware x1 set

### Passives and support stock

- `[ ]` `1k` resistors x4
- `[ ]` `0.1uF` decoupling capacitors x15
- `[ ]` bulk electrolytics `47uF` to `470uF` x3

### Mechanical and bring-up items

- `[ ]` standoffs / board supports x1 set
- `[ ]` labels / tape flags x1 pack
- `[ ]` `+5V` USB power bank x1
- `[ ]` HP `5004A` clip leads x2
- `[ ]` logic probe x1
- `[ ]` oscilloscope x1

### `Board A` provisional clock block

- `[ ]` canned oscillator or conservative clock-source module x1
- `[ ]` clock-support passives x1 set

## 2. Quantity Shortfalls In `inventory/list.csv`

These parts do exist in `inventory/list.csv`, but the recorded quantity is below the current `6x09` BOM need.

- `[ ]` `330R` resistor: need `16`, inventory lists `10`, short by `6`

## 3. Probably On Hand But Not Tracked Cleanly

These items are described as available, planned, or purchased in the stock notes, but are not represented clearly enough in `inventory/list.csv` to trust as inventory truth.

### TTL and memory support likely covered by stock notes

- `[ ]` `74LS245`
- `[ ]` `74LS138`
- `[ ]` `74LS139`
- `[ ]` `74LS273`
- `[ ]` `74LS244`
- `[ ]` `74LS164`
- `[ ]` `74LS86`
- `[ ]` `74LS32N`
- `[ ]` `AT28C64B-15PU` status should be confirmed as truly on hand vs planned
- `[ ]` `AS6C6264-55PCN` status should be confirmed as truly on hand vs planned

### Socket and switch stock likely covered outside `inventory/list.csv`

- `[ ]` `DIP-28 ZIF` sockets
- `[ ]` `CTS 195-8MST` DIP switches

### Bench and build accessories likely untracked

- `[ ]` test posts / turret posts
- `[ ]` header-strip stock
- `[ ]` pushbutton stock
- `[ ]` standoff / support hardware
- `[ ]` labels / cable-marking supplies
- `[ ]` clip leads
- `[ ]` logic probe
- `[ ]` oscilloscope

## 4. Not Missing

These parts appear adequately covered for one `6x09` unit.

- `[x]` `6809` CPU family
- `[x]` `6309` later validation CPU family
- `[x]` `62256` SRAM
- `[x]` `DIP-40` wire-wrap socket
- `[x]` `DIP-28` wire-wrap sockets
- `[x]` `DIP-16` wire-wrap sockets
- `[x]` `DIP-14` wire-wrap sockets
- `[x]` `10k` resistors
- `[x]` `Vector 8801-6` boards for one unit
- `[x]` `R681-2` edge connectors for one unit
- `[x]` `30 AWG` Kynar wire
- `[x]` red power wire
- `[x]` black power wire

## 5. Important Interpretation Notes

- This checklist is intentionally conservative and uses `inventory/list.csv` as the strongest evidence.
- The stock summary documents suggest several of the "missing" TTL parts may actually already be present, but that has not been normalized into the inventory CSV.
- The `Board A` clock block is still architecturally unresolved, so its exact missing part number is not yet knowable.

## 6. Recommended Cleanup Order

1. Confirm and normalize all TTL stock into `inventory/list.csv`.
2. Correct the `6x09` BOM counting errors for sockets and decouplers.
3. Decide the `Board A` clock scheme.
4. Re-run the gap check once the clock part and the inventory normalization are complete.

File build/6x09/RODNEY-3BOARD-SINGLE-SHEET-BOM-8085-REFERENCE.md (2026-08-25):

# Rodney `8085` Baseline BOM Reference

Copied into `build/6x09` on `2026-08-25` so the `6x09` redesign can work against a local BOM snapshot without altering the source `8085` documents.

Canonical source:

- [build-of-materials/RODNEY-3BOARD-SINGLE-SHEET-BOM.md](/home/cartheur/ame/aiventure/aiventure-github/cartheur/aiventure-rodney/build-of-materials/RODNEY-3BOARD-SINGLE-SHEET-BOM.md:1)

This is a trimmed working reference rather than a new canonical BOM.

## Baseline Core

| Category | Item | Qty | Board / Use |
|---|---|---:|---|
| Core | Vector `8801-6` wire-wrap plugboard | 3 | `A, B, C` |
| Core | `100-pin` wire-wrap edge connector | 2 | `Board A`, `Board B` |
| Core | `0.1"` male header strips | 4 | all boards |
| Core | test posts / turret posts | 18 | all boards |
| Core | hard-wire interboard harness anchor points | 1 set | `Board C` |

## Baseline `Board A`

| Item | Qty | Notes |
|---|---:|---|
| `8085A` | 1 | CPU |
| `74LS373` | 1 | address latch |
| `74LS245` | 1 | data transceiver |
| `74LS138` | 1 | coarse decode |
| `74LS04` | 1 | clock/reset glue |
| `74LS00` | 1 | glue logic |
| crystal `5 MHz` | 1 | selected standard |
| `22pF` crystal load capacitors | 2 | if crystal circuit uses them |
| reset pushbutton | 1 | service area |
| `10k` resistor | 2 | reset network |
| `1uF` to `10uF` capacitor | 1 | reset timing |

## Baseline `Board B`

| Item | Qty | Notes |
|---|---:|---|
| `62256` SRAM | 1 | main memory |
| `6264` SRAM | 1 | program RAM |
| `AT28C64B-15PU` EEPROM | 1 | monitor / bootstrap |
| `74LS138` | 1 | region decode |
| `74LS139` | 1 | subdecode |
| `74LS273` | 2 | `MMA low`, `MMA high` |
| `74LS245` | 1 | `MMD` path |
| `74LS00` | 1 | decode glue |
| `74LS32N` | 1 | planned glue flexibility |
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

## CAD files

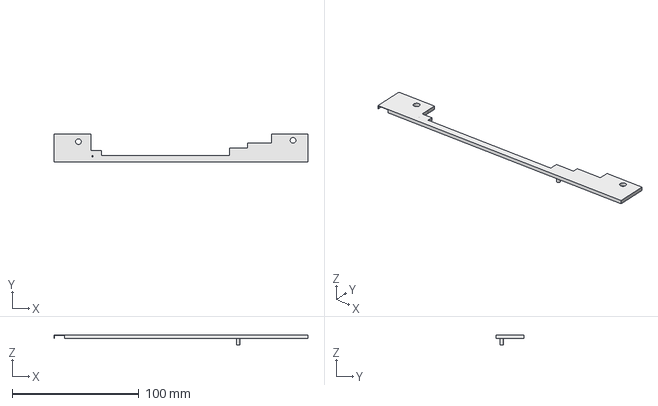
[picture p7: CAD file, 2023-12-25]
development/3D-models/vector-support-left.FCStd
200.0 x 22.0 x 7.50 mm

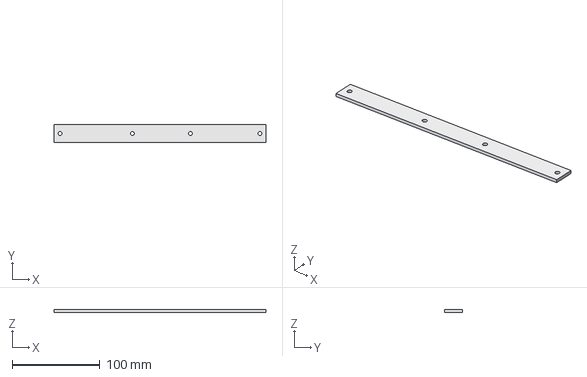
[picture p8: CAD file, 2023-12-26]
development/3D-models/wire-board/2-folding-hinge-rear-bar.FCStd
241.0 x 20.0 x 3.00 mm

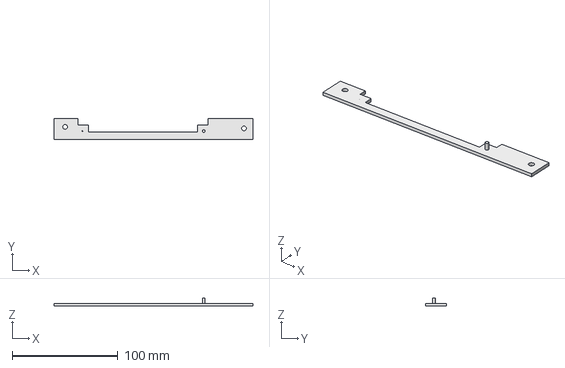
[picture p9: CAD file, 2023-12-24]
development/3D-models/vector-support-right.FCStd
188.0 x 20.0 x 8.00 mm

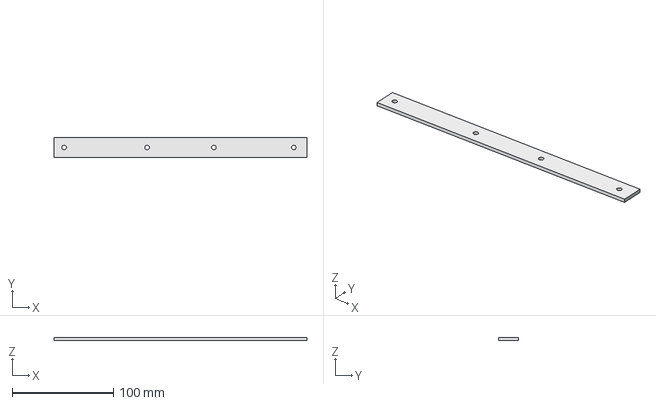
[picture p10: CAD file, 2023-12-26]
development/3D-models/wire-board/1-folding-hinge-rear-bar.FCStd
250.0 x 20.0 x 3.00 mm

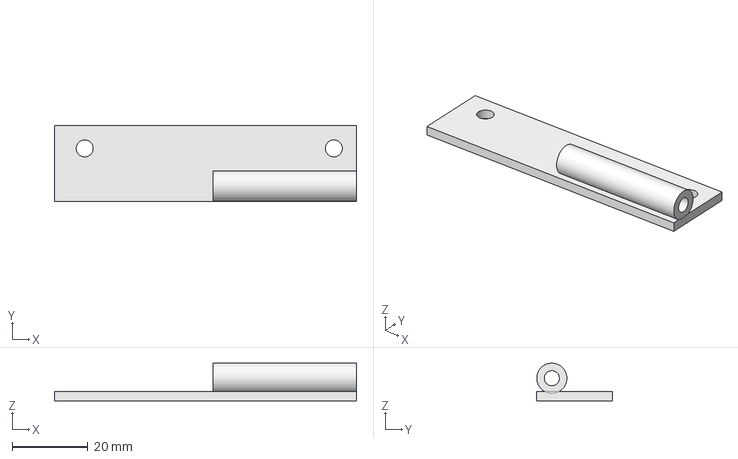
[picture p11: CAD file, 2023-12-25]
development/3D-models/wire-board/1-folding-hinge.FCStd
80.0 x 20.0 x 10.00 mm

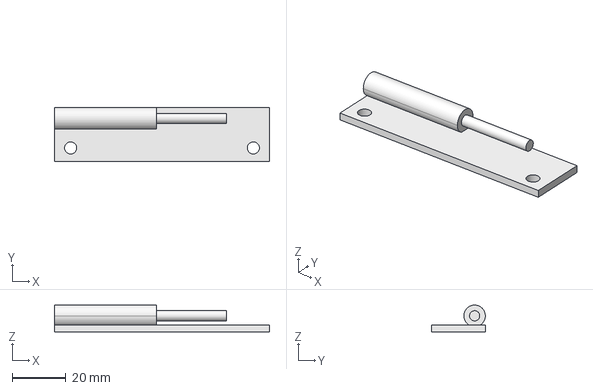
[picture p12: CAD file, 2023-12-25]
development/3D-models/wire-board/1-folding-hinge-pin.FCStd
80.0 x 20.0 x 10.00 mm

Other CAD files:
development/3D-models/vector-support-left.stl
development/3D-models/vector-support-right.stl
development/3D-models/wire-board/1-folding-hinge-pin.stl
development/3D-models/wire-board/1-folding-hinge-rear-bar.stl
development/3D-models/wire-board/1-folding-hinge.stl
development/3D-models/wire-board/2-folding-hinge-rear-bar.stl

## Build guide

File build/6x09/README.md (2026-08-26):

# Rodney `6x09` Redesign Track

Short revision flow:

- `Rev. 0`: `i8085` on `Board A`
- `Rev. 1`: `MC6809P` + `GA144` on `Board A`
- `Rev. 2`: `HD63C09RP` + `GA144` on `Board A`
- `Rev. 3`: `MC6809P/HD63C09RP/SC67475P` + `GA144` on `Board A`

From `Rev. 1` onward, the crystal is treated as the borderline where conventional CPU timing meets `GA144`-driven resonant excitation and control.

Per `AN002`, the idea is to connect the resonant device to a single `GA144` GPIO pin and ground, excite it under program control, observe it via asynchronous pin wake-up, and then sustain oscillation by synchronously pumping energy back into the crystal with minimal external circuitry.

This folder captures what it would take to pivot the current Rodney bench-first architecture away from the `8085A` and onto a `6809` or `6309`.

The key distinction is:

- if the goal is a historically faithful Heiserman reconstruction, stay with the `8085`
- if the goal is preserving Rodney's **learning architecture** on a friendlier 8-bit CPU, the `6x09` family is a strong candidate

The existing repo already separates those concerns fairly well:

- the current wire-wrap architecture preserves the **behavioral model**
- the current implementation details are still very `8085`-specific

So this redesign is best understood as:

- a new `Board A` CPU/bus design
- moderate decode and reset changes
- near-total assembly rewrite
- minimal conceptual change to the `ENVL` / `ACTL` / `MMA` / `MMD` model

## Recommendation

Recommended path:

1. target the plain `6809` first
2. keep the hardware and source compatible with the `6309`
3. treat the `6309` as a later performance and cleanup upgrade, not the bring-up baseline

Why:

- `6809` bring-up is simpler and better documented
- `6309` can usually drop into a `6809`-clean design later
- debugging a fresh board and a CPU superset at the same time adds avoidable risk

The inventory already supports this direction:

- `MC6809P`
- `HD63C09RP`
- `SC67475P`

And for the crystal-boundary side of the revision ladder:

- [AN002-171106-OSC.pdf](/home/cartheur/ame/aiventure/aiventure-github/cartheur/aiventure-rodney/build/6x09/AN002-171106-OSC.pdf) now anchors the `GA144` oscillator / resonant-device approach

## Scope Of Change

### What must be redesigned

- `Board A` CPU socket region
- clock generation for `E` / `Q`
- reset, interrupt, and halt handling
- address and control decode assumptions
- bootstrap and monitor assembly
- Beta and Gamma assembly sources

### What can stay conceptually intact

- `3-board` partitioning
- memory-mapped `ENVL`, `ENVH`, `TSWR`, `ACTL`, `ACTH`
- indirect learned-memory access through `MMA_L`, `MMA_H`, and `MMD`
- bench-first switch and LED I/O strategy
- learned-byte format:
  - low nibble = action
  - upper bits = confidence

## Practical Assessment

This is not a "swap the CPU and reassemble" project.

It is closer to:

- `60%` hardware respin of the CPU/bus layer
- `100%` rewrite of the assembly sources
- `10-20%` rethink of memory decode and bring-up procedures

The payoff is real, though:

- the `6809` is a cleaner CPU to program
- indexed addressing is much better suited to table-heavy learning code
- stack and subroutine support are stronger than the `8085`
- the `6309` offers a later speed path if Gamma passes become expensive

## Files In This Folder

- [BOARD-A-SIGNAL-SUBSTITUTIONS.md](/home/cartheur/ame/aiventure/aiventure-github/cartheur/aiventure-rodney/build/6x09/BOARD-A-SIGNAL-SUBSTITUTIONS.md:1)
- [BRING-UP-PLAN.md](/home/cartheur/ame/aiventure/aiventure-github/cartheur/aiventure-rodney/build/6x09/BRING-UP-PLAN.md:1)
- [CONCRETE-BOM-4BOARD-8085-AND-6X09.md](/home/cartheur/ame/aiventure/aiventure-github/cartheur/aiventure-rodney/build/6x09/CONCRETE-BOM-4BOARD-8085-AND-6X09.md:1)
- [AN002-GA144-CRYSTAL-BOUNDARY.md](/home/cartheur/ame/aiventure/aiventure-github/cartheur/aiventure-rodney/build/6x09/AN002-GA144-CRYSTAL-BOUNDARY.md:1)
- [6X09-BOM-DELTA.md](/home/cartheur/ame/aiventure/aiventure-github/cartheur/aiventure-rodney/build/6x09/6X09-BOM-DELTA.md:1)
- [6X09-MISSING-PARTS-CHECKLIST.md](/home/cartheur/ame/aiventure/aiventure-github/cartheur/aiventure-rodney/build/6x09/6X09-MISSING-PARTS-CHECKLIST.md:1)
- [REV1-PHASE2-MMU-ANALYSIS.md](/home/cartheur/ame/aiventure/aiventure-github/cartheur/aiventure-rodney/build/6x09/REV1-PHASE2-MMU-ANALYSIS.md:1)
- [MEMORY-AND-DECODE-PROPOSAL.md](/home/cartheur/ame/aiventure/aiventure-github/cartheur/aiventure-rodney/build/6x09/MEMORY-AND-DECODE-PROPOSAL.md:1)
- [RODNEY-3BOARD-SINGLE-SHEET-BOM-6X09.md](/home/cartheur/ame/aiventure/aiventure-github/cartheur/aiventure-rodney/build/6x09/RODNEY-3BOARD-SINGLE-SHEET-BOM-6X09.md:1)
- [RODNEY-3BOARD-SINGLE-SHEET-BOM-6X09.csv](/home/cartheur/ame/aiventure/aiventure-github/cartheur/aiventure-rodney/build/6x09/RODNEY-3BOARD-SINGLE-SHEET-BOM-6X09.csv:1)
- [RODNEY-3BOARD-SINGLE-SHEET-BOM-8085-REFERENCE.md](/home/cartheur/ame/aiventure/aiventure-github/cartheur/aiventure-rodney/build/6x09/RODNEY-3BOARD-SINGLE-SHEET-BOM-8085-REFERENCE.md:1)
- [RODNEY-3BOARD-SINGLE-SHEET-BOM-8085-REFERENCE.csv](/home/cartheur/ame/aiventure/aiventure-github/cartheur/aiventure-rodney/build/6x09/RODNEY-3BOARD-SINGLE-SHEET-BOM-8085-REFERENCE.csv:1)
- [RODNEY-ON-HAND-STOCK-REFERENCE.md](/home/cartheur/ame/aiventure/aiventure-github/cartheur/aiventure-rodney/build/6x09/RODNEY-ON-HAND-STOCK-REFERENCE.md:1)
- [RODNEY-6809-BETA-SEED.asm](/home/cartheur/ame/aiventure/aiventure-github/cartheur/aiventure-rodney/build/6x09/RODNEY-6809-BETA-SEED.asm:1)
- [RODNEY-6809-SUPPORT-ROM.asm](/home/cartheur/ame/aiventure/aiventure-github/cartheur/aiventure-rodney/build/6x09/RODNEY-6809-SUPPORT-ROM.asm:1)

## Suggested Migration Order

1. Freeze the logical memory map and I/O contract.
2. Redesign `Board A` around `6809` bus timing.
3. Keep `Board B` and `Board C` interfaces as stable as possible.
4. Bring up ROM, reset, RAM execution, and `ACTL` blink first.
5. Port the smallest runtime:
   - support ROM
   - Beta seed
6. Only then port Beta-full and Gamma.

## Decision

Use the revision ladder as the organizing path:

- `Rev. 0`: `8085` on `Board A`
- `Rev. 1`: `MC6809P` plus `GA144` inclusion on `Board A`
- `Rev. 2`: `HD63C09RP` plus `GA144` inclusion on `Board A`
- `Rev. 3`: `MC6809P/HD63C09RP/SC67475P` plus `GA144` inclusion on `Board A`

This keeps the branch linear and avoids mixing early board revisions with later expansion terminology.

## Boundary Marker

Treat this `6x09` folder as the boundary between:

- the conventional Rodney CPU-board redesign path built around `8085`, `6809`, and `6309`
- a later, separate architectural phase that would introduce a `GA144`

In other words:

- everything in this folder stays on the side of socketed conventional CPUs and shared `Board B` / `Board C` infrastructure
- any `GA144` introduction should begin as a new branch of documentation rather than being folded back into this `6x09` track

More specifically, this boundary is defined at the crystal.

- the conventional CPU side of the design reaches up to the crystal-clocked boundary
- the `GA144` side begins at the resonant-frequency origin of that crystal
- from `Rev. 1` onward, the revision ladder includes both sides of that boundary on `Board A`

That means the split is not merely "old CPU here, new chip there." It is:

- below the crystal domain: conventional synchronous CPU design, glue logic, memory, and bench I/O
- at and beyond the crystal's resonant-frequency domain: the start of the `GA144` architectural phase

Historical note for this branch:

- immediately before drawing this boundary, the `6x09` path was heading toward a `74LS74`-based clock-divider / phase-generation approach
- that would have been the more conventional and less elegant solution compared with using `GA144` at the crystal boundary
- `AN002-171106-OSC.pdf` is the direct reference for the more elegant `GA144` oscillator and crystal-excitation path
- see [AN002-GA144-CRYSTAL-BOUNDARY.md](/home/cartheur/ame/aiventure/aiventure-github/cartheur/aiventure-rodney/build/6x09/AN002-GA144-CRYSTAL-BOUNDARY.md:1)

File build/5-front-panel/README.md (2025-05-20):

## Chapter 5: Front panel Program/Test assembly

While Rodney is essentially a self-programming machine, there is still a need for entering a small selection of programs from the outside world. An animal might be born knowing exactly nothing about how to cope with its environment, but even so, it is born with an underlying reflex mechanism that helps the learning process begin.

_Description_

The system contains a 12-bit addressing and 8-bit data format.

### The Task

Is to assemble the front panel assembly that looks like this:

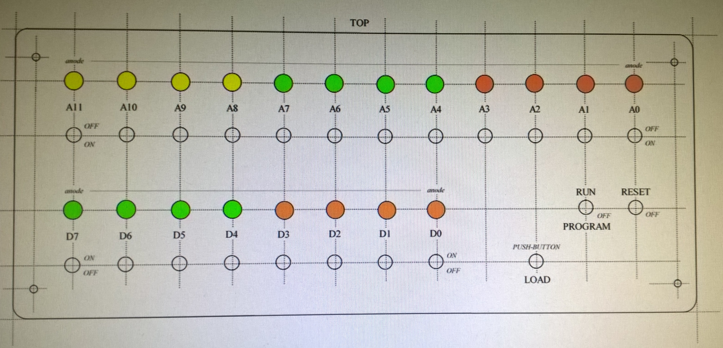
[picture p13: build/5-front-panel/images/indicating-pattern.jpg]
assembly


Where we have the orange indicators as the low 4-bits, green indicators as the mid 4-bits of the address-bus and high 4-bits for the data-bus, yellow indicators as the high 4-bits of the address-bus. The LEDs to be used are these:

| Color | Voltage Vf | Manufacturer |
|---|---|---|
| Pure Orange Diffused | 2.1 | Kingbright |
| Green Diffused | 2.1 | LiteOn |
| Yellow Diffused | 2.1 | Lumex |

Where the notion of _diffused_ gives a special property:

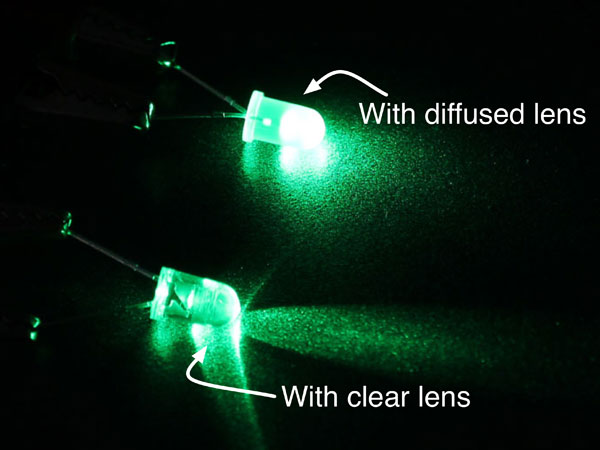
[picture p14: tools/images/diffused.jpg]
diffused


In order to accomplish this, a set of three cables extend from a set of pins to another board:

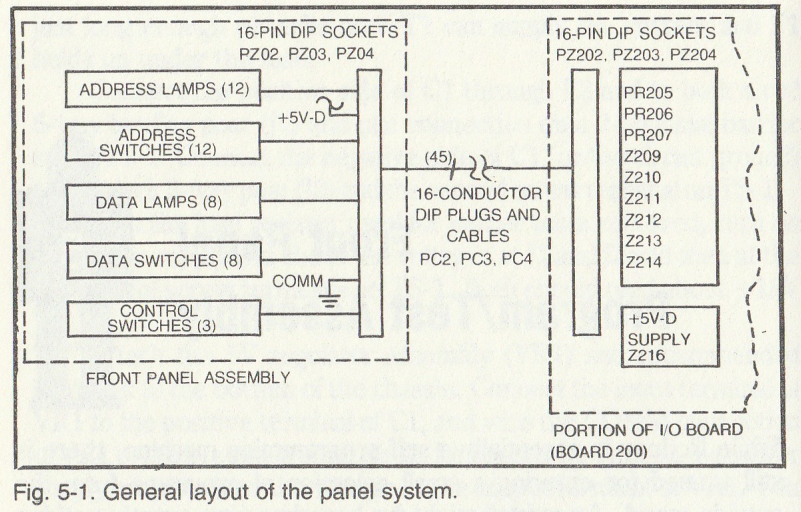
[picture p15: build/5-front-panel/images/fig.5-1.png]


Where the detail of the connections (addressing) is recommended as:

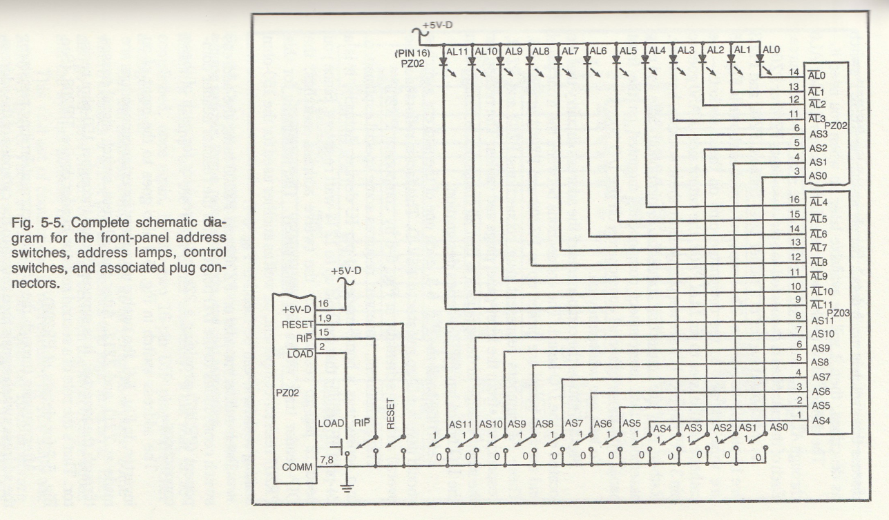
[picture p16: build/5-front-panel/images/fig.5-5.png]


And the detail of the connections (data) is recommended as:

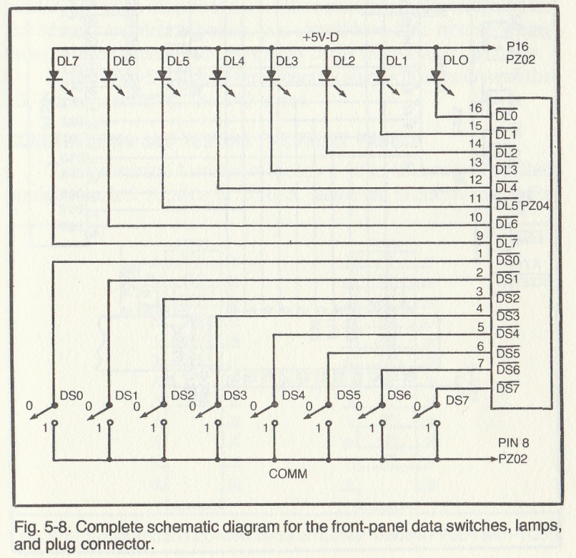
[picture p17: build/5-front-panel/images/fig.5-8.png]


Notice how:

* `+5v`, denoted as `PZ02` - `PIN 16`, is shared between the address and data circuits and,
* `COMM`, denoted as `PZ02` - `PIN 8`, is shared between all circuits in the panel.

Therefore, the corresponding wiring pattern of the _user interface_ is thusly:

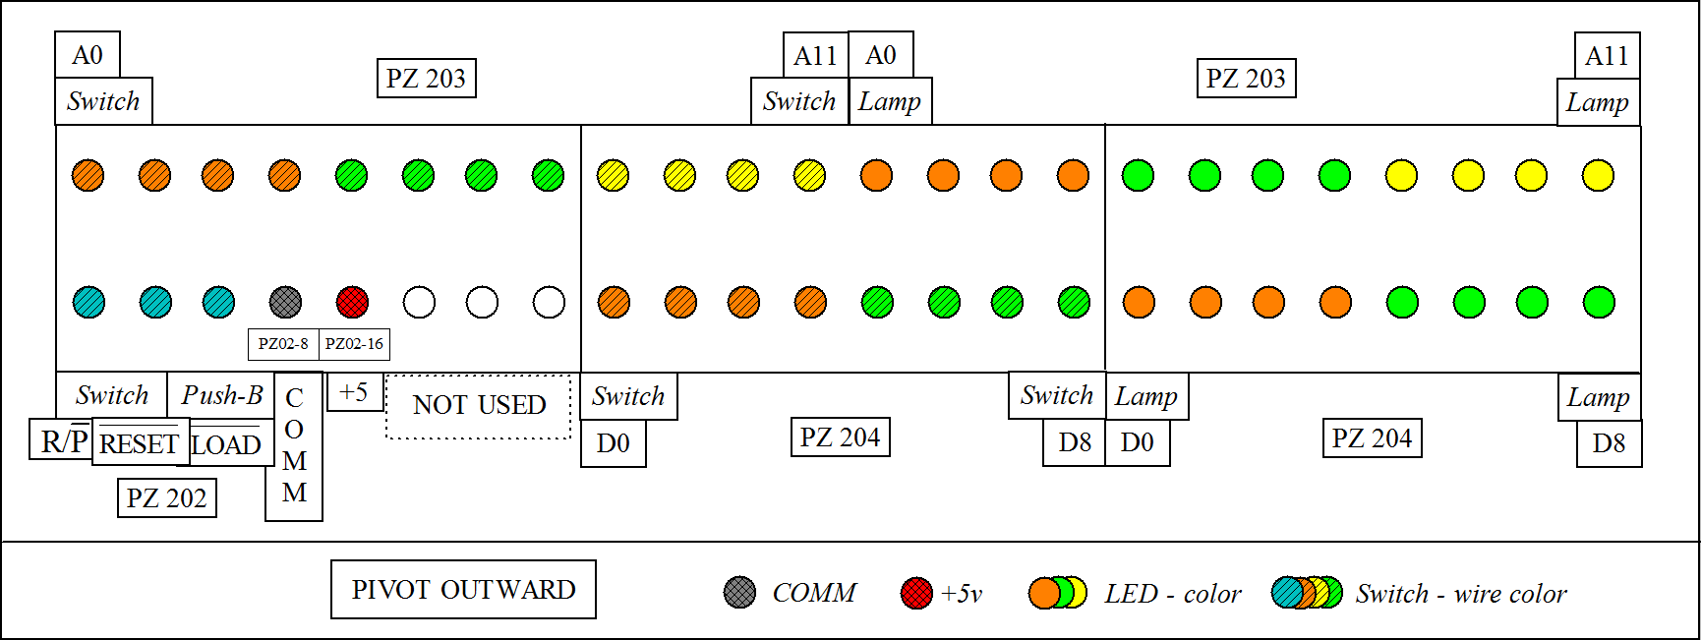
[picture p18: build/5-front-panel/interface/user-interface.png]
pattern


Using the colors from the lamps to show where the wires [connect](/tools/README.md).

_Connection from the panel_

The wires coming into the triad of 16-pin ribbon cable will first be wired to the appropriate connections:

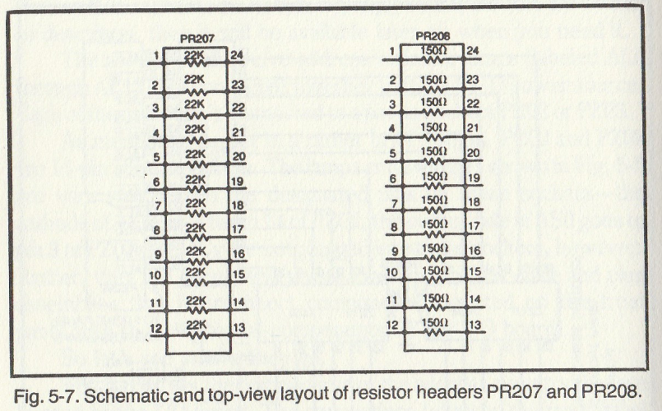
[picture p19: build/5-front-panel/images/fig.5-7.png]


For the address and for the data:

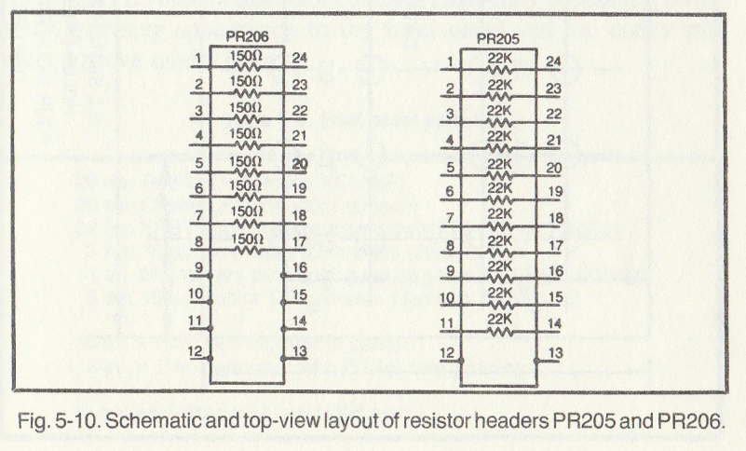
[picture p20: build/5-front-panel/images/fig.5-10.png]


Meaning there are these requring a 22k-Ohm resistor:

* `12 AS` (`PR207`) + `8 DS` + `2 SS` + `1 PB` (`PR205`) = 23 slots.

And these requiring a 150-Ohm resistor bank:

* `12 AL` (`PR208`) + `8 DL` (`PR206`) = 20 slots.

That leads into the bus system components:

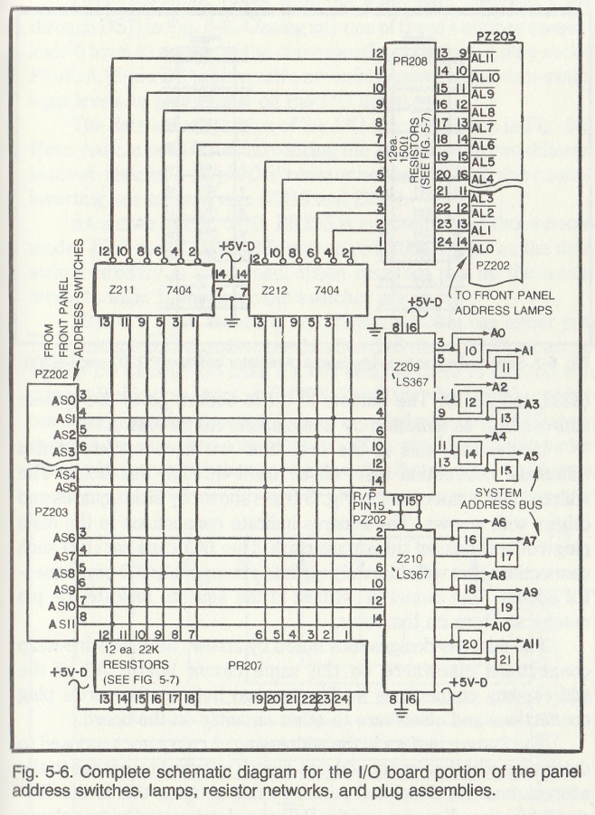
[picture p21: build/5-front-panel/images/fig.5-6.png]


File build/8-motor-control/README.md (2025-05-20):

## Chapter 8: Motor drive and power-distribution assemblies

You know for sure you’re building a robot the first time you hear those drive motors start to whine. That’s the sound you should be hearing by the time you complete the work in this chapter. Here, we are mainly interested in getting the motor drive circuitry installed and checked out. Also, you will check that the subchassis for the motor controls can house the power-distribution system, so you might as well install this section now. The work in this chapter calls for some more sheet-metal work. If you wish, however, you can substitute the custom chassis with a commercially available one that has about the same dimensions.

### The Task

Is to...

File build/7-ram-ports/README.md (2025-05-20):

## Chapter 7: Installing and testing the program RAM and primary ports

A microprocessor system without any input and output ports is like a car without wheels; it can look very impressive and exhibit a lot of potential, but nothing really significant happens. The Rodney robot system you have constructed to this point doesn’t really do much. Oh sure, you can make some lights on the front panel go on and off, and there are a lot of switches to play with. But the whole project, to this point, is mere foundation work. This chapter paves the way for getting some action from the machine in Chapter 8.

### The Task

Is to...

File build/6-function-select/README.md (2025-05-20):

## Chapter 6: Function and I/O Select circuitry

As described in the overall system plan in Chapter 2, the microprocessor chip must be able to interact with three basic subsections: a program RAM, an optional ROM, and a host of I/O ports. The purpose of the function select circuitry described in this chapter is to sort out the sources and destinations of the microprocessor information.

### The Task

Is to...

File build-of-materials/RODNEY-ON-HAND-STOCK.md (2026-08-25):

# Rodney On-Hand Stock

On-hand inventory tracker for the current Rodney bench build and nearby expansion experiments.

Use this page to track what is physically in hand without changing the purchase-oriented BoM files.

Related references:

- [RODNEY-3BOARD-SINGLE-SHEET-BOM.md](/home/cartheur/ame/aiventure/aiventure-github/cartheur/aiventure-rodney/build-of-materials/RODNEY-3BOARD-SINGLE-SHEET-BOM.md:1)
- [RODNEY-3BOARD-SINGLE-SHEET-BOM.csv](/home/cartheur/ame/aiventure/aiventure-github/cartheur/aiventure-rodney/build-of-materials/RODNEY-3BOARD-SINGLE-SHEET-BOM.csv:1)

Last updated: `2026-08-25`

## Current On-Hand Stock

| Category | Part | Selected / Typical Device | Required For Current Build | On Hand | Delta | Notes |
|---|---|---|---:|---:|---:|---|
| Memory board | main memory SRAM | `AS6C62256-55PIN` | 1 | 10 | +9 | enough for baseline build plus spares and memory experiments |
| Memory board | program RAM SRAM | `AS6C6264-55PCN` | 1 | 6 planned | 5 planned spare | purchase planned; enough for baseline build plus direct-map and swap experiments |
| Memory board | monitor EEPROM | `AT28C64B-15PU` | 1 | 10 planned | 9 planned spare | purchase planned; can support baseline build plus swap and experiment stock |
| Memory board | MMA latches / output latch family | `74LS273` | 3 | 10 planned | 7 planned spare | baseline build uses `2` on Board B and `1` on Board C |
| CPU and memory boards | bus transceiver / data isolation | `74LS245` | 2 | 10 planned | 8 planned spare | baseline build uses `1` on Board A and `1` on Board B |
| CPU and memory boards | region decode | `74LS138` | 2 | 10 planned | 8 planned spare | baseline build uses `1` on Board A and `1` on Board B |
| Memory board | subdecode | `74LS139` | 1 | 10 planned | 9 planned spare | baseline build uses `1` on Board B |
| CPU and memory boards | NAND glue logic | `74LS00` | 2 | 20+ in stock | 18+ spare | baseline build uses `1` on Board A and `1` on Board B |
| CPU board | inverter / clock-reset glue | `74LS04` | 1 | 20+ in stock | 19+ spare | baseline build uses `1` on Board A |
| Sockets | `DIP-28 ZIF` | Board B `U1`, `U7`, `U8` | 3 | 4 purchased | +1 | current plan uses `3` and keeps `1` spare |
| Sockets | `DIP-28` wire-wrap socket | memory devices | 3 | in stock |  | baseline requirement only; expansion spares can be tracked here too |
| Sockets | `DIP-40` wire-wrap socket | `8085A` | 1 | in stock |  | CPU is fixed to a standard wire-wrap socket plan |
| CPU board | CPU | `8085A` | 1 | 4 | +3 | enough for baseline build plus swap and fault-isolation margin |
| CPU board | crystal | `5 MHz` | 1 | 10 in stock | +9 | inventory list now shows strong crystal margin for multiple Rodney units and experiments |
| Memory board | decode glue | `74LS32N` | 1 | 10 purchased | +9 | planned support logic for the improved build; datasheet already in repo |
| I/O board | input buffer | `74LS244` | 1 | 20 | +19 | baseline Board C input-buffer part; strong spare margin already on hand |
| I/O board | pseudo-random source | `74LS164` | 1 | 10 planned | 9 planned spare | baseline shift-register part for the Board C pseudo-random source |
| I/O board | XOR feedback | `74LS86` | 1 | 10 planned | 9 planned spare | baseline part for the pseudo-random source on Board C |
| I/O board | DIP switch | `CTS 195-8MST` | 2 | 10 planned | 8 planned spare | `SW1`, `SW2`; strong margin for alternates and rework |
| Passive | `10k` resistor | `MF1/4DCT52R1002F` | 10 baseline stock target | 100 in stock | +90 | covers reset, pull-ups, and general glue stock for multiple Rodney units |
| Analog preview | quad op-amp | `LM324AN` | 0 baseline | 20 in stock | preview stock | supports light-sensing gain, buffering, and simple active-filter experiments |
| Analog preview | microphone amp breakout | `Adafruit 1713 / Mouser 485-1713` | 0 baseline | 6 in stock | preview stock | MAX9814 electret mic amp breakout for sound-trigger experiments |
| Analog preview | light sensor | `CdS photoresistor` | 0 baseline | 30 in stock | preview stock | inventory list now shows ample stock for light-threshold and beam-break style experiments |
| Operator control | 4-way joystick | `ETI Systems J1-00105` | 0 baseline | 1 in stock | optional stock | rugged panel-mount digital joystick; good candidate for `Board C` manual direction, mode, or training input experiments |
| Tools | soldering iron | `Weller` | 1 | in stock |  | primary soldering iron for the Rodney build |

## Expansion-Oriented Stock

These are not required to assemble the baseline machine, but are worth tracking if they are already on hand.

| Category | Part | Suggested Stock Target | On Hand | Notes |
|---|---|---:|---:|---|
| Memory expansion | extra `6264` SRAM | 1 to 2 spare |  | supports alternate `U7` / `U8` program-memory experiments |
| Memory expansion | extra `DIP-28 ZIF` | 1 spare |  | current purchasing direction suggests total buy of `4` |
| Memory expansion | extra `DIP-28` wire-wrap socket | 1 to 2 spare |  | useful for rework or alternate population |
| Memory expansion | `AT28C256-15PU` EEPROM | 4 planned | 4 planned | optional larger EEPROM stock if we want more room later |
| Memory expansion | `256K`-class memory devices | optional future reserve |  | for post-`GAMMA-1` / `DELTA-1` style experiments |
| Decode experiments | jumper / header strap hardware | 1 small pack |  | useful for alternate chip-select or bank-select work |
| Decision experiments | `74LS85` magnitude comparator | 1 to 2 | 10 planned | purchase planned; strong margin if `4-bit wonder` testing suggests we want hardware compare, threshold, or ranking support |
| Analog preview | `LM324AN` quad op-amp | 1 to 2 | 20 in stock | enough for several light or microphone front-end experiments |
| Analog preview | `Adafruit 1713 / 485-1713` microphone amp breakout | 1 to 2 | 6 in stock | enough for multiple sound-sensing preview builds |
| Analog preview | `CdS` photoresistor | 1 to 2 | 30 in stock | enough for multiple light-sensing preview builds and spares |
| Operator control | `ETI Systems J1-00105` joystick | 1 optional | 1 in stock | useful if we want a sealed front-panel `up/down/left/right` manual input without committing it to the baseline BOM |

## Readiness Snapshot

Current status using the latest `inventory/list.csv` plus the active `basket/basket-items.csv`:

- one complete Rodney unit: fit looks strong
- two complete Rodney units: electronics core looks strong, but the full build is not yet closed out

Main strengths for the two-unit target:

- CPUs, core TTL, memory devices, WW sockets, ZIF sockets, crystals, LEDs, and common resistor or capacitor stock are all in good shape
- wire-wrap wire and basic red or black power wire are now on hand
- analog preview branch for light and sound sensing is well covered

Main remaining blockers for the two-unit target:

- `Vector 8801-6` boards: `4` on hand vs `6` needed
- `R681-2` edge connectors: `2` on hand vs `4` needed

Still worth confirming before calling the two-unit build fully ready:

- exact header-strip plan for service and interconnect
- test-post and harness-anchor allocation per unit
- pushbutton mounting details
- standoffs and final mechanical stack hardware
- final cable-length comfort margin

## Theoretical `6264` Ceiling

If we ignore physical board area and only look at the address/decode model:

- one `6264` provides `8 KB`
- the `8085` exposes `64 KB` of address space total
- pure mathematical direct-map ceiling: `8 x 6264`

In the current Rodney map, one `8 KB` region is used for the `8000h-9FFFh` I/O page, so:

- practical direct-mapped ceiling with I/O preserved: `7 x 6264`
- practical direct-mapped ceiling with both I/O and the current EEPROM / monitor window preserved: `6 x 6264`

These are theory limits for the map only, not recommendations for the first-pass build.

## Banking Theory

Banking means the CPU keeps seeing the same address window, but extra logic decides which physical memory chip is currently active behind that window.

Simple theory:

- without banking, each chip gets its own fixed address range
- with banking, multiple chips share one CPU-visible range
- a bank-select bit or group of bits chooses which chip or chip group is enabled

Example for Rodney:

- keep program space at `0000h-1FFFh`
- connect two or more `6264` devices so only one of them sees `/CS` at a time
- drive that selection from a jumper, latch, flip-flop, or memory-mapped control register

Why banking matters:

- it lets us reuse scarce address space
- it allows multiple program images or experiment sets behind one window
- it increases software and decode complexity compared with direct mapping

Main software rule:

- never switch away from the bank currently executing code unless the switching routine lives in an always-visible region such as EEPROM / monitor ROM or some other non-banked space

Theory scaling:

- direct-mapped memory is capped by the number of distinct address windows
- banked memory scales by `windows x banks-per-window`
- so if `6` or `7` windows are available and each window has `N` banks, the total possible `6264` count becomes roughly `6 x N` or `7 x N`

## Comparator Note

`74LS85` is not part of the current baseline Rodney build, but it is a good candidate for later decision-support experiments.

Possible uses:

- compare two small scores or confidence values
- detect whether one thresholded value is greater than, less than, or equal to another
- support hardware-assisted choice, ranking, or branch conditions

Practical stance:

- keep it out of the first-pass build unless testing shows a clear benefit
- be ready to bring it into the build if the `4-bit wonder` experiments demonstrate a useful decision or predictive primitive

## Tracking Notes

- `Delta` is `On Hand - Required For Current Build`.
- Leave `On Hand` blank until a real count is confirmed.
- If a part has multiple acceptable variants, record the exact stocked part in the `Selected / Typical Device` column or notes.
- Keep this page focused on stock state; use the single-sheet BoM for purchase requirements and planning assumptions.

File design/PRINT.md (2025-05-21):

# 3D Printed Robot Design in FreeCAD

This guide provides a step-by-step process to design a 3D printable robot in FreeCAD, based on a circular base of 18 inches and a card rack for Vector 8801-6 S-100 bus boards. The components will be designed as separate parts, which can be exported as STL files for 3D printing.

* If safety has primacy, have a look at thickness increase and ribbing discussed [here](/design/SAFETY.md).
* Look at the analysis of two thicknesses of the disk and skirt [here](/design/FILAMENT.md).
* For a total caluclation of the amount of PLA required for the infrastructure, see [here](/design/TOTAL.md).

## Project Overview: Robot Components

The robot consists of the following parts to be 3D printed:

1. **Bottom Plate + Skirt**:
   - Bottom Plate: 18-inch (457.2 mm) diameter, 0.5-inch (12.7 mm) thick.
   - Skirt: 18-inch (457.2 mm) outer diameter, 2-inch (50.8 mm) height, 0.25-inch (6.35 mm) thick.
2. **Card Rack Assembly**:
   - Dimensions: 11 inches × 11 inches × 13 inches (279.4 mm × 279.4 mm × 330.2 mm).
   - Includes vertical supports, top/bottom frames, and two shelves.
3. **Rack Mounts**: 4 L-shaped brackets, each 2 inches × 2 inches (50.8 mm × 50.8 mm), 0.5-inch (12.7 mm) thick, 1-inch (25.4 mm) height.
4. **Wheels**: 4 wheels, each 3.5 inches (88.9 mm) in diameter, 1-inch (25.4 mm) wide.

## Designing in FreeCAD

FreeCAD uses a parametric modeling approach, where you create sketches and extrude or cut them to form 3D objects. We'll use the **Part Design workbench** for most components. All measurements are in millimeters, as FreeCAD defaults to metric units.

### Step-by-Step Design in FreeCAD

#### 1. Bottom Plate + Skirt

**Bottom Plate**:
- **Shape**: Circular disc.
- **Dimensions**:
  - Diameter: 457.2 mm (18 inches).
  - Thickness: 12.7 mm (0.5 inches).
- **Steps**:
  1. Open FreeCAD and switch to the **Part Design workbench**.
  2. Create a new document (`File > New`).
  3. Click **Create a new sketch** and select the XY plane.
  4. In the sketcher:
     - Draw a circle centered at the origin (0,0) with a diameter of 457.2 mm (radius = 228.6 mm).
     - Click **Close** to finish the sketch.
  5. With the sketch selected, click **Pad** (extrude) in the Part Design toolbar:
     - Set the length to 12.7 mm.
     - Click **OK** to create the disc.
- **Features** (Mounting Holes):
  - **Wheel Holes** (4 holes, evenly spaced, 90 degrees apart, near the edge):
    1. Create a new sketch on the top face of the disc.
    2. Draw 4 circles (6.35 mm diameter for axles) at 90-degree intervals, 20 mm from the edge:
       - Use a construction circle (radius = 208.6 mm, i.e., 228.6 mm - 20 mm) to position the holes.
       - Place circles at (208.6, 0), (0, 208.6), (-208.6, 0), (0, -208.6).
       - Set each circle’s diameter to 6.35 mm.
    3. Close the sketch and use **Pocket** to cut the holes through the disc.
  - **Rack Mount Holes** (4 holes at the corners of an 11-inch × 11-inch square, centered):
    1. Create a new sketch on the top face.
    2. Draw 4 circles (6.35 mm diameter) at (±139.7 mm, ±139.7 mm), corresponding to the rack’s 279.4 mm × 279.4 mm footprint.
    3. Use **Pocket** to cut the holes through.

**Skirt**:
- **Shape**: Cylindrical ring.
- **Dimensions**:
  - Outer Diameter: 457.2 mm.
  - Inner Diameter: 444.5 mm (457.2 mm - 2 × 6.35 mm).
  - Height: 50.8 mm.
- **Steps**:
  1. Create a new sketch on the top face of the bottom plate.
  2. Draw two concentric circles: one at 457.2 mm diameter (radius = 228.6 mm), another at 444.5 mm diameter (radius = 222.25 mm).
  3. Close the sketch.
  4. Use **Pad** to extrude the ring by 50.8 mm.
- **Combine**: The skirt and bottom plate can be modeled as one body in FreeCAD, or as separate bodies combined later using **Part > Boolean > Union**.

**Splitting for Printing**:
- An 18-inch (457.2 mm) diameter part is too large for most 3D printers (e.g., a 220 mm × 220 mm bed). Split the model into 4 quadrants:
  1. Create a new sketch on the XY plane.
  2. Draw two lines (one along the X-axis, one along the Y-axis) to divide the circle into 4 quadrants.
  3. Use **Part > Split > Slice** to split the model into 4 parts.
  4. Add connectors (e.g., small dovetail joints or screw holes) along the edges:
     - For dovetails, sketch trapezoids (e.g., 10 mm wide, 5 mm deep) on the cut edges and extrude/cut to form interlocking joints.
     - For screw holes, add 4 mm diameter holes on each quadrant’s edge for M4 bolts.

#### 2. Card Rack Assembly

**Frame**:
- **Dimensions**:
  - Overall: 279.4 mm × 279.4 mm × 330.2 mm.
- **Components**:
  - **Vertical Supports**: 4 beams, 12.7 mm × 12.7 mm, 330.2 mm tall.
  - **Top/Bottom Frames**: 279.4 mm × 279.4 mm, 12.7 mm thick.
  - **Shelves**: 2 shelves, 279.4 mm × 279.4 mm, 6.35 mm thick.
- **Steps**:
  1. **Vertical Supports**:
     - Create a new body (`Part Design > Create body`).
     - Create a sketch on the XY plane.
     - Draw a 12.7 mm × 12.7 mm square, centered at (139.7 mm, 139.7 mm) for one corner.
     - Pad the square by 330.2 mm.
     - Copy this body 3 times (use **Part Design > Transform > Linear Pattern**):
       - Place at (±139.7 mm, ±139.7 mm) to form the 4 corners.
  2. **Bottom Frame**:
     - Create a new body.
     - Sketch on the XY plane a 279.4 mm × 279.4 mm square with a 12.7 mm thickness (inner square at 253.9 mm × 253.9 mm).
     - Pad by 12.7 mm.
     - Add 4 mounting holes (6.35 mm diameter) at (±139.7 mm, ±139.7 mm) to match the bottom plate.
  3. **Top Frame**:
     - Repeat the bottom frame process, but move the body to Z = 317.5 mm (330.2 mm - 12.7 mm) using **Part Design > Transform > Translate**.
  4. **Shelves**:
     - Create a new body.
     - Sketch on the XY plane a 279.4 mm × 279.4 mm square.
     - Pad by 6.35 mm.
     - Move to Z = 203.2 mm (above the battery section).
     - Copy and move the second shelf to Z = 260.35 mm (203.2 mm + 50.8 mm + 6.35 mm).
- **Features**:
  - Add slots for 100-pin S-100 connectors on the back of each shelf:
    - Create a sketch on the back edge of each shelf.
    - Draw a 266.7 mm × 5 mm rectangle, centered.
    - Use **Pocket** to cut the slot through.
- **Combine**: Use **Part > Boolean > Union** to combine all parts into one body, or keep them separate for modular assembly.

**Printing Note**: Each component (supports, frames, shelves) should fit on a standard print bed (e.g., 220 mm × 220 mm). Print separately and assemble with screws or glue.

#### 3. Rack Mounts

- **Shape**: 4 L-shaped brackets.
- **Dimensions**:
  - Each leg: 50.8 mm × 50.8 mm.
  - Thickness: 12.7 mm.
  - Height: 25.4 mm.
- **Steps**:
  1. Create a new body.
  2. Sketch on the XY plane an L-shape: two 50.8 mm legs, 12.7 mm thick.
  3. Pad by 25.4 mm.
  4. Add two 6.35 mm diameter holes (one on each leg, centered, 25.4 mm from the corner) for bolts:
     - Create a sketch on the top face, draw the circles, and use **Pocket** to cut through.
  5. Copy to create 4 brackets (use **Linear Pattern**).
- **Printing Note**: These small parts can be printed with 50-75% infill for strength.

#### 4. Wheels

- **Dimensions**:
  - Diameter: 88.9 mm.
  - Width: 25.4 mm.
- **Steps**:
  1. Create a new body.
  2. Sketch on the XY plane a circle with a diameter of 88.9 mm.
  3. Pad by 25.4 mm to create a cylinder.
  4. Add an axle hole:
     - Sketch a 6.35 mm diameter circle at the center on one face.
     - Use **Pocket** to cut through.
  5. (Optional) Add a tread pattern:
     - Sketch small rectangles (e.g., 5 mm × 3 mm) around the outer edge, evenly spaced.
     - Pad or pocket to create a grip pattern.
  6. Copy to create 4 wheels.
- **Printing Note**: Print with 50% infill for durability.

## Exporting STL Files in FreeCAD

Once each component is modeled:

1. Select the body (or combined body) in the model tree.
2. Go to `File > Export`.
3. Choose **STL** as the file format.
4. Save the file.
5. Repeat for each component (e.g., bottom plate quadrant 1, quadrant 2, etc., rack supports, shelves, mounts, wheels).

## Printing Recommendations

- **Material**: PLA or PETG for most parts; ABS or nylon for wheels if durability is needed.
- **Infill**: 20-30% for the base and rack, 50-75% for mounts and wheels.
- **Supports**: Enable supports for the skirt and any overhangs (e.g., shelves, tread patterns).
- **Assembly**: Use M4 bolts for the mounting holes, or glue parts together if preferred.

## Summary

Using FreeCAD, you can design the robot components as described above. The process involves creating sketches, extruding them into 3D shapes, adding features like holes and slots, and splitting large parts (like the base) for printing. Once designed, export each part as an STL file for 3D printing. For additional help with FreeCAD tools or settings, refer to the FreeCAD documentation or community forums.

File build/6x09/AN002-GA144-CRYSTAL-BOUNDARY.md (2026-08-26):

# AN002: `GA144` Crystal-Boundary Introduction

Application note `AN002` records the architectural boundary between:

- the conventional Rodney CPU path built around `8085`, `6809`, and `6309`
- the next phase beginning with the `GA144`

## Boundary Definition

The boundary is defined at the crystal.

- the conventional CPU branch ends at the crystal-clocked machine boundary
- the `GA144` branch begins at the resonant-frequency origin of that crystal

This is not merely a processor substitution.

It is a change in architectural regime:

- below the crystal domain: conventional synchronous CPU, glue logic, memory, and bench I/O
- at and beyond the crystal's resonant-frequency domain: `GA144`

Primary reference:

- [AN002-171106-OSC.pdf](/home/cartheur/ame/aiventure/aiventure-github/cartheur/aiventure-rodney/build/6x09/AN002-171106-OSC.pdf)

The relevant point from that note is that `GA144` can excite and use external resonant devices under program control, including high-frequency and high-`Q` crystal behavior, using minimal external circuitry.

## Why This Note Exists

Immediately before this boundary was made explicit, the `6x09` branch was moving toward a conventional `74LS74` divider / phase-generation approach for `Board A`.

That path remains a valid conventional engineering option, but it is intentionally de-emphasized here because it does not express the cleaner handoff you wanted:

- crystal as boundary
- `GA144` as the next regime beginning from that resonance domain

More concretely:

- the fallback idea was to bang on the `6x09` crystal with a `74LS74`-based conventional clocking scheme until resonance behavior was found and stabilized
- `AN002` shows a more elegant `GA144` approach in which the resonant device can be excited and observed under program control rather than forced through a conventional flip-flop-centered solution

## Scope

This note is interpretive and architectural.

It does not yet define:

- a complete `GA144` schematic
- a shared timing-distribution network
- a mixed `6x09` / `GA144` bus protocol
- a final resonant-coupling implementation

Those belong to the next documentation branch after `build/6x09`.

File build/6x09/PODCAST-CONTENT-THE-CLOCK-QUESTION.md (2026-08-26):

# Podcast Content: The Clock Question

Date: `2026-08-26`

## Why The Clock Question Matters

At first glance, the redesign from `i8085` to `MC6809P` or `HD63C09RP` looks like a CPU substitution problem.

But the deeper issue turned out to be the clock.

That is where the project stopped being only about:

- instruction sets
- bus timing
- memory maps
- glue logic

and started becoming about the architectural meaning of the crystal itself.

## The Immediate Technical Problem

The `MC6809P` does not have a self-contained internal clock in the sense that many later microcontrollers do.

It does include on-chip oscillator circuitry, but it still depends on an external resonant element or external timing arrangement.

That means the crystal or oscillator arrangement is not a background detail.

It is part of the machine's real design problem.

For `Board A, Rev. 1`, that question was unavoidable:

- how do we establish timing for the `MC6809P`
- how do we find or sustain usable crystal behavior
- how do we do that without building a clumsy pile of conventional support logic

## The Near-Term Conventional Answer

The project was drifting toward a familiar hardware answer:

- use a `74LS74` flip-flop in a conventional clock-divider or phase-generation role
- bang on the crystal until resonance was found and stabilized
- then let the CPU side live off that conventional clock path

This is not nonsense.

It is a normal engineering instinct.

If you have a conventional CPU with on-chip oscillator support but a real external crystal-domain design problem, one ordinary response is to build a conventional timing circuit around it.

## Why That Felt Unsatisfying

The problem with the `74LS74` approach is not that it would never work.

The problem is that it keeps the crystal conceptually small.

In that framing, the crystal is still just:

- a part to be kicked into oscillation
- a support component for the CPU
- a technical nuisance to be stabilized and then ignored

That keeps the whole design inside a conventional glue-logic mindset.

## What Changed The Picture

The addition of `GA144`, together with the guidance in [AN002-171106-OSC.pdf](/home/cartheur/ame/aiventure/aiventure-github/cartheur/aiventure-rodney/build/6x09/AN002-171106-OSC.pdf), changed the meaning of the problem.

According to `AN002`, the `GA144` can work with a resonant device using minimal external circuitry by:

- connecting the resonant device to a single GPIO pin and ground
- exciting it under program control
- observing it via asynchronous pin wake-up
- sustaining oscillation by synchronously pumping energy back into it

That means the crystal no longer has to be treated only as a passive support part for the CPU.

## The Borderline Idea

This is where the real architectural shift appears.

The crystal becomes the **borderline** between two regimes:

- the conventional CPU side
- the resonant `GA144` side

On one side:

- `Rev. 0`: `i8085`
- `Rev. 1`: `MC6809P`
- `Rev. 2`: `HD63C09RP`
- `Rev. 3`: `MC6809P/HD63C09RP/SC67475P`

On the other side:

- `GA144`

From `Rev. 1` onward, `Board A` includes both sides of that borderline.

## What This Means For The `MC6809P`

This does **not** mean the `MC6809P` lacks oscillator circuitry.

It has on-chip oscillator support, but the crystal domain is still a real architectural and board-level question.

What changes is the role of the `MC6809P` in relation to the crystal.

In a normal design, the `MC6809P` is effectively the owner of the crystal domain.

In this design, the `MC6809P` becomes more like a neighbor of the crystal domain.

The CPU still consumes timing derived from the crystal, but it is no longer the best or most interesting agent for directly exciting and managing the resonant device.

That work shifts toward the `GA144`.

## Why This Is A Deeper Shift

This matters because it moves novelty downward.

Before, Rodney's adaptive story lived mostly in:

- learned memory
- writable behavior
- environment-indexed response

Now the design suggests that part of the machine's meaningful activity also lives at the timing substrate.

The machine is not only:

- sensing
- remembering
- choosing

It is also, at the crystal borderline:

- exciting
- observing
- sustaining
- stabilizing

That makes the clock part of the machine's architecture rather than mere support plumbing.

## Why This Enhances Rodney

Rodney's self-programming motif was already unusual because future behavior could be shaped by learned memory.

The `GA144` crystal-borderline idea deepens that by introducing a second kind of meaningful interaction:

- symbolic adaptation in learned memory
- resonant interaction at the physical timing boundary

That makes the machine feel more embodied.

It is not only reacting to an environment represented in bits.

It is also participating in a physical oscillatory condition that must be initiated, detected, and sustained.

## The Elegant Versus The Ordinary Answer

The ordinary answer was:

- use `74LS74`
- force the clock problem into a conventional TTL pattern

The more elegant answer is:

- let `GA144`, as described in `AN002`, engage the resonant device directly
- treat the crystal as a borderline, not just a utility component

This is why the clock question became more than a schematic nuisance.

It became the place where the design revealed what kind of machine Rodney was becoming.

## One-Sentence Summary

The clock question mattered because the `MC6809P` still made the crystal domain a real design problem, and that forced a choice between a conventional `74LS74`-style clock workaround and a more original `GA144` approach that turned the crystal into a meaningful architectural borderline.

## Related References

- [README.md](/home/cartheur/ame/aiventure/aiventure-github/cartheur/aiventure-rodney/build/6x09/README.md:1)
- [AN002-GA144-CRYSTAL-BOUNDARY.md](/home/cartheur/ame/aiventure/aiventure-github/cartheur/aiventure-rodney/build/6x09/AN002-GA144-CRYSTAL-BOUNDARY.md:1)
- [AN002-171106-OSC.pdf](/home/cartheur/ame/aiventure/aiventure-github/cartheur/aiventure-rodney/build/6x09/AN002-171106-OSC.pdf)
- [PODCAST-CONTENT-NOVELTY.md](/home/cartheur/ame/aiventure/aiventure-github/cartheur/aiventure-rodney/build/6x09/PODCAST-CONTENT-NOVELTY.md:1)
- [PODCAST-CONTENT-SELF-PROGRAMMING-ENVIRONMENT.md](/home/cartheur/ame/aiventure/aiventure-github/cartheur/aiventure-rodney/build/6x09/PODCAST-CONTENT-SELF-PROGRAMMING-ENVIRONMENT.md:1)

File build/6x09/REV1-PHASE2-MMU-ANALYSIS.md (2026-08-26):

# Rodney Revision Ladder With `SC67475P` / `MC6829P`

Date: `2026-08-26`

This note reformulates the CPU-board analysis in light of the `SC67475P` inventory entry, noted in [inventory/list.csv](/home/cartheur/ame/aiventure/aiventure-github/cartheur/aiventure-rodney/inventory/list.csv:9) as a Motorola memory management unit in the `MC6829P` family.

For the crystal-boundary side of the same revision ladder, also see:

- [AN002-171106-OSC.pdf](/home/cartheur/ame/aiventure/aiventure-github/cartheur/aiventure-rodney/build/6x09/AN002-171106-OSC.pdf)

## Summary

The earlier `6x09` analysis was directionally right, but it blurred revision steps and later expansion language.

The cleaner reading is a linear revision ladder:

- `Rev. 0`: `8085` on `Board A`
- `Rev. 1`: `MC6809P` plus `GA144` inclusion on `Board A`
- `Rev. 2`: `HD63C09RP` plus `GA144` inclusion on `Board A`
- `Rev. 3`: `MC6809P/HD63C09RP/SC67475P` plus `GA144` inclusion on `Board A`

With the `SC67475P` addition, the important change is not a new "phase." It is that the later revisions can be made `MMU-aware`.

## Inventory Fact

The repo inventory currently lists:

- `SC67475P` x `6`

at [inventory/list.csv](/home/cartheur/ame/aiventure/aiventure-github/cartheur/aiventure-rodney/inventory/list.csv:9).

That means the revision ladder is not limited to a plain CPU swap. It already has the inventory basis for a memory-management branch once the linear CPU revisions are stable.

## Revision Ladder

### `Rev. 0`

- baseline `8085` `Board A`
- historical reference point
- current conventional starting machine
- no `GA144` inclusion assumed

### `Rev. 1`

- `MC6809P` on `Board A`
- `GA144` included on `Board A`
- first non-Intel CPU-board revision
- keep the machine as simple as possible:
  - linear `64 KB` map
  - memory-mapped I/O
  - ROM valid at top of memory for vector fetch
  - `MMA_L`, `MMA_H`, and `MMD` preserved
  - no MMU dependency in the active path
  - use `GA144` for the crystal-boundary inclusion rather than centering the board around a `74LS74` resonance workaround

### `Rev. 2`

- `HD63C09RP` on `Board A`
- `GA144` included on `Board A`
- begin by treating it as a conservative drop-in replacement for the `MC6809P`
- only after stability should clock or instruction-set advantages be explored

### `Rev. 3`

- `MC6809P/HD63C09RP/SC67475P` `Board A`
- `GA144` included on `Board A`
- intended as the converged conventional CPU board plus explicit MMU introduction
- should preserve the same `Board B` and `Board C` contract
- this is the natural place to move from MMU-awareness to MMU population

## MMU Interpretation

The `SC67475P` does not need to redefine the ladder.

It fits it like this:

- `Rev. 0`: no MMU assumption
- `Rev. 1`: no MMU dependency
- `Rev. 2`: no MMU dependency
- `Rev. 3`: explicit `SC67475P` introduction

Across the same ladder:

- `Rev. 0`: no `GA144` inclusion assumed
- `Rev. 1`: `GA144` included
- `Rev. 2`: `GA144` included
- `Rev. 3`: `GA144` included

## Why The MMU Stays Out Of `Rev. 1`

- it adds another failure surface during reset and vector fetch
- it complicates decode before the base machine has proven itself
- it makes ROM / RAM / learned-memory faults harder to isolate
- it delays the core question of whether the `MC6809P` Rodney model runs at all

This keeps `Rev. 1` aligned with [BRING-UP-PLAN.md](/home/cartheur/ame/aiventure/aiventure-github/cartheur/aiventure-rodney/build/6x09/BRING-UP-PLAN.md:1).

## What The MMU Changes Once Revisions Mature

The MMU creates a credible path to:

- banking program RAM
- stabilizing a fixed visible ROM or monitor region while remapping working memory
- creating alternate learned-state or experiment spaces
- separating operator-visible map simplicity from deeper internal memory experiments

## Why This Matters For Rodney

Rodney already wants a distinction between:

- support code
- runtime code
- learned state

The MMU can make that distinction stronger without forcing everything into fixed decode forever.

## Best Early MMU Uses

Recommended uses once the linear CPU revisions are stable:

1. banked program-RAM experiments behind a stable CPU-visible window
2. alternate learned-memory spaces for Beta/Gamma experiments
3. controlled remap schemes for comparing seeded and evolved behavior tables

## Uses To Avoid At First

- putting the MMU directly in the critical reset-vector path
- making ROM visibility depend on a complex runtime state
- solving basic bring-up problems with address translation instead of simpler decode

## Architectural Reframe

Before the MMU addition, the redesign could be summarized as:

- a linear CPU-board progression from `8085` to `MC6809P` to `HD63C09RP`

After this addition, the better summary is:

- a linear CPU-board progression
- with `Rev. 3` as the point where `SC67475P` becomes part of the board definition
- with `GA144` included from `Rev. 1` onward at the crystal boundary

That is a materially stronger position.

## BOM Implication

The current `6x09` BOM remains a valid `Rev. 1` BOM.

It is not yet a complete `Rev. 3` BOM, because it does not currently account for:

- `SC67475P` population
- MMU support wiring
- any additional latch, strap, or decode support needed for the chosen mapping scheme

So the BOM status is now:

- `Rev. 1` BOM: valid
- `Rev. 2` can remain close to `Rev. 1`
- `Rev. 3` BOM with `SC67475P`: not yet expressed

## Design Implication

The design status is now:

- `Rev. 0`: `8085`
- `Rev. 1`: `MC6809P` plus `GA144`
- `Rev. 2`: `HD63C09RP` plus `GA144`
- `Rev. 3`: `MC6809P/HD63C09RP/SC67475P` plus `GA144`

That means future `Board A` or `Board B` planning should treat `Rev. 3` as the explicit `SC67475P` revision, not merely a vague MMU-aware placeholder.

## Recommendation

Proceed in this order:

1. keep `Rev. 0` as the `8085` reference
2. complete `Rev. 1` as the clean `MC6809P` port without MMU dependency
3. validate `Rev. 2` as the `HD63C09RP` drop-in path
4. use `Rev. 3` as the place to define explicit `MC6809P/HD63C09RP/SC67475P` convergence
5. introduce `SC67475P` only after ROM fetch, RAM handoff, and Beta seed behavior are stable in the earlier revisions

## Practical Conclusion

The earlier analysis was incomplete because it mixed a linear hardware revision ladder with later expansion language.

With `SC67475P` x `6` in inventory, the better reading is:

- `Rev. 0`: `8085`
- `Rev. 1`: `MC6809P` plus `GA144`
- `Rev. 2`: `HD63C09RP` plus `GA144`
- `Rev. 3`: `MC6809P/HD63C09RP/SC67475P` plus `GA144`

And that keeps the MMU explicitly attached to the later linear revision without forcing that complexity into the earlier ones.

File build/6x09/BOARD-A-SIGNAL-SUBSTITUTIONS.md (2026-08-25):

# `8085` To `6x09` Board A Signal Substitutions

This note focuses on the biggest redesign area: `Board A`.

The current Rodney wire-wrap plan assumes an `8085A` with:

- multiplexed `AD0-AD7`
- `ALE`
- `/RD`
- `/WR`
- `IO/M`
- `READY`
- Intel-flavored reset and interrupt handling

A `6809` or `6309` changes that shape materially.

## Core Architectural Difference

The `8085` exports a multiplexed low address/data bus, so the current design needs:

- a `74LS373` address latch
- `ALE` routing
- extra thought around bus phase timing

The `6809` exports:

- separate address bus
- separate data bus
- different control and bus-state signals

That means the current low-address latch can likely be removed from the baseline `6x09` board.

## Direct Signal Mapping

This is not pin-for-pin. It is a design-intent mapping.

| Current `8085` signal/block | `6x09` equivalent role | Redesign note |
|---|---|---|
| `AD0-AD7` | `A0-A7` plus `D0-D7` | split buses, no multiplex latch |
| `A8-A15` | `A8-A15` | conceptually unchanged |
| `ALE` | none required for low address latch | remove latch-driven timing path |
| `74LS373` low-address latch | usually not needed | can reclaim board area |
| `/RD` | `R/W` plus decode gating | derive read strobes in glue logic |
| `/WR` | `R/W` plus decode gating | derive write strobes in glue logic |
| `IO/M` | `BA`, `BS`, or pure memory-map strategy | easiest path is memory-mapped I/O only |
| `READY` | `MRDY` or wait-state glue if used | optional in first pass |
| `/RESET_OUT` fanout | reset distribution | still required, but timing differs |
| `CLK` | `E` and `Q` clocks | requires new oscillator/divider approach |
| `HOLD` / `HLDA` | `BUSY`/bus-arbitration family as needed | likely omit from rev 1 |

## Recommended First-Pass Philosophy

Keep the first `6x09` board simple:

- no DMA
- no bus mastering
- no complicated wait-state system
- no split I/O space
- memory-map everything

That points to a board with:

- `6809` or `6309` in the CPU socket
- straight-through `A0-A15`
- straight-through `D0-D7`
- read/write strobes generated from `R/W` and address decode
- a small amount of glue for reset, clock, and chip-select timing

## Board A Device-Level Changes

### Likely removable

- `74LS373` low-address latch

### Likely retained

- data buffering or transceiver if the inter-board bus is long
- coarse decode support
- reset glue
- clock support logic

### Likely replaced or rethought

- `74LS245` direction/control logic
- all `ALE`-dependent routing
- `IO/M`-qualified decode logic
- oscillator network

## Clocking

This is one of the non-trivial parts.

An `8085` crystal arrangement does not directly translate into a `6809` bring-up design.

For the first pass, prefer:

- a known-good canned oscillator or divider approach
- conservative clock speed
- explicit probing of `E` and `Q`

Bring-up priority:

1. stable reset
2. valid `E` / `Q`
3. clean address bus activity after reset
4. ROM fetch at the reset vector

## Reset And Interrupts

A `6809` reset path is vector-driven, so the memory system has to be ready at reset fetch time.

Rev 1 recommendations:

- wire reset conservatively
- expose reset at a top-edge test point
- keep `NMI`, `IRQ`, and `FIRQ` pulled inactive unless intentionally used
- defer advanced interrupt usage until after ROM and RAM bring-up

## Strong Recommendation

Do not try to preserve the current `Board A` placement literally.

Preserve:

- top-edge test points
- bottom-edge bus egress
- central CPU placement

But redraw the rest around the `6x09` bus rather than forcing the `8085` topology to fit.

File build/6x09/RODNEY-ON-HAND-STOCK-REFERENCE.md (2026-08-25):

# Rodney On-Hand Stock Reference

Copied into `build/6x09` on `2026-08-25` so the `6x09` redesign can reason about current stock without touching the canonical inventory and stock documents.

Canonical source:

- [build-of-materials/RODNEY-ON-HAND-STOCK.md](/home/cartheur/ame/aiventure/aiventure-github/cartheur/aiventure-rodney/build-of-materials/RODNEY-ON-HAND-STOCK.md:1)
- [inventory/list.csv](/home/cartheur/ame/aiventure/aiventure-github/cartheur/aiventure-rodney/inventory/list.csv:1)

This is a working reference snapshot.

## Key Stock Relevant To `6x09`

| Category | Part | Current note |
|---|---|---|
| CPU | `EF6809P` | on hand |
| CPU | `MC6809P` | on hand |
| CPU | `HD63C09RP` | on hand in strong quantity |
| Memory | `AS6C62256-55PIN` | on hand with strong margin |
| Memory | `AS6C6264-55PCN` | on hand / planned with margin |
| Memory | `AT28C64B-15PU` | on hand / planned with margin |
| Glue logic | `74LS00` | in strong quantity |
| Glue logic | `74LS04` | in strong quantity |
| Glue logic | `74LS138` | available |
| Glue logic | `74LS139` | available |
| Latches / buffers | `74LS245` | available |
| Latches / buffers | `74LS273` | available |
| I/O | `74LS244` | available |
| I/O | `74LS164` | available |
| I/O | `74LS86` | available |
| Baseline-only extra | `74LS373` | on hand, though likely dropped for `6x09` |
| Boards | `Vector 8801-6` | on hand |
| Connectors | `R681-2` edge connectors | on hand |
| Sockets | `DIP-40`, `DIP-28`, `DIP-20`, `DIP-16`, `DIP-14` | generally covered well |
| Wiring | `30 AWG` Kynar | on hand |
| Wiring | red and black hookup wire | on hand |

## `6x09` Readout

What this stock snapshot says:

- the redesign is not blocked by lack of `6809` / `6309` CPUs
- the memory plan is already well covered
- most of the likely glue and support logic is already present
- the remaining uncertainty is architectural, not mainly procurement-based

## Important Caveat

This reference does **not** mean the `6x09` BOM is finished.

It means:

- the likely parts are broadly in hand
- the final `Board A` device list still depends on the `6x09` clock, reset, and control-glue schematic

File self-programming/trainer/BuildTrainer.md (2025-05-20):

# Building an 8085 Trainer Kit for the Self-Modifying Code

This guide details how to build a minimal 8085 trainer kit to deploy the self-modifying 8085 assembly code, which modifies a `JMP` instruction and uses an LED on the SOD pin to indicate self-programming. The trainer supports program execution at `0000H`, memory-mapped I/O at `2000H` (input) and `2001H` (output), and debugging, using common components for educational use.

## Step 1: Gather Components
The trainer requires components for the microprocessor, memory, clock, reset, I/O, and debugging.

### Components
1. **Microprocessor**: Intel 8085A (40-pin DIP).
2. **Memory**:
   - 6264 SRAM (8 KB, 28-pin DIP) for program and I/O.
   - Optional 2764 EPROM (8 KB) for permanent storage.
3. **Clock**: 6 MHz crystal, two 22 pF capacitors.
4. **Reset**: 10 µF capacitor, 10 kΩ resistor, push-button switch.
5. **LED Indicator**: LED, 330Ω–470Ω resistor, optional BC548 transistor, 1 kΩ resistor.
6. **I/O**:
   - 8-bit DIP switch or ADC0804 with potentiometer for `2000H`.
   - Output at `2001H` via RAM.
   - Optional 7-segment display/LCD (requires 8255 PPI).
7. **Debugging**: MAX232, DB9 for serial; optional LCD/7-segment.
8. **Breadboard/PCB**: Prototyping board, 40/28-pin sockets, jumper wires, soldering kit.
9. **Power**: 5V (7805 regulator, 9V input), 100 µF/0.1 µF capacitors.
10. **Miscellaneous**: 74LS373 (latch), 74LS138 (decoder), 10 kΩ resistors, logic probe.

### Sourcing Notes
- Available from DigiKey, Mouser, or eBay (vintage ICs).
- Cost: $50–$100.
- Substitutes: 80C85, 62256 RAM.

## Step 2: Design the Circuit
The circuit integrates the 8085 with memory, I/O, and SOD LED, ensuring code compatibility.

### 1. 8085 Connections
- **Power**: Vcc (pin 40) to 5V, Vss (pin 20) to ground, 0.1 µF capacitor.
- **Clock**: 6 MHz crystal between X1/X2 (pins 1–2), 22 pF capacitors to ground.
- **Reset**: RESET IN (pin 36) to 5V via 10 µF, ground via 10 kΩ, push-button.
- **Interrupts**: Ground TRAP (pin 6), RST 5.5–7.5 (pins 7–9), INTR (pin 12) via 10 kΩ.
- **SOD LED**: SOD (pin 4) to 330Ω resistor, to LED cathode, anode to 5V. SOD low = LED on.
- **Alternative**: SOD to BC548 base via 1 kΩ, emitter to ground, collector to LED cathode.

### 2. Address/Data Demultiplexing
- **74LS373**:
  - D0–D7 to AD0–AD7 (pins 12–19), Q0–Q7 to A0–A7, G to ALE (pin 30), OE to ground.
  - A8–A15 (pins 21–28) to memory.

### 3. Memory
- **6264 SRAM**:
  - A0–A12 to A0–A12 (A0–A7 from 74LS373, A8–A12 from 8085), D0–D7 to AD0–AD7.
  - OE to RD (pin 32), WE to WR (pin 31), CS via 74LS138.
  - Vcc to 5V, 0.1 µF capacitor.

### 4. Decoding
- **74LS138**:
  - A, B, C to A13–A15 (pins 26–28), G1 to IO/M (pin 34, inverted), G2A/G2B to ground.
  - Y0 to 6264 CS (`0000H`–`1FFFH`, includes `2000H`–`2001H`).

### 5. I/O
- **Input**: DIP switch to D0–D7, enabled at `2000H` (74LS138 Y1 or NAND gate). Alternative: ADC0804 with potentiometer.
- **Output**: Handled by RAM at `2001H`.

### 6. Serial Interface
- **MAX232**: SOD (buffered) to T1IN, SID (pin 5) to R1OUT, DB9 for PC. 1 µF capacitors.

### 7. Power
- **7805**: 9–12V input, 5V output, 100 µF/0.1 µF capacitors.

## Step 3: Assemble the Trainer
1. Install IC sockets (40-pin for 8085, 28-pin for 6264).
2. Wire power/ground rails, add decoupling capacitors.
3. Connect 8085 clock, reset, interrupts, SOD LED.
4. Wire 74LS373 for demultiplexing.
5. Connect 6264 RAM.
6. Wire 74LS138 for decoding.
7. Add DIP switch for input.
8. Connect MAX232 for serial.
9. Wire 7805 power supply.
10. Solder or secure connections, verify with multimeter.

## Step 4: Test the Trainer
1. **Power-On**: Check 5V, 3 MHz at CLK OUT (pin 37).
2. **Reset**: Press button, verify RESET OUT (pin 3).
3. **Memory**: Write/read `0000H`, `2000H`.
4. **SOD LED**: Test with `MVI A, 40H; SIM` (on), `C0H` (off).
5. **Serial**: Send/receive test byte via PC.
6. **Debug**: Check connections, IC orientation, clock.

## Step 5: Deploy the Code
1. Assemble `selfmod.asm` to `selfmod.hex` (e.g., A85).
2. Load via:
   - Monitor program (serial upload to RAM).
   - Manual entry (keypad).
   - EPROM (burn to 2764).
3. Set `2000H` to 60 or 40 (DIP switch or monitor).
4. Reset, run (`G 0000`).
5. Observe LED flicker during self-modification, check `2001H` (‘H’/’L’).

## Step 6: Finalize and Debug
- Add monitor program in EPROM (`8000H`–`FFFFH`).
- Optional: 7-segment/LCD via 8255.
- Debug: Check reset, clock, RAM CS, SOD, interrupts.
- Document: Label ICs, keep schematic/listing.

### Notes
- **Minimal Design**: Omits advanced peripherals for simplicity.
- **LED Timing**: Add delay loop for visibility.
- **Safety**: Verify pin assignments, LED polarity, power stability.
- **Resources**: 8085, 6264, 2764 datasheets; trainer manuals.

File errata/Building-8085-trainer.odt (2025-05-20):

Building an Intel 8085 Trainer to Experiment with Self-Programming

Abstract:

Building an 8085 trainer kit to deploy and run the self-modifying assembly code provided earlier involves assembling a functional 8085 microprocessor system with essential components for program execution, memory, I/O, and debugging. The trainer will support the code’s requirements: program storage and execution starting at 0000H, memory-mapped I/O at 2000H (input) and 2001H (output), and an LED indicator connected to the Serial Output Data (SOD) pin to signal self-modification. This guide outlines the components, circuit design, assembly steps, and testing procedures to create a minimal yet functional 8085 trainer kit, suitable for educational or hobbyist use. The design prioritizes simplicity, using common components and avoiding complex peripherals like the 8255 PPI, while ensuring compatibility with the code and the ability to observe self-programming.

Step 1: Gather Components

To build the 8085 trainer, you’ll need components for the microprocessor, memory, clock, reset, I/O, and debugging interfaces. Below is a list tailored to the code’s needs, based on typical 8085 trainer designs.

Components

1. Microprocessor:
  - Intel 8085A (or compatible, e.g., 80C85) microprocessor (40-pin DIP).
2. Memory:
  - RAM: 6264 (8 KB static RAM, 28-pin DIP) to store the program (0000H–00FFH) and I/O (2000H–2001H). A 4 KB chip (e.g., 6116) is sufficient, but 6264 is common.
  - Optional EPROM: 2764 (8 KB EPROM, 28-pin DIP) for permanent program storage, if desired.
3. Clock Circuit:
  - 6 MHz crystal (provides 3 MHz internal clock after 8085’s internal division).
  - Two 22 pF ceramic capacitors.
4. Reset Circuit:
  - 10 µF electrolytic capacitor.
  - 10 kΩ resistor.
  - Push-button switch (for manual reset).
5. LED Indicator (for SOD):
  - 1 LED (e.g., red, 20 mA, 2V forward voltage).
  - 330Ω or 470Ω resistor (current-limiting).
  - Optional: BC548 NPN transistor and 1 kΩ resistor (for brighter LEDs or higher current).
6. Input/Output:
  - Input: DIP switch (8-bit) or potentiometer with ADC (e.g., ADC0804) to set a value at 2000H.
  - Output: Memory-mapped output at 2001H (handled by RAM); no additional hardware needed unless visualizing output (e.g., via a display).
  - Optional: 7-segment display or LCD (requires additional interfacing, e.g., via 8255 PPI).
7. Debugging Interface:
  - Serial Interface: MAX232 (RS-232 to TTL converter) and DB9 connector for PC communication.
  - Monitor Program: Stored in EPROM (e.g., 2764) or preloaded in kit for memory programming.
  - Optional: 16x2 LCD or 4-digit 7-segment display for memory/register display.
8. Breadboard/PCB:
  - Prototyping board (e.g., perfboard or stripboard) or custom PCB.
  - 40-pin IC socket (for 8085), 28-pin sockets (for RAM/EPROM).
  - Jumper wires, soldering kit, or wire-wrap tools.
9. Power Supply:
  - 5V DC power supply (1A minimum, e.g., 7805 regulator with 9V input).
  - 100 µF and 0.1 µF capacitors (for power decoupling).
10. Miscellaneous:
  - 74LS373 (octal latch) for address/data bus demultiplexing.
  - 74LS138 (3-to-8 decoder) for memory and I/O selection.
  - Pull-down resistors (10 kΩ) for interrupt pins.
  - Logic probe, multimeter, or oscilloscope for debugging.

Sourcing Notes

- Availability: Most components (8085, 6264, 2764, 74LS series) are available from electronics suppliers (e.g., DigiKey, Mouser, or eBay for vintage ICs). Trainer kits like Vinytics VMC-8501 can serve as a reference or component source.
- Substitutes: Use CMOS equivalents (e.g., 80C85, 62256 RAM) for lower power if preferred.
- Cost: Expect $50–$100 for components, depending on sourcing and whether you use a PCB.

Step 2: Design the Circuit

The trainer’s circuit integrates the 8085 with memory, I/O, and the SOD LED, ensuring the self-modifying code can run. Below is the schematic breakdown, focusing on minimalism and compatibility with the code.

1. 8085 Microprocessor Connections

- Power:
  - Vcc (pin 40): +5V.
  - Vss (pin 20): Ground.
  - Add 0.1 µF ceramic capacitor between Vcc and Vss near the 8085 for decoupling.
- Clock:
  - Connect a 6 MHz crystal between X1 (pin 1) and X2 (pin 2).
  - Attach 22 pF capacitors from X1 and X2 to ground.
  - CLK OUT (pin 37) provides a 3 MHz clock for debugging (optional).
- Reset:
  - RESET IN (pin 36): Connect to 5V via 10 µF capacitor and to ground via 10 kΩ resistor (RC reset circuit).
  - Add a push-button switch across the capacitor for manual reset (press to ground).
  - RESET OUT (pin 3): Leave unconnected or monitor for reset signal.
- Interrupts:
  - Ground TRAP (pin 6), RST 5.5–7.5 (pins 7–9), and INTR (pin 12) via 10 kΩ pull-down resistors to prevent spurious interrupts.
  - INTA (pin 11): Leave unconnected (no interrupts used).
- Control Signals:
  - ALE (pin 30): Address Latch Enable, used for bus demultiplexing.
  - RD (pin 32), WR (pin 31): Read/Write signals for memory/I/O.
  - IO/M (pin 34): Distinguishes memory vs. I/O access.
  - S0, S1 (pins 29, 33): Status signals (optional for debugging).
- SOD LED:
  - SOD (pin 4): Connect to a 330Ω resistor, resistor to LED cathode, LED anode to 5V.
  - Logic: SOD low (via SIM with 40H) turns LED on (current sinks to SOD); SOD high (C0H) turns LED off.
  - Alternative (for brighter LED): Connect SOD to BC548 base via 1 kΩ resistor, emitter to ground, collector to LED cathode, LED anode to 5V via 330Ω resistor. SOD high turns LED on.
- SID (pin 5): Leave unconnected (no serial input used).

2. Address/Data Bus Demultiplexing

- The 8085 multiplexes the lower 8 address bits (A0–A7) with the data bus (AD0–AD7, pins 12–19).
- 74LS373 Latch:
  - Inputs D0–D7: Connect to AD0–AD7 (pins 12–19).
  - Outputs Q0–Q7: Provide demultiplexed A0–A7 to memory.
  - G (Enable): Connect to ALE (pin 30). When ALE is high, the latch captures A0–A7.
  - OE (Output Enable): Tie to ground (always enabled).
- Upper Address Bus:
  - A8–A15 (pins 21–28): Directly connect to memory address lines.
- Data Bus:
  - After demultiplexing, AD0–AD7 (pins 12–19) serve as the data bus (D0–D7).

3. Memory (RAM)

- 6264 SRAM (8 KB):
  - Address lines A0–A12: Connect A0–A7 from 74LS373 outputs, A8–A12 from 8085 A8–A12 (pins 21–25).
  - Data lines D0–D7: Connect to 8085 AD0–AD7 (pins 12–19).
  - Control signals:
    - CS (Chip Select, active low): Connect via 74LS138 decoder (see below).
    - OE (Output Enable, active low): Connect to 8085 RD (pin 32).
    - WE (Write Enable, active low): Connect to 8085 WR (pin 31).
  - Power: Vcc to 5V, Vss to ground, 0.1 µF capacitor across Vcc–Vss.
  - Unused pins (e.g., A13): Tie to ground or leave floating (per datasheet).
- Memory Mapping:
  - Map RAM to cover 0000H–3FFFH (8 KB). The code runs at 0000H–00FFH, with I/O at 2000H–2001H.
  - The 6264 handles both program and I/O, as the code uses memory-mapped I/O.

4. Memory and I/O Decoding

- 74LS138 Decoder:
  - Use to generate chip selects for RAM and potential I/O.
  - Inputs:
    - A, B, C: Connect to A13–A15 (8085 pins 26–28) for address decoding.
    - G1: Connect to IO/M (pin 34) inverted (use 74LS04) to enable for memory access (IO/M = 0).
    - G2A, G2B: Tie to ground or control signals (e.g., RD/WR for finer control).
  - Outputs:
    - Y0 (active low): Connect to 6264 CS for 0000H–1FFFH (A15–A13 = 000).
    - Y1: Reserve for 2000H–3FFFH if separate I/O is needed; here, Y0 covers both program and I/O.
  - This ensures RAM is selected for all accesses in 0000H–3FFFH, including 2000H–2001H.

5. Input/Output

- Input (at 2000H):
  - DIP Switch: Connect an 8-bit DIP switch to the data bus (D0–D7) via 10 kΩ pull-up resistors to 5V. Enable the switch output to the data bus when 2000H is read (use 74LS138 Y1 or a NAND gate with A13, RD, and IO/M).
  - Alternative: Use a potentiometer (10 kΩ) with an ADC0804 to generate a 0–255 value. Connect ADC output to D0–D7, triggered by a read at 2000H.
  - For simplicity, manually write the input value to 2000H using a monitor program (see deployment).
- Output (at 2001H):
  - Handled by RAM (6264) at 2001H. No additional hardware needed unless visualizing output.
  - Optional Display: Add a 7-segment display or LCD via an 8255 PPI to show ‘H’ or ‘L’, but this is unnecessary for basic operation.
- SOD LED:
  - As described, SOD drives the LED to indicate self-modification.

6. Serial Interface (for Monitor Program)

- MAX232:
  - Connect 8085 SID (pin 5, optional for input) and SOD (pin 4, shared with LED) to MAX232 for TTL-to-RS-232 conversion.
  - MAX232 T1IN to SOD (via buffer to avoid LED interference), R1OUT to SID.
  - T1OUT, R1IN to DB9 connector for PC serial port.
  - Add 1 µF capacitors for MAX232 charge pumps (per datasheet).
- Purpose: Allows loading the program via a PC (e.g., Tera Term) and running a monitor program for memory access.
- Alternative: Use a USB-to-serial adapter if the kit lacks RS-232.

7. Power Supply

- 7805 Regulator:
  - Input: 9–12V DC (e.g., wall adapter).
  - Output: 5V to Vcc of all ICs (8085, 6264, 74LS373, 74LS138, MAX232).
  - Add 100 µF capacitor at input, 0.1 µF at output for stability.
- Distribution:
  - Use a power rail on the breadboard/PCB.
  - Ensure all ICs have decoupling capacitors (0.1 µF) near Vcc pins.

Step 3: Assemble the Trainer

With components and a schematic, assemble the circuit on a breadboard, perfboard, or custom PCB. Breadboard is recommended for prototyping, while perfboard or PCB is better for permanence.

Assembly Steps

1. Place IC Sockets:
  - Install 40-pin socket for 8085, 28-pin sockets for 6264 (RAM) and 2764 (optional EPROM), 20-pin for 74LS373, 16-pin for 74LS138, and 16-pin for MAX232.
  - Label sockets to avoid confusion.
2. Connect Power and Ground:
  - Wire 5V and ground rails to all IC Vcc and Vss pins.
  - Add decoupling capacitors (0.1 µF) across Vcc–Vss for each IC.
3. Wire the 8085:
  - Connect clock circuit (6 MHz crystal, 22 pF capacitors) to X1/X2.
  - Wire reset circuit to RESET IN (10 µF capacitor to 5V, 10 kΩ resistor to ground, push-button).
  - Ground interrupt pins via 10 kΩ resistors.
  - Connect SOD to LED circuit (330Ω resistor to cathode, anode to 5V).
4. Demultiplex Address/Data:
  - Wire 74LS373: AD0–AD7 to D0–D7 inputs, Q0–Q7 to A0–A7, ALE to G, OE to ground.
  - Connect A8–A15 (8085 pins 21–28) to memory.
5. Connect RAM:
  - Wire 6264: A0–A12 to A0–A12 (A0–A7 from 74LS373, A8–A12 from 8085), D0–D7 to AD0–AD7, OE to RD, WE to WR, CS to 74LS138 Y0.
6. Set Up Decoding:
  - Wire 74LS138: A, B, C to A13–A15, G1 to IO/M (inverted), G2A/G2B to ground, Y0 to 6264 CS.
7. Add I/O:
  - Connect DIP switch to data bus, enabled by a read at 2000H (use 74LS138 Y1 or NAND gate).
  - Output at 2001H uses RAM; no additional wiring needed.
8. Wire Serial Interface:
  - Connect MAX232 to SOD (buffered), SID, and DB9. Add 1 µF capacitors.
9. Power Supply:
  - Connect 7805 regulator, input capacitors (100 µF, 0.1 µF), and distribute 5V/ground.
10. Inspect and Solder:
  - Double-check connections using a multimeter for continuity.
  - Solder on perfboard or secure on breadboard. Use wire-wrap for clean prototyping.

Step 4: Test the Trainer

Before deploying the code, verify the trainer’s functionality.

Testing Steps

1. Power-On Test:
  - Apply 5V power.
  - Check Vcc (5V) and ground at all ICs.
  - Verify 3 MHz clock at CLK OUT (pin 37) with an oscilloscope or logic probe.
2. Reset Test:
  - Press reset button; confirm RESET OUT (pin 3) goes high.
  - Check address bus (A0–A15) starts at 0000H (use logic probe).
3. Memory Test:
  - Write a test value (e.g., FFH) to 0000H using a temporary monitor program or manual entry.
  - Read back to confirm RAM functionality.
  - Verify 2000H–2001H are accessible.
4. SOD LED Test:
  - Run a test program to toggle SOD:
    assembly
    MVI A, 40H ; SOD low (LED on)
    SIM
    HLT
  - Confirm LED lights. Change to C0H to turn LED off.
5. Serial Interface Test:
  - Connect to PC via serial port (9600 baud, 8N1).
  - Send a test byte from the PC; check if SOD toggles or SID receives (if used).
6. Debugging:
  - If the trainer fails (e.g., no clock, LED stuck), check:
    - Loose connections or solder joints.
    - Correct IC orientation (pin 1).
    - Crystal oscillation (replace if dead).
    - Power supply stability (ripple < 50 mV).

Step 5: Deploy the Code

Follow the deployment steps from the previous response, adapted to the trainer:

1. Assemble the Code:
  - Use an assembler (e.g., A85) to convert selfmod.asm to selfmod.hex.
  - Verify addresses in the listing file (e.g., JMP_MOD ~`0020H`).
2. Load the Code:
  - Monitor Program (if included in EPROM or kit):
    - Connect the trainer’s serial port to a PC.
    - Use Tera Term to upload selfmod.hex (Intel HEX format).
    - Command: M 0000 to verify code in memory.
  - Manual Entry:
    - Use the kit’s keypad (if available) to enter opcodes at 0000H from the listing file.
  - EPROM (if used):
    - Burn selfmod.bin to a 2764 EPROM using a programmer.
    - Insert EPROM at 0000H, disable RAM at that range.
3. Set Input:
  - Write a test value to 2000H:
    - Via monitor: M 2000, enter 60 (high) or 40 (low).
    - Via DIP switch: Set switches to 00111100 (40) or 00111110 (60).
    - Via ADC: Adjust potentiometer to output ~40 or 60.
4. Execute:
  - Reset the 8085 (press button).
  - Run: Use monitor command G 0000 or set PC to 0000H and press “Run”.
5. Observe:
  - LED: Lights briefly (~20–30 µs) during self-modification (MODIFY_LOW/MODIFY_HIGH).
  - Output: Check 2001H (D 2001): 48H (‘H’) for input ≥ 50, 4CH (‘L’) for < 50.
  - Debug: If no output, use a logic probe on AD0–AD7, A0–A15, and control signals (RD, WR, ALE) to trace execution.

Step 6: Finalize and Debug

- Add a Monitor Program:
  - Program a 2764 EPROM with a simple monitor (e.g., from open-source 8085 kits) to facilitate code loading, memory editing, and execution.
  - Map EPROM at 8000H–FFFFH to avoid conflict with RAM at 0000H.
- Enhance I/O:
  - Add a 7-segment display or LCD via 8255 PPI to show 2001H output (‘H’/’L’).
  - Implement a keypad for dynamic input at 2000H.
- Debugging Tips:
  - No Execution: Check reset circuit, clock, and RAM CS signal.
  - LED Stuck: Verify SIM instructions (40H/C0H) and SOD resistor value.
  - Wrong Output: Confirm 2000H input value and JMP_MOD address in the listing file.
  - Interrupts: Ensure interrupt pins are grounded.
- Documentation:
  - Label all ICs, connectors, and switches on the board.
  - Keep a schematic and the selfmod.lst file for reference.

Notes

- Minimal Design: This trainer omits advanced features (e.g., 8255 PPI, full keypad/display) to focus on the code’s needs. Add peripherals for a production-grade kit.
- Timing: The LED’s brief on-time (~20–30 µs) may need a delay loop for visibility:
  assembly
  ; In MODIFY_LOW/MODIFY_HIGH, after MVI A, 40H; SIM:
  LXI B, 1000H ; Delay loop (~1 ms at 3 MHz)
  DELAY: DCX B
  MOV A, B
  ORA C
  JNZ DELAY
- Safety:
  - Double-check IC pin assignments (e.g., 8085 pin 40 = Vcc, not ground).
  - Use a current-limited power supply to avoid damage.
  - Verify LED polarity (anode to 5V) to protect SOD.
- Scalability: The 6264 RAM supports larger programs. Add EPROM for a monitor or expand I/O for complex applications.
- Resources: Refer to 8085 datasheets (Intel, 1978), 6264/2764 datasheets, and trainer kit manuals (e.g., Dynalog 8085) for pinouts and timing.

Part substitutions

Yes, you can use a 62256 SRAM and a 5 MHz clock for the 8085 trainer kit to deploy the self-modifying assembly code, but there are considerations to ensure compatibility with the 8085 microprocessor, the code’s requirements, and the overall system design. Below, I’ll explain the feasibility, necessary adjustments, and potential impacts of these substitutions, tailored to the trainer kit described for running the code with memory-mapped I/O at 2000H (input) and 2001H (output) and an LED on the SOD pin.

Using 62256 SRAM

The 62256 is a 32 KB static RAM (256 Kbit, organized as 32K x 8), compared to the 6264’s 8 KB (64 Kbit, 8K x 8) specified in the original trainer design. The code requires only a small memory range (0000H–00FFH for the program, 2000H–2001H for I/O), so the 62256 is more than sufficient but introduces slight changes.

Compatibility

- Pinout:
  - The 62256 (28-pin DIP) is pin-compatible with the 6264, with identical key pins:
    - A0–A14 (pins 1–9, 22–25, 27) vs. 6264’s A0–A12.
    - D0–D7 (pins 11–13, 15–19) same as 6264.
    - CS (pin 20, active low), OE (pin 22, active low), WE (pin 27, active low) same as 6264.
    - Vcc (pin 28), Vss (pin 14) same.
  - The extra address lines (A13–A14) on the 62256 allow addressing up to 0000H–7FFFH (32 KB) vs. 6264’s 0000H–1FFFH (8 KB).
- Access Time:
  - The 62256 typically offers access times of 70–150 ns (e.g., HM62256LP-10 is 100 ns), compatible with the 8085’s timing at 3 MHz (original 6 MHz crystal, divided to 3 MHz internally).
  - The 8085 requires memory access times of ~200 ns or faster at 3 MHz. The 62256’s speed is adequate (100 ns < 200 ns).
- Power:
  - The 62256 (CMOS) consumes slightly more power than the 6264 but is still low (e.g., ~50 mA active, <1 mA standby). The 5V power supply (7805, 1A) can handle it.
- Code Compatibility:
  - The code uses 0000H for the program and 2000H–2001H for I/O, all within the 62256’s 32 KB range.
  - No code changes are needed, as 2000H is accessible in the 62256’s address space.

Adjustments

1. Address Decoding:
  - The original design uses a 74LS138 decoder with A13–A15 to select the 6264 for 0000H–1FFFH (Y0 output). For the 62256, extend the range to 0000H–7FFFH:
    - Connect A13–A14 (62256 pins 23, 27) to 8085 A13–A14 (pins 26–27) or ground unused lines if only 8 KB is needed.
    - Adjust the 74LS138 to select the 62256 for 0000H–7FFFH (A15 = 0). Use Y0 for CS, as before, but ensure A15 is low (e.g., tie 8085 A15 to ground or decode via 74LS138 G1).
    - Example: Set 74LS138 G1 to IO/M inverted, A = A13, B = A14, C = A15. Y0 active when A15–A13 = 000, covering 0000H–7FFFH.
  - If you ground A13–A14, the 62256 behaves like a 6264 (8 KB), requiring no decoder changes.
2. Wiring:
  - Connect A0–A12 as in the original (A0–A7 from 74LS373, A8–A12 from 8085 pins 21–25).
  - Connect A13–A14 to 8085 A13–A14 (pins 26–27) or ground if unused.
  - D0–D7, CS, OE, WE, Vcc, Vss remain identical to 6264 wiring.
3. Memory Mapping:
  - The 62256 covers 0000H–7FFFH. Ensure no other devices (e.g., EPROM) overlap this range unless decoded separately (e.g., EPROM at 8000H–FFFFH).
  - 2000H–2001H are within the 62256’s range, so memory-mapped I/O works as is.

Impacts

- Advantages:
  - 32 KB allows future expansion (e.g., larger programs or monitor software).
  - CMOS 62256 is low-power and widely available.
- Disadvantages:
  - Slightly more complex decoding if using the full 32 KB (requires A15 handling).
  - Unused memory (only ~256 bytes needed) may be overkill, but this doesn’t affect functionality.
- Trainer Stability:
  - The 62256’s faster access time ensures reliable operation.
  - No impact on the code’s self-modification or SOD LED functionality.

Recommendation

- Use the 62256 as a drop-in replacement for the 6264 by grounding A13–A14 to limit it to 8 KB, avoiding decoder changes. If you plan to use the full 32 KB, modify the 74LS138 to select 0000H–7FFFH with A15 = 0.

Using a 5 MHz Clock

The original design uses a 6 MHz crystal (divided to 3 MHz internally by the 8085). A 5 MHz crystal results in a 2.5 MHz internal clock, which is within the 8085’s operating range but requires evaluation.

Compatibility

- 8085 Clock Range:
  - The 8085A operates from 0.5 MHz to 3 MHz (6 MHz crystal max, divided by 2).
  - A 5 MHz crystal yields 2.5 MHz, well within specs (no overclocking issues).
- Timing:
  - At 2.5 MHz, the 8085’s clock cycle is 400 ns (1/2.5 MHz) vs. 333 ns at 3 MHz.
  - Memory access time requirement: ~250 ns at 2.5 MHz (slightly relaxed from ~200 ns at 3 MHz).
  - The 62256’s 100 ns access time is more than adequate (100 ns < 250 ns).
- Code Compatibility:
  - The self-modifying code has no timing-critical sections (e.g., no delay loops or real-time I/O).
  - The SOD LED’s on-time during self-modification (~24–36 µs at 2.5 MHz vs. ~20–30 µs at 3 MHz) remains too brief for naked-eye visibility without a delay loop, but this is unchanged from the original.
- Components:
  - The 5 MHz crystal is compatible with the clock circuit (22 pF capacitors to ground, connected to X1/X2, pins 1–2).
  - All other components (74LS373, 74LS138, 62256) operate reliably at 2.5 MHz.

Adjustments

1. Clock Circuit:
  - Replace the 6 MHz crystal with a 5 MHz crystal.
  - Keep 22 pF capacitors (suitable for 5 MHz per 8085 datasheet).
  - No changes to X1/X2 wiring (pins 1–2).
2. Verification:
  - After assembly, check CLK OUT (pin 37) for ~2.5 MHz (400 ns period) using an oscilloscope or logic probe.
3. No Code Changes:
  - The code’s logic (input comparison, JMP modification, SOD control) is frequency-independent.
  - If you add a delay loop for LED visibility (e.g., LXI B, 1000H; DELAY: DCX B; ...), adjust the counter for similar timing:
    - At 3 MHz, 1000H (~4096 cycles) takes ~1.37 ms.
    - At 2.5 MHz, use ~`0D55H` (3400 cycles) for ~1.36 ms (close enough).

Impacts

- Advantages:
  - Slightly slower clock reduces power consumption and heat (minor for 8085A).
  - Relaxed timing margins improve stability with slower components (though 62256 is fast).
- Disadvantages:
  - Execution speed decreases by 17% (2.5 MHz vs. 3 MHz), but this is negligible for the code’s short runtime (100 cycles).
  - LED on-time extends slightly (e.g., ~28 µs vs. ~23 µs for self-modification), still requiring a delay loop for visibility.
- Trainer Stability:
  - The 2.5 MHz clock is fully supported, with no risk to the 8085 or peripherals.
  - No impact on self-modification or SOD functionality.

Recommendation

- The 5 MHz crystal is a safe choice, requiring only a swap of the crystal. No other hardware or code changes are needed unless you add a delay loop for LED visibility, where a minor counter adjustment ensures consistent timing.

Integration with Trainer Design

Using the 62256 RAM and 5 MHz clock requires minimal changes to the trainer design:

- RAM Wiring:
  - Connect 62256 as described for 6264, with A0–A12 to A0–A12, D0–D7 to AD0–AD7, OE to RD, WE to WR, CS to 74LS138 Y0.
  - Ground A13–A14 (pins 23, 27) for 8 KB mode, or connect to 8085 A13–A14 and adjust 74LS138 for 32 KB (0000H–7FFFH, A15 = 0).
- Clock Wiring:
  - Connect 5 MHz crystal to X1/X2 (pins 1–2), 22 pF capacitors to ground.
- Decoding:
  - For 8 KB mode (A13–A14 grounded), keep 74LS138 as is (Y0 for 0000H–1FFFH).
  - For 32 KB, set 74LS138 G1 to IO/M inverted, C = A15, B = A14, A = A13, Y0 for 0000H–7FFFH.
- Power:
  - The 7805 (1A) supports the 62256’s slightly higher current and 2.5 MHz operation.
- Code Deployment:
  - No changes to the code or deployment steps (assemble to selfmod.hex, load via monitor/serial, set input at 2000H, run at 0000H).
  - The 62256 handles 0000H (program) and 2000H–2001H (I/O) identically to the 6264.
- Testing:
  - Verify 2.5 MHz at CLK OUT (pin 37).
  - Confirm 62256 access at 0000H and 2000H–2001H via monitor or DIP switch input.
  - Check SOD LED behavior (on during MODIFY_LOW/MODIFY_HIGH, off otherwise).
  - Output at 2001H (‘H’ for input ≥ 50, ‘L’ for < 50) remains unchanged.

Potential Issues and Mitigations

- 62256 Decoding:
  - If A13–A14 are not grounded and decoding is incorrect, the 62256 may not respond at 2000H. Ensure 74LS138 selects the correct range or ground unused address lines.
  - Test: Write FFH to 2000H, read back to confirm.
- Clock Stability:
  - A faulty 5 MHz crystal may fail to oscillate. Verify with an oscilloscope or swap with a known-good crystal.
  - Ensure 22 - The 62256’s larger capacity allows for future expansion, such as adding a monitor program or additional code, without requiring hardware changes.
- Performance:
  - The 2.5 MHz clock slightly slows execution (17% slower), but the code’s short runtime (100 cycles) makes this negligible. If precise timing is needed (e.g., for LED visibility), adjust delay loops as noted.
- Debugging:
  - If the trainer fails to run the code, check:
    - 62256 CS signal (74LS138 Y0 active for 0000H–7FFFH).
    - Clock frequency (2.5 MHz at CLK OUT).
    - SOD wiring (330Ω resistor, correct polarity).
    - Memory writes to 2000H and 2001H via monitor or DIP switch.

Conclusion

Using a 62256 RAM and a 5 MHz clock is fully compatible with the 8085 trainer and the self-modifying code. The 62256 can replace the 6264 with minimal changes (ground A13–A14 or adjust decoding for 32 KB), and the 5 MHz crystal (2.5 MHz internal) requires only a crystal swap. No code changes are needed, and the SOD LED, memory-mapped I/O, and self-modification logic work as intended. The 62256’s larger capacity supports future expansion, and the 2.5 MHz clock ensures stable operation with relaxed timing. These substitutions maintain the trainer’s simplicity while aligning with Intel’s concerns about self-modifying code’s risks (e.g., by making the process observable via the LED).

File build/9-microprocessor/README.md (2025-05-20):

## Chapter 9: Adding the Microprocessor (and building the nest)

Whatever your source of good fortune and success might be, this is the time to call upon it. You’ll need a lot of positive thinking and all the technical talent you can muster. The work in this chapter represents the worst and the best of everything you do with Rodney. You are going to have to dig in and make things work on your own, because the work is tricky.

### The Task

Is to...

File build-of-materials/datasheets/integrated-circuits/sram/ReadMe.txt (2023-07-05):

MMN2114 -3

4096-Bit NMOS Static RAM

by Microelectronica, Romania, Europe

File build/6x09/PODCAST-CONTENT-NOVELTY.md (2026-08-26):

# Podcast Content: The Novelty In Rodney's `6x09` / `GA144` Borderline

Date: `2026-08-26`

## Core Idea

The novelty is not merely that Rodney moves from an `i8085` to an `MC6809P` or `HD63C09RP`.

It is also not merely that a `GA144` is added.

The real novelty is that the crystal is treated as a **borderline** between two computational regimes living on the same `Board A`.

## Short Version

On one side of the borderline:

- `Rev. 0`: `i8085`
- `Rev. 1`: `MC6809P`
- `Rev. 2`: `HD63C09RP`
- `Rev. 3`: `MC6809P/HD63C09RP/SC67475P`

This side is the conventional machine:

- bused CPU design
- decode logic
- ROM and RAM
- learned-state tables
- memory-mapped I/O

On the other side of the borderline:

- `GA144`

This side is responsible for the resonant domain:

- exciting the crystal under program control
- observing the resonant device
- sustaining oscillation with minimal external circuitry

That is the split.

## Why It Is Interesting

Normally, a crystal in a CPU design is treated as a support component:

- necessary
- passive
- uninteresting once it oscillates

Here, the crystal is elevated into an architectural feature.

It is not just a clock source.

It is the borderline where:

- conventional CPU timing ends
- `GA144`-driven resonant excitation and control begins

## The Conventional Alternative

The project nearly took a much more ordinary path.

The `6x09` branch was heading toward using a `74LS74` flip-flop to bang on the crystal until resonance was found and stabilized.

That would have worked as a conventional engineering move.

But it is less elegant because:

- it treats the crystal as something to be forced from outside with standard TTL timing tricks
- it keeps the resonance problem inside a conventional glue-logic mindset

## What `GA144` Changes

According to `AN002`, the `GA144` can do something more unusual:

- connect a resonant device between a single GPIO pin and ground
- excite it under software control
- observe it via asynchronous pin wake-up
- keep it oscillating by synchronously pumping energy back into it
- do all this with minimal external circuitry

That means the resonance problem becomes programmable.

Instead of brute-forcing the crystal with a flip-flop-centered scheme, the design can interact with the resonant device much more directly.

## The Deeper Novelty

This creates a division of labor at the physics boundary.

The conventional CPU side handles:

- symbolic behavior
- state transitions
- memory maps
- Beta/Gamma style learned-state experiments

The `GA144` side handles:

- intimate contact with the resonant behavior of the crystal
- low-level timing emergence
- excitation and observation in the resonance domain

So the novelty is not just hybrid hardware.

It is a hybrid architecture where the split occurs at the crystal borderline itself.

## Why That Matters For Rodney

Rodney is already about crossing boundaries:

- fixed code versus learned response
- support routines versus writable behavior
- environment versus action

This crystal-borderline idea extends that pattern downward into the hardware substrate.

Now the machine is not only split between:

- ROM and RAM
- CPU and learned state

It is also split between:

- conventional digital control
- resonant excitation and observation

That gives the project a stronger conceptual shape.

## Useful Talking Point

The interesting move here is not "we replaced the `8085`."

The interesting move is:

> we turned the crystal from a passive support part into the borderline between a classical CPU machine and a programmable resonant domain managed by `GA144`

## Episode Angle

A good podcast framing could be:

1. Rodney begins as a historical `8085` machine.
2. The redesign toward `MC6809P` and `HD63C09RP` seems at first like a normal CPU migration.
3. The real conceptual break appears at the crystal.
4. A conventional engineer might use a `74LS74` to hammer the oscillator into life.
5. `GA144`, following `AN002`, offers a cleaner idea: treat resonance as something software can excite, sense, and sustain.
6. That turns the crystal into an architectural borderline rather than a hidden support part.

## Related References

- [README.md](/home/cartheur/ame/aiventure/aiventure-github/cartheur/aiventure-rodney/build/6x09/README.md:1)
- [AN002-GA144-CRYSTAL-BOUNDARY.md](/home/cartheur/ame/aiventure/aiventure-github/cartheur/aiventure-rodney/build/6x09/AN002-GA144-CRYSTAL-BOUNDARY.md:1)
- [AN002-171106-OSC.pdf](/home/cartheur/ame/aiventure/aiventure-github/cartheur/aiventure-rodney/build/6x09/AN002-171106-OSC.pdf)

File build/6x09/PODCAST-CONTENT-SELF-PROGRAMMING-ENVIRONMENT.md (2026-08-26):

# Podcast Content: How The `GA144` Borderline Deepens Rodney's Self-Programming And Environmental Novelty

Date: `2026-08-26`

## Core Claim

The `GA144` crystal-borderline idea does not replace Rodney's original self-programming motif.

It deepens it.

Rodney was already unusual because it was not just a fixed-program machine. Its behavior was meant to be shaped by writable memory, learned response, and environmental experience.

Adding `GA144` at the crystal borderline extends that novelty downward into the physical timing substrate of the machine.

In revision terms, that means the borderline deepening begins once `Board A` moves from `Rev. 0` `i8085` into `Rev. 1` `MC6809P` with `GA144`, and continues through `Rev. 2` `HD63C09RP` and `Rev. 3` `MC6809P/HD63C09RP/SC67475P`.

## Rodney's Original Self-Programming Motif

In the classic Rodney framing, the novel claim is that the machine does not merely execute a static instruction stream forever.

It:

- stores learned response data
- indexes that data by environmental state
- alters future response based on prior experience
- changes the memory structures that influence later action

That already pushes beyond a simple fixed-control robot or anything contemplated up-until-now.

The key idea is:

- the machine's future is not fully frozen at power-up

## What The New Borderline Adds

With the `GA144` inclusion, the machine no longer appears as only:

- a conventional CPU
- some RAM
- some learned tables

Instead, it becomes layered.

One layer still handles symbolic and behavioral structure:

- environment bits
- Beta/Gamma learned-state behavior
- action outputs
- memory maps

Another layer operates at the crystal borderline:

- exciting the resonant device
- observing resonance behavior
- sustaining oscillation
- interacting directly with a physical timing regime

That expands the meaning of adaptation.

## Why This Strengthens The Self-Programming Story

Originally, Rodney's self-programming claim lives in writable behavioral memory.

Now the system also includes a component that does not merely consume a clock as a passive utility.

Instead, part of the machine actively participates in the emergence and maintenance of the timing reference itself.

That makes the machine feel less like:

- a CPU running a modifiable lookup structure

and more like:

- a layered adaptive system in which symbolic behavior and physical timing are both treated as meaningful domains

The novelty is that adaptation is no longer confined to abstract state tables.

It reaches toward the physical substrate that helps organize the machine's timing and coordination.

## Environmental Interaction Becomes Richer

In the earlier Rodney picture, environmental interaction is mostly read as:

- sense the world
- encode the state in bits
- index memory
- emit a response

That is already important, but it is still a fairly classical digital picture.

With the `GA144` borderline, the machine's style of engagement becomes richer:

- sense
- excite
- observe
- stabilize
- respond

This matters because the machine is no longer only representing the environment in memory.

Part of the machine is also operating in a regime where interaction depends on timing, resonance, wake-up, and maintenance of oscillatory behavior.

That gives Rodney a more embodied form of environmental novelty.

## Why This Feels More Embodied

The `GA144` side is not merely calculating about the crystal.

It is participating in a physical condition that must be:

- initiated
- detected
- sustained
- used

That makes the environmental story more intimate.

The machine is not only observing external states and choosing outputs.

It is also maintaining a relation to a physical resonant process at its own borderline.

## The Deeper Shift

The deeper shift is that self-programming now spans more than one layer.

Before:

- support code
- runtime code
- learned memory

After:

- support code
- runtime code
- learned memory
- resonant excitation and timing interaction at the crystal borderline

That is why the project becomes more than a CPU migration story.

It becomes a story about how adaptation can exist simultaneously:

- in memory
- in control
- in timing
- in physical interaction

## A Strong Podcast Line

One strong way to say this aloud is:

> Rodney originally learns by rewriting what future situations mean in memory.  
> With the `GA144` at the crystal borderline, the machine's adaptive character reaches deeper, toward the physical timing substrate that helps hold the machine together.

## Another Strong Line

> The novelty is not just that Rodney can change its responses.  
> The novelty is that part of the redesigned machine participates in the resonant conditions under which those responses become organized in time.

## Episode Angle

A useful episode arc could be:

1. Rodney begins with the old self-programming claim: behavior is not fixed because learned memory can influence future action.
2. That alone already challenges the simple idea of a robot as a static program.
3. The redesign then introduces a second novelty: the crystal becomes a borderline.
4. The `GA144` interacts with resonance directly, rather than treating the clock as a hidden support utility.
5. As a result, the machine's adaptive story expands from memory revision into embodied timing interaction.
6. Rodney becomes more than a self-modifying controller; it becomes a layered machine whose symbolic and physical regimes meet at the crystal.

## Why This Matters Conceptually

Rodney has always hovered between:

- mechanism and behavior
- fixed structure and learned response
- engineering artifact and adaptive machine

The crystal-borderline idea sharpens that identity.

It says the machine is not only adaptive in what it remembers.

It is also architected around a meaningful boundary where physical resonance and symbolic behavior meet.

That is a more original story than either:

- a plain retro CPU rebuild
- a plain self-modifying-code curiosity

## Related References

- [PODCAST-CONTENT-NOVELTY.md](/home/cartheur/ame/aiventure/aiventure-github/cartheur/aiventure-rodney/build/6x09/PODCAST-CONTENT-NOVELTY.md:1)
- [README.md](/home/cartheur/ame/aiventure/aiventure-github/cartheur/aiventure-rodney/build/6x09/README.md:1)
- [AN002-GA144-CRYSTAL-BOUNDARY.md](/home/cartheur/ame/aiventure/aiventure-github/cartheur/aiventure-rodney/build/6x09/AN002-GA144-CRYSTAL-BOUNDARY.md:1)
- [AN002-171106-OSC.pdf](/home/cartheur/ame/aiventure/aiventure-github/cartheur/aiventure-rodney/build/6x09/AN002-171106-OSC.pdf)

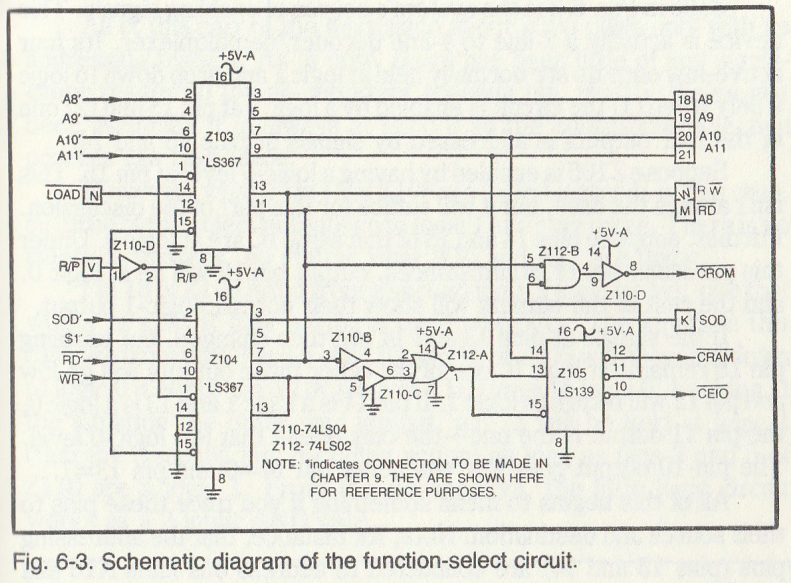
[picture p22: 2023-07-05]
build/6-function-select/images/fig.6-3.png

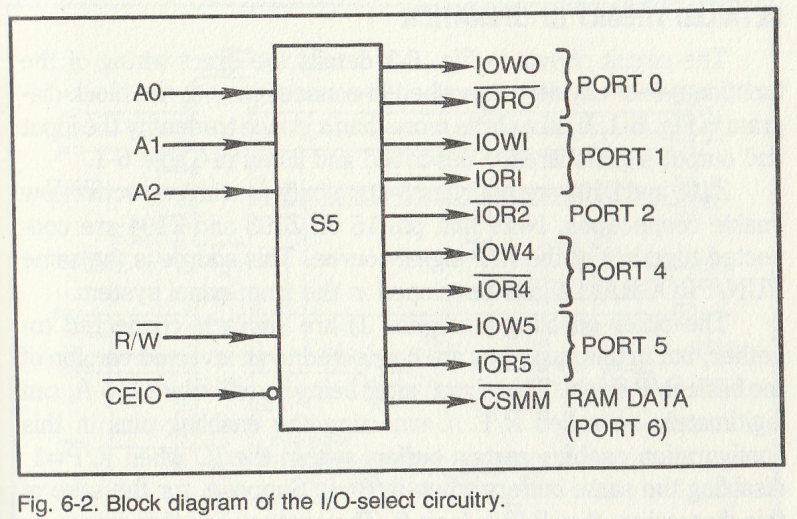
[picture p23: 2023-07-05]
build/6-function-select/images/fig.6-2.png

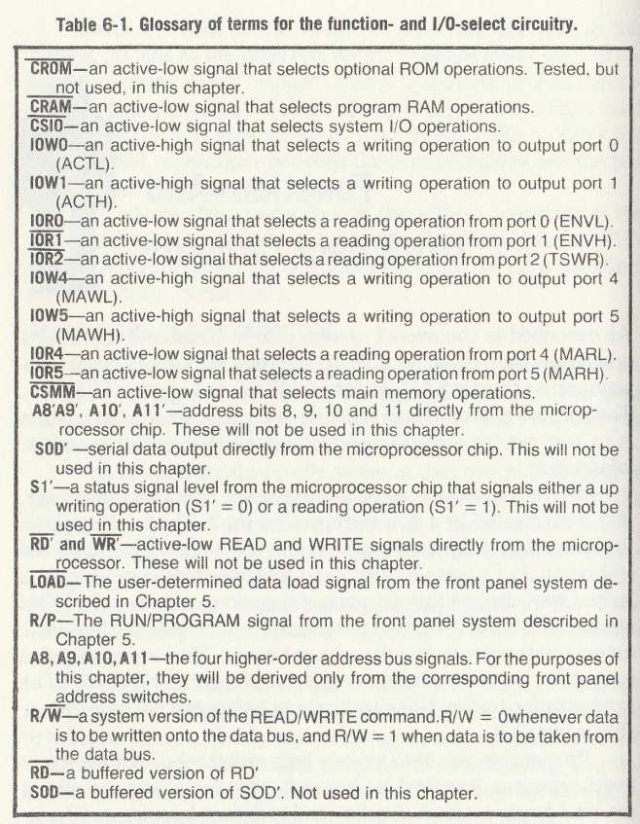
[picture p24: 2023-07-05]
build/6-function-select/images/table.6-1.png

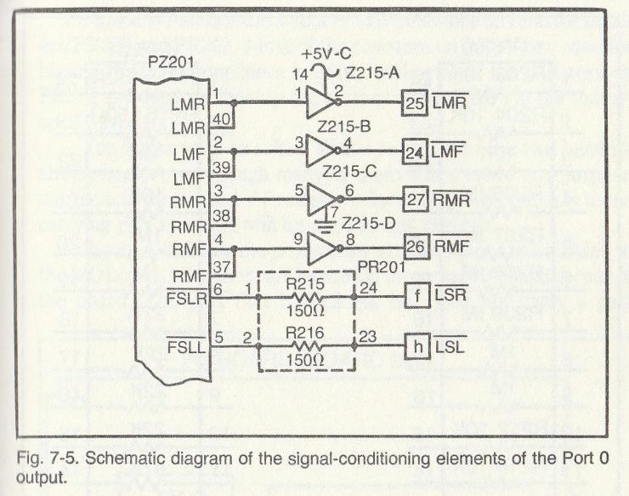
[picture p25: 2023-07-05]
build/7-ram-ports/images/fig.7-5.png

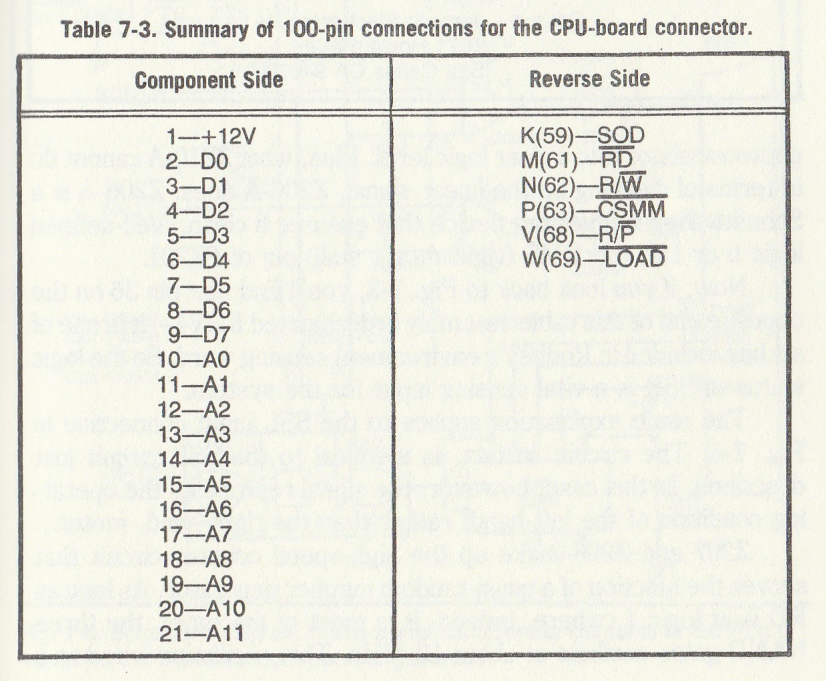
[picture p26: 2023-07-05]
build/7-ram-ports/images/table.7-3.png

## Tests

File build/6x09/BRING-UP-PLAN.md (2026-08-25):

# `6x09` Bring-Up Plan

This note turns the redesign packet into a practical bench sequence.

## Goal

Bring the `6809` Rodney variant up in the smallest safe steps:

1. prove reset and vector fetch
2. prove ROM execution
3. prove program RAM execution
4. prove `ACTL`
5. prove `MMA` / `MMD`
6. only then run the Beta seed

## Phase 1: Dead-Board Checks

Before inserting the CPU:

- verify `+5V` and `GND` continuity on all boards
- verify no rail shorts
- verify every IC has local decoupling
- verify reset pull-ups and interrupt inactive pulls
- verify ROM chip-select logic with static probing if possible

## Phase 2: Clock And Reset

With CPU installed:

- verify reset pulse width and idle level
- verify `E` and `Q` are present and stable
- verify no obvious bus contention on `D0-D7`

Success looks like:

- clean reset behavior
- repeatable bus activity after reset release

## Phase 3: ROM Fetch

The first software milestone is vector correctness.

Checks:

- ROM is visible at the top of memory
- reset vector points to `ROM_ENTRY`
- address bus shows top-of-memory fetch activity during reset/release

If this is wrong, stop here. Everything else depends on this.

## Phase 4: ROM Blink Test

Run the support ROM alone first.

Recommended first visible behavior:

- force the failure monitor path temporarily
- blink `ACTL` in a repeating pattern

Why:

- it proves vector fetch
- it proves instruction execution
- it proves output write path to `ACTL`

## Phase 5: RAM Handoff

Once ROM execution is stable:

- load a tiny RAM program at `$0100`
- confirm `VERIFY_RUNTIME` passes
- confirm ROM jumps into program RAM

At this stage the RAM payload should be as small as possible, ideally just:

- write a known pattern to `ACTL`
- loop forever

## Phase 6: Learned-Memory Path

Before running Beta, validate the indirect learned-memory path by hand:

1. write `MMA_L`
2. write `MMA_H`
3. write a byte through `MMD`
4. reselect the same address
5. read back through `MMD`

Only move on when this is solid.

## Phase 7: Beta Seed

Load [RODNEY-6809-BETA-SEED.asm](/home/cartheur/ame/aiventure/aiventure-github/cartheur/aiventure-rodney/build/6x09/RODNEY-6809-BETA-SEED.asm:1) at `$0100`.

Expected behavior:

- unknown `ENVL` states cause random low-nibble action selection
- learned byte is written back with confidence `1`
- repeated visits replay the stored action on `ACTL`

## Suggested Debug Strategy

If Beta fails, isolate in this order:

1. `READ_ENVL`
2. `SET_MMA_FROM_A`
3. `READ_MMD`
4. `WRITE_MMD`
5. `WRITE_ACTL`

That keeps us from blaming the learning loop for what is really just one broken primitive.

## After Beta Seed

Only after the seed loop is stable should the next steps begin:

- port `RODNEY-BETA-FULL`
- add explicit confidence update tests
- port first-pass Gamma
- consider `6309`-specific cleanup or acceleration

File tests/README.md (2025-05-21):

## Tests in this folder

A series of sanity checks and operational tests are contained in this folder. Note that textural references to hexidecimal numbers will have the `H` character as suffix.

### Check

_Analysis_

* `000 00`: At memory address `000H`, the data `00H` is loaded, which is a `NOP` (no operation) instruction.
* `001 C7`: At memory address `001H`, the data `C7H` is loaded, which is described as a command to return to address `000H` (labeled as `TEST`).
* `TEST`:: A label marking the address `000H`.
* `;RETURN TO TEST`: A comment indicating the purpose of the `C7` instruction, which is to return execution to the `TEST` label (address `000H`).

This code creates a simple loop where the microprocessor executes a `NOP` at `000H`, then at `001H` executes an instruction (`C7`) that returns it to `000H`, repeating indefinitely.

_Instructions_

Set up the panel address for `000H` and `LOAD` `00H`. This is a `NOP` (no operation) command. Then set the address to `001H` and `LOAD` data `C7` (a command that tells the system to return to address `000H`). You are telling the microprocessor to do nothing and then return to doing nothing again. Ideally, the system will buzz back and forth between these two commands at an r-f rate.

In a semi-assembly programming format used for most of the work remaining in this book, this simple program will look something like [this](/tests/check.asm).

Now set the `RUN/PROGRAM` switch to `RUN`. IF the `RESET` switch is still ON (as it should be at this point), nothing should happen. Return the system to `PROGRAM` after a few seconds and check the content of the program RAM. The data at 000H address should still be 00H and the data at `001H` should still be `C7H`. If it is not, something is wrong with the `RESET` wiring between the front panel and the microprocessor. Do not go any further with the testing until you are convinced the program RAM holds the 2-step program when switching the system between `RUN` and `PROGRAM`.

Check if things get scrambed.

### All ones

_Analysis_

* Address `000H` (`21 00 08`): The instruction `LXI` `H`,`PORT0` loads the register pair `H` and `L` with the address `0800H` (likely a port address labeled `PORT0`).
* Address `003H` (`3E FF`): The instruction `MVI` `A`,`FFH` loads the accumulator `A` with the value `FFH` (255 in decimal).
* Address `005H` (`77`): The instruction `MOV` `M`,`A` moves the content of the accumulator `A` to the memory location pointed to by the `H` and `L` registers (i.e., `PORT0`).
* Address `006H` (`C7`): The instruction `RST` `0` performs a reset by jumping to address `0000H`, effectively restarting the program.

This code appears to be written for an 8085 microprocessor, as the opcodes and mnemonics (`LXI`, `MVI`, `MOV`, `RST`) match the 8085 instruction set. The program initializes a port (`PORT0`) with the value `FFH` and then resets to the start.

_Instructions_

Things will probably get scrambled every time. If the program isn’t scrambled by some quirk of good fortune, try it again for several minutes. You cannot afford to hedge on this bet—programs must remain intact in the program RAM indefinitely. Let’s suppose the program isn’t getting scrambled and you are wondering what this fuss is all about. In this case, the system just might not be working right anyhow. Try [this](/tests/all-ones.asm) program. If you have been doing your homework on 8085 instruction sets and programming, you will see that this program loads all 1’s at the motor-control outputs (`Port 0`). The 3-digit numbers are address locations and the 2-digit numbers are hex data to be entered at the outputs. Since the first line of the program uses three different bytes of data, it figures they will occupy address locations `000H`, `001H` and `002H`. That’s why the second line begins with address `003H`. Load this little program but before `RUN`ing it, turn off the motor status lamps by addressing `Port 0` (`800H`) and `LOAD`ing data `00H`. Then start the program by first setting the system to RUN and then turning off the `RESET` switch. If the system is reading the program properly, the motor status lamps should turn on and remain on. They probably won’t stay on, but they should. If your system wasn’t scrambling the 2-step `TEST` program, but the `OTEST` program doesn’t run right, you know the system isn’t executing any commands. If that’s the case, you have to doublecheck a lot of circuitry, beginning with the program RAM tests in [Chapter 7](/build/7-ram-ports/README.md) and working all the way through the static tests in the previous section of this chapter.

### Conclusion

Maybe it isn’t so bad to have the 2-step `TEST` program fouling up after all. At least you know the microprocessor is executing commands. The commands are _garbage_, but at least that part of the system is working. The odds against the system running both of these dynamic test programs are tremendous.

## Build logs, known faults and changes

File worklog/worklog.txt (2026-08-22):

May 2023
The Rodney worklog: This is the worklog for the assembly of Heiserman’s 1979 robot.

What started as an opportunity to study the deepest aspects of the computer with a nostalgia-check on wire-wrapping, has evolved into a full-blown conspiracy-check: Why during this era did the big manufacturers (Intel, Motorola) advise strongly against self-programming machines when Turing (whom everyone in the business fawns-over) clearly stated in 1947: "What we want is a machine that can learn from experience"? Why the dichotomy? Grok says:

Intel’s advice was articulated in technical documentation like the Intel 8085 Microprocessor User’s Manual and related application notes, which emphasized writing clear, maintainable assembly code. While self-modifying code could theoretically be used on the 8085 for optimization (e.g., dynamically altering jump addresses), its risks—unpredictable execution, debugging difficulties, and reduced reliability—outweighed benefits in most cases, leading Intel to recommend against it.

03.07.2023
    1117: Although this project has been (more or less) around since 2019, only now am I bringing it into focus. I have assembled the work-area on the human-machine interface and the next step is to lightly glue the plastic LED bezels/mounts to this. Did a test with A0 and it seems well-enough.
05.07.2023
    1408: The stress-test of the glue hold did not go so well. But this is still a place to solve this problem. I went ahead and glued the remaining bezels with a bit of a twist to set the glue more evenly around the radius. Will give it 24 hours to see how it sets.
01.01.2024
    1613: After some slacktime, I resumed work the 22nd of December 2023 on the mounts for the two Vector boards (a decision not to use the smaller ones) and a hinge-based smaller board to hold the beginnings of the I/O components, pretty much just the 8226 bus transceivers. It took some time to get a design in-place and eight prototypes before four properly-sized mounts for the boards were correct. The hinge went well in a single go, as well as the bar support.
10.05.2024
    948: I have come to the realization that there is work to be done on my ideal-metal initiative here in 8-bit land. Any manifestations of learning should be visible at this level. I need to contemplate further.
17.05.2025
    2005: Completed the extended contemplation on this topic. Not easy as it is obfuscated and given how the world looks and operates, a pretty good probability was hidden for a reason. But not going to point fingers or assign shade, just investigate if relevant and what it looks like. Now we can move forward.
19.05.2025
    931: Created a Kanban board and will capture the work from Jan-2024, as a way to track progress and to create an inflection point.
    944: Addressed the self-programming context with Grok and added a new section for this feature so that I can keenly understand its implications and implementation.
    1043: Cleaned-up extraneous programs and files.
    1057: For the publication and referential purposes, added the example that I have been discussing with Grok.
    1216: Created the publication starting-point.
    1223: Refined the repo and getting a bit lost in task management.
    1334: Am insisting upon only half-day at the computer. After a break, will attend to the UI task.
    1709: Reviewing the what is required to progress with the Chapter 5 Task.
    1824: Made a drawing of the cable pattern toward the metal panel - PZ202, PZ203, and PZ204 in the book.
20.05.2025
    948: Resuming where I left-off yesterday.
    1146: Wasted two hours working on a "8085 trainer" circuit design, based on some late-night thoughts. While AI seems helpful, it's total shit since it cannot close the loop.
    1216: Created the .md page for the steps thusfar for 5.
    1253: Added future chapter work and a means to present results clearly and cleanly.
    1301: Made a "working version" of the wiring figure with a grey background as the white was just too bright.
    1531: Amended the panel drawing and still have to reconcile the +5v as it might be errantly in the diagram.
    1612: Gathered the LED data and sheets, created a table to align forward-voltage.
    1644: Found more stuff that needed refinement and I am getting to know this system very well again!
    1702: Went into the resistor banks and there are some choices on using DIP headers - either two 40s and one 24 or four 24s. Next question is the next board should be a Vector-board, right? But this is moving toward OPS. OK.
    1706: Whew! What a day: Now ready to take a walking break.
    1805: Done for the day.
21.05.2025
    1100: Seems a better and more robust approach to continue with the drawing-mapping of boards 100, 200, and 300 whilst attending to the actual prototypical structure of the robot. As it stands, the thing I made for the baords is a great workstation, but production, I'm skeptical. And besides - no wheels/motors! I'm contemplating to assemble what bits I may have and 3D print/design the circular bottom and card rack using pins and glue to set, as was successful with huggable. Wheels/tires and balance I need to design.
    1435: Given the crucial nature of needing a concrete design, am going to set a bassic structure in-place.
    1727: Have gone through all the elements of design I can think-of now and am at the end where I see to print everything.
    1738: Finished for the day.
23.05.2025
    946: Arrived at a design late on the 21st for dot based on the beautiful work in here. Will spend a bit of time seeing how it shakes.
07.08.2025
    1200: Reviewing the 2114 setup, image 0701.
22.08.2026
    1540: Considered the MTK-85 single-board 8085 trainer as a possible parallel development track. Decided not to pursue it and to keep the repo centered on the Rodney-native Vector 8801-6 wire-wrap implementation.

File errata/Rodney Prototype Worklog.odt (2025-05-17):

The Rodney (re) prototype – Working log

An opportunity to study the deepest aspects of the computer with a nostalgia-check on wire-wrapping. What more fun could be had? This is the worklog for the assembly of Heiserman’s robot.

3 July 2023

1117: Although this project has been (more or less) around since 2019, only now am I bringing it into focus. I have assembled the work-area on the human-machine interface and the next step is to lightly glue the plastic LED bezels/mounts to this. Did a test with A0 and it seems well-enough.

5 July 2023

1408: The stress-test of the glue hold did not go so well. But this is still a place to solve this problem. I went ahead and glued the remaining bezels with a bit of a twist to set the glue more evenly around the radius. Will give it 24 hours to see how it sets.

1 January 2024

1613: After some slacktime, I resumed work the 22nd of December 2023 on the mounts for the two Vector boards (a decision not to use the smaller ones) and a hinge-based smaller board to hold the beginnings of the I/O components, pretty much just the 8226 bus transceivers. It took some time to get a design in-place and eight prototypes before four properly-sized mounts for the boards were correct. The hinge went well in a single go, as well as the bar support.

1617: Now I want to formally prepare the full BoM and align as I have a pending Mouser order that needs to be submitted tomorrow.

1630: Formalizing this document will take some time. Let me pull the parts, mostly the resistors and capacitors, and check that the list is complete.

1817: Just finished the BoM for the M6x09-I-SBC, as a template for how to do such in the future. I would really like to have each board fully assembled by machine. Now to pull the parts and see what Rodney maybe missing.

1852: Reorganized the repository. Now is a bit clearer and more pragmatic. Will use the tables and the parts list sheet to know if I have all the bits. The big question is where did I get the DIP24-600?

2110: Completed the BoM based on the tables from the book. Added a 32-pin PROM and the appropriate wirewrap socket for the additional storage via cartridge or tape. Let’s see what shakes. The list is ready and will cross-check tomorrow before sending the order.

3 January 2024

1603: As, essentially, this project is a historical revisitation – not unlike the intent of spiritualists of the 1890s – with an emphasis on embodiment (very much so) I have elected to include the oldest discovered version of 86-DOS (predecessor of MS-DOS) that was an outgrowth of the 8-bit CP/M but targeted the new 16-bit 8086 in this GitHub repository. The idea is that software is very much a part of this journey and although the i8085 is capable clearly of CP/M, given its unique UI, this will only be explored in terms of the program monitor that I have planned to be burned into the ROM, once I place it. I am contemplating a change in design to include it based on the design principles I have codified for the 6x09-II-SBC project.

10 May 2024

948: I have come to the realization that there is work to be done on my ideal-metal initiative here in 8-bit land.

17 May 2025

2005: This project is back to active status.

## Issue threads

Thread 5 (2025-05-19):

Vector board supports

cartheur, 2025-05-19:
On the mounts for the two Vector boards (a decision not to use the smaller ones) and a hinge-based smaller board to hold the beginnings of the I/O components, pretty much just the 8226 bus transceivers. It took some time to get a design in-place and eight prototypes before four properly-sized mounts for the boards were correct. The hinge went well in a single go, as well as the bar support.

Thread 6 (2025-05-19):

Wheeled platform support

cartheur, 2025-05-19:
Given that we will use the crazy four-wheel platform I got from someone in 2022, we need to create and 3D print a set of platforms to allow the UI and board-stack to attach thusly.

Why? A game is no longer sufficient for totality.

cartheur, 2025-05-21:
Subsequent to the work on #22 .

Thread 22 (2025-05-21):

Exact chassis design including motor, wheels, and battery choices

cartheur, 2025-05-21:
Need an exact chassis design including motor, wheels, and battery choices since ad-hoc will get me into trouble.

cartheur, 2025-05-21:
The details are [here](https://github.com/cartheur/aiventure-rodney/blob/main/design/README.md).

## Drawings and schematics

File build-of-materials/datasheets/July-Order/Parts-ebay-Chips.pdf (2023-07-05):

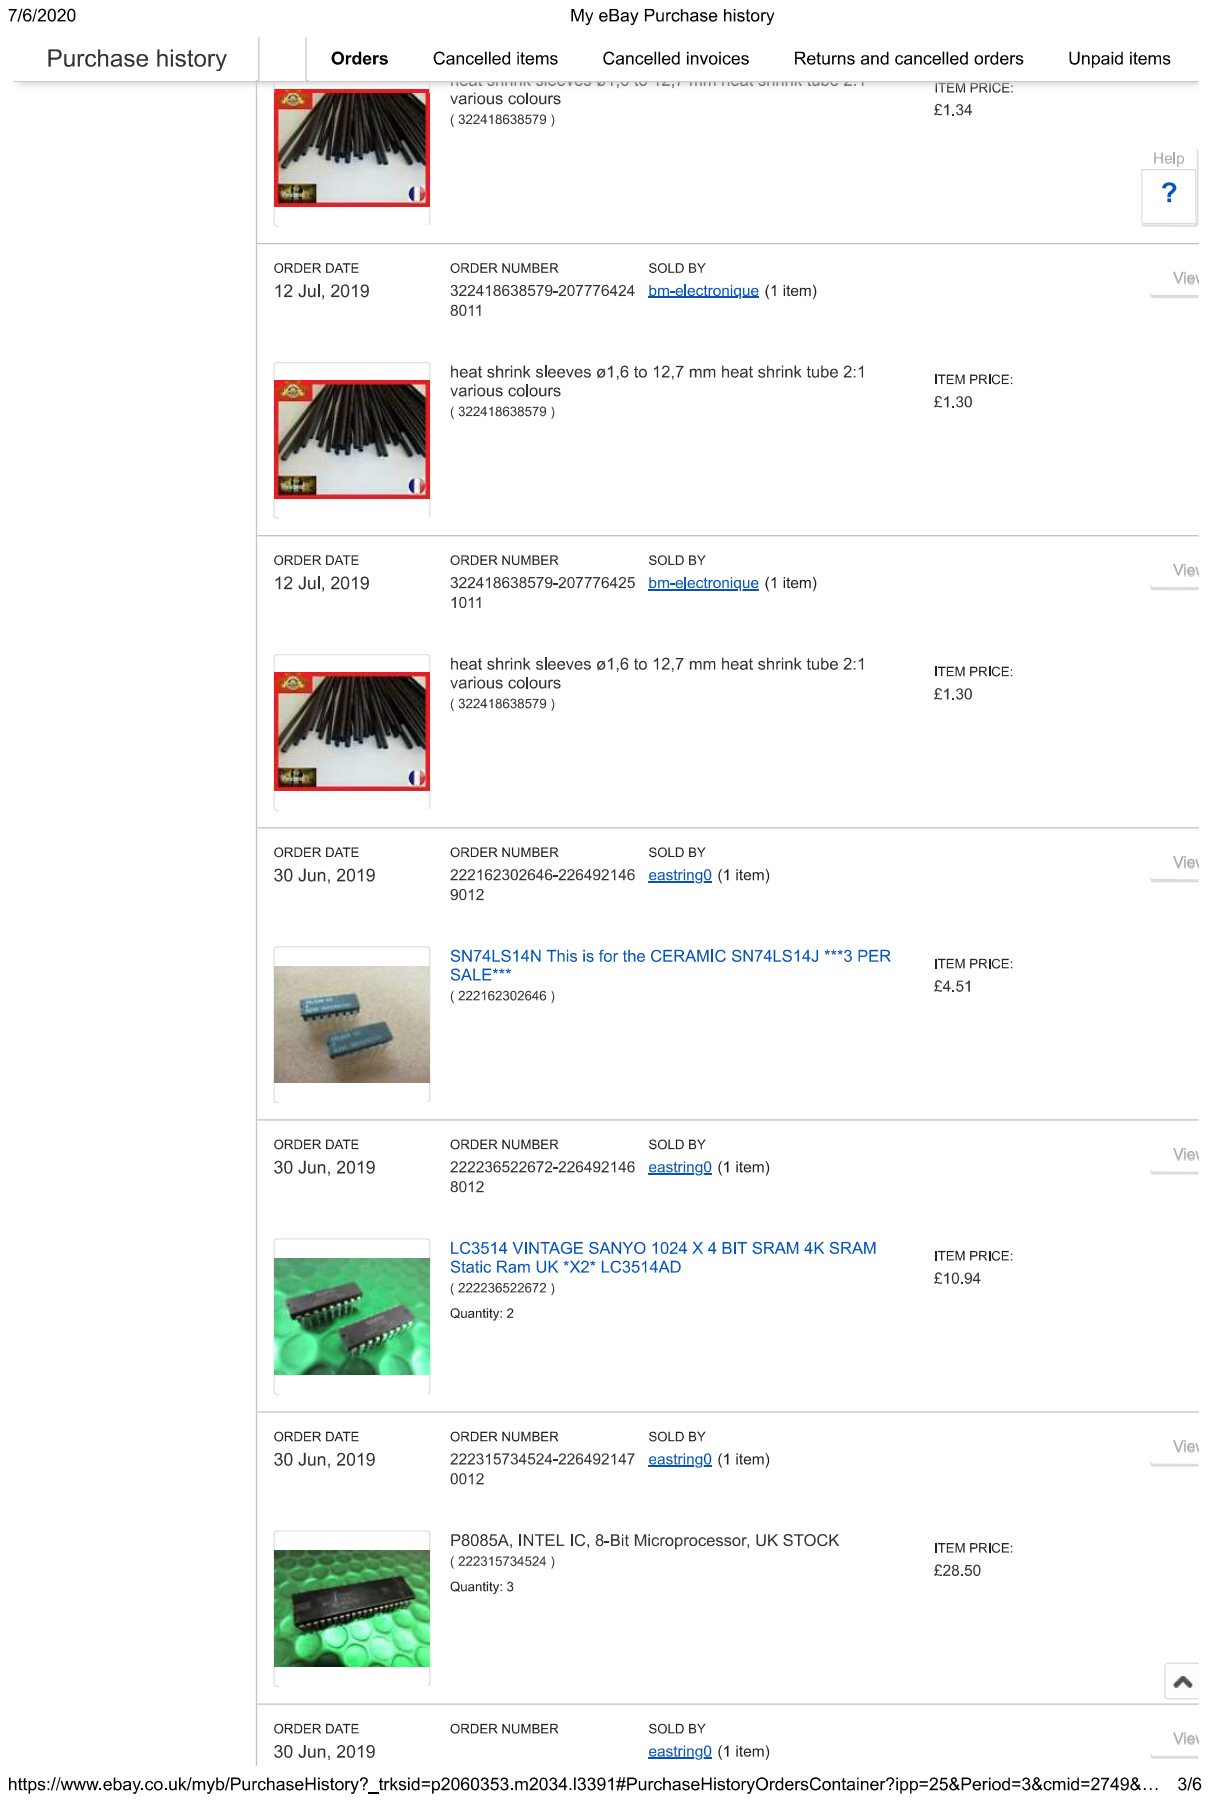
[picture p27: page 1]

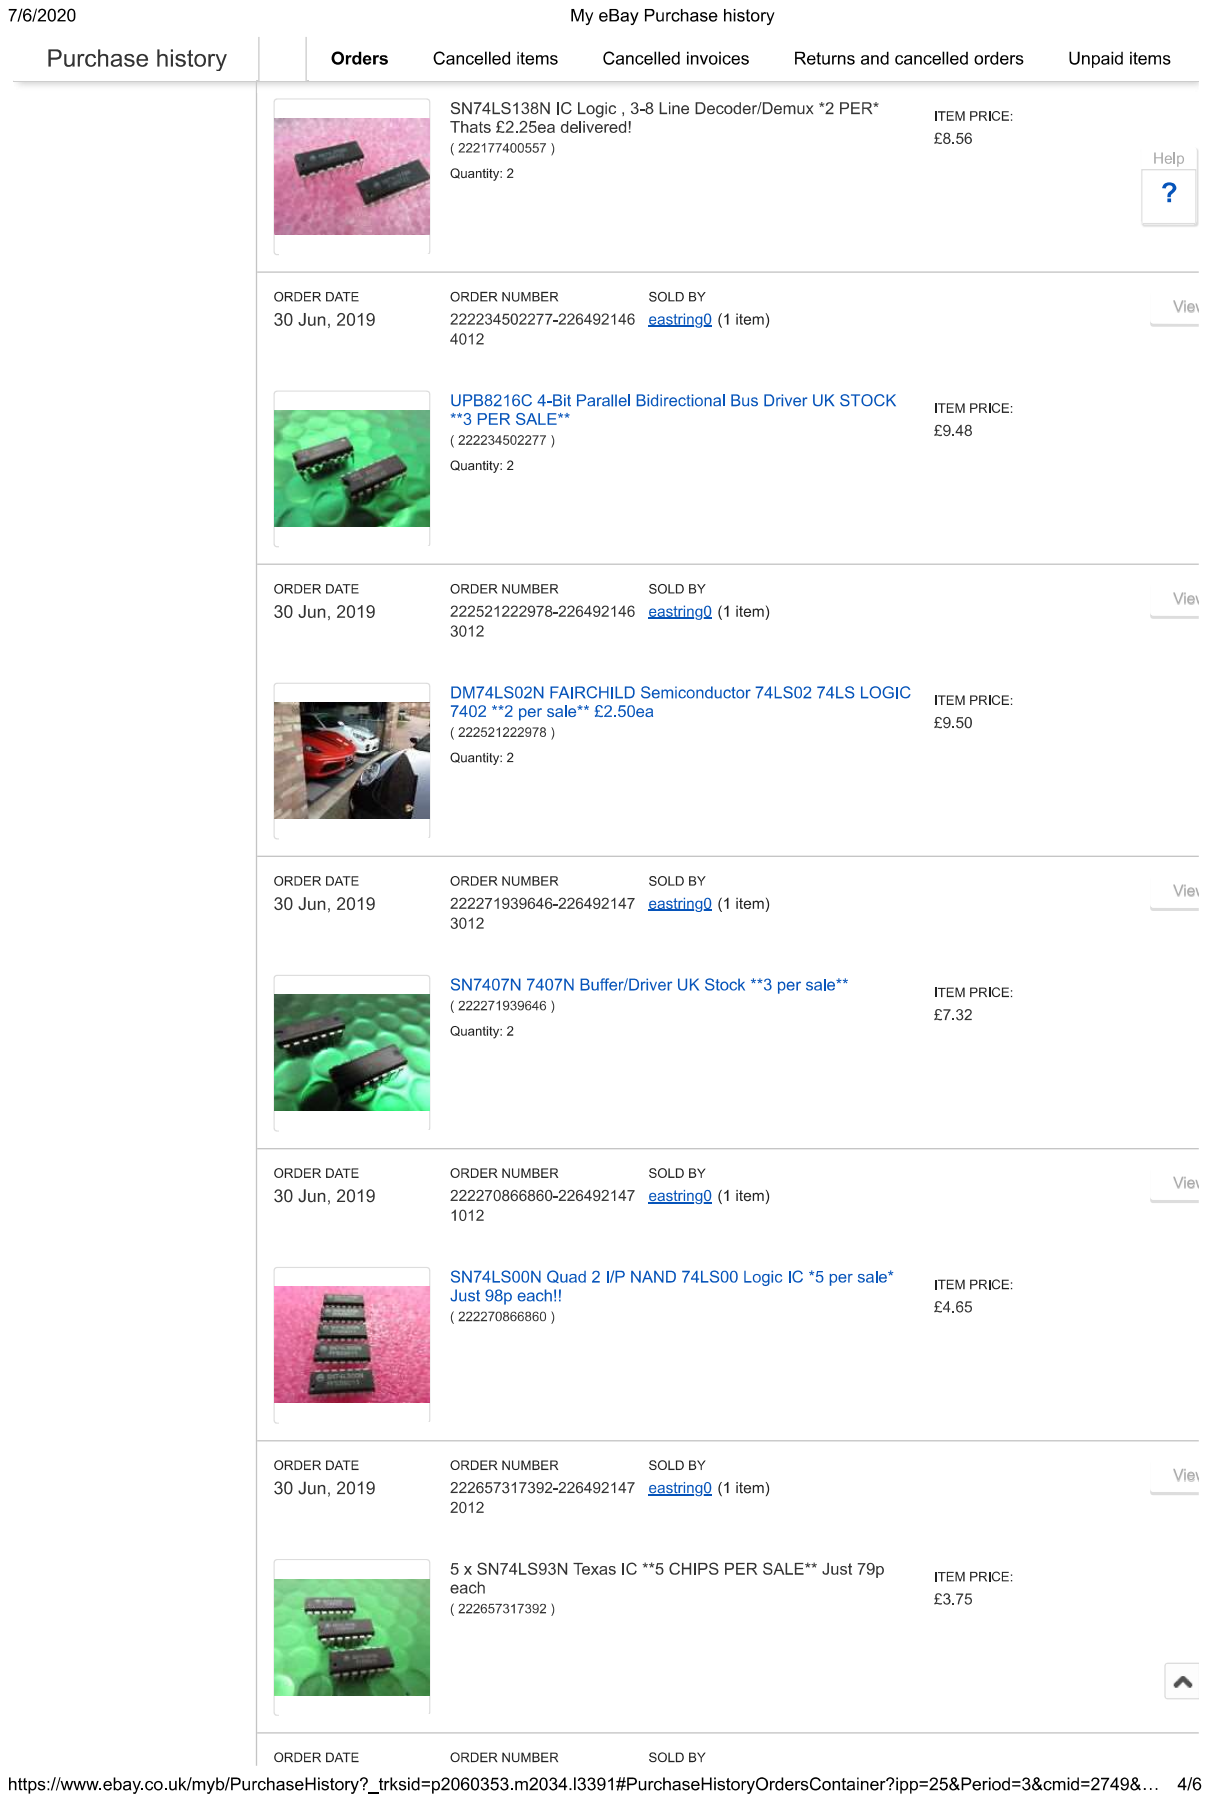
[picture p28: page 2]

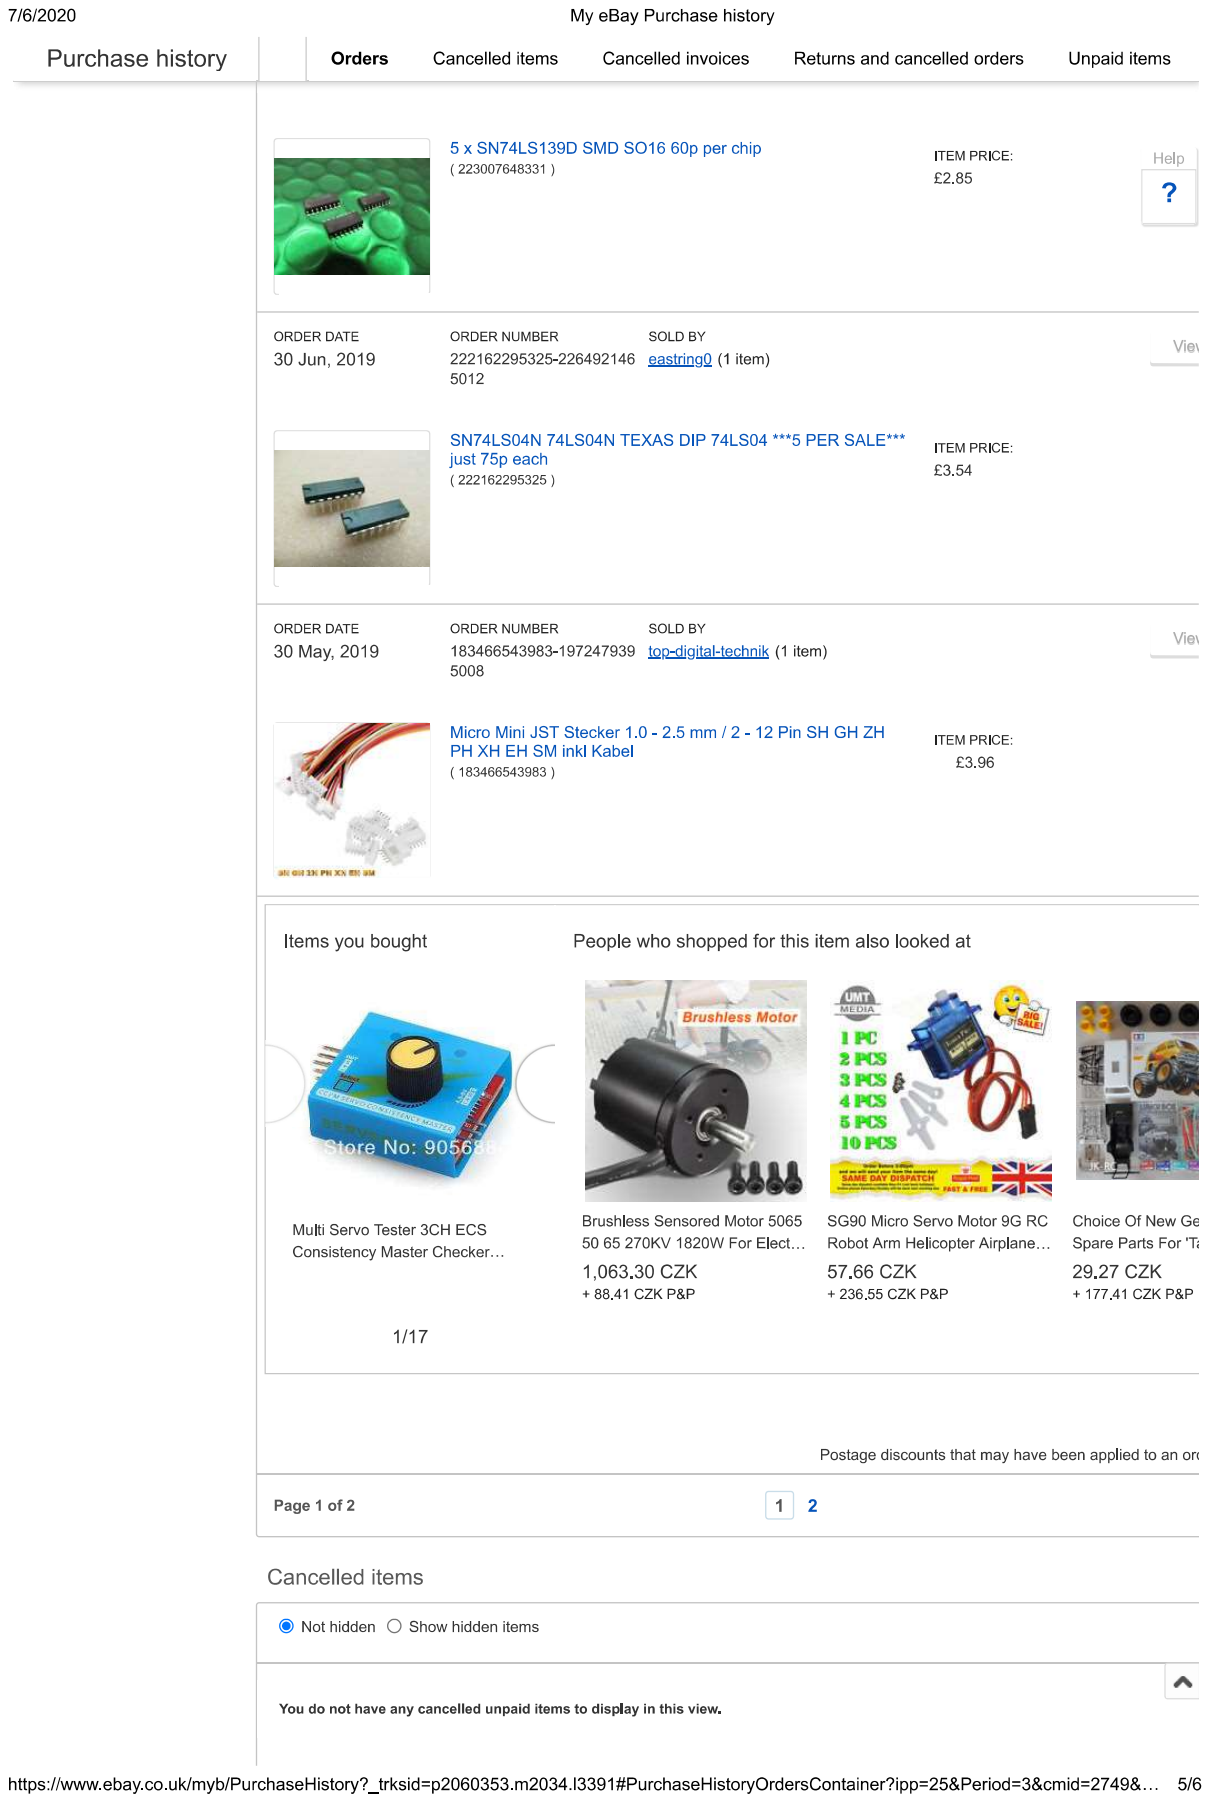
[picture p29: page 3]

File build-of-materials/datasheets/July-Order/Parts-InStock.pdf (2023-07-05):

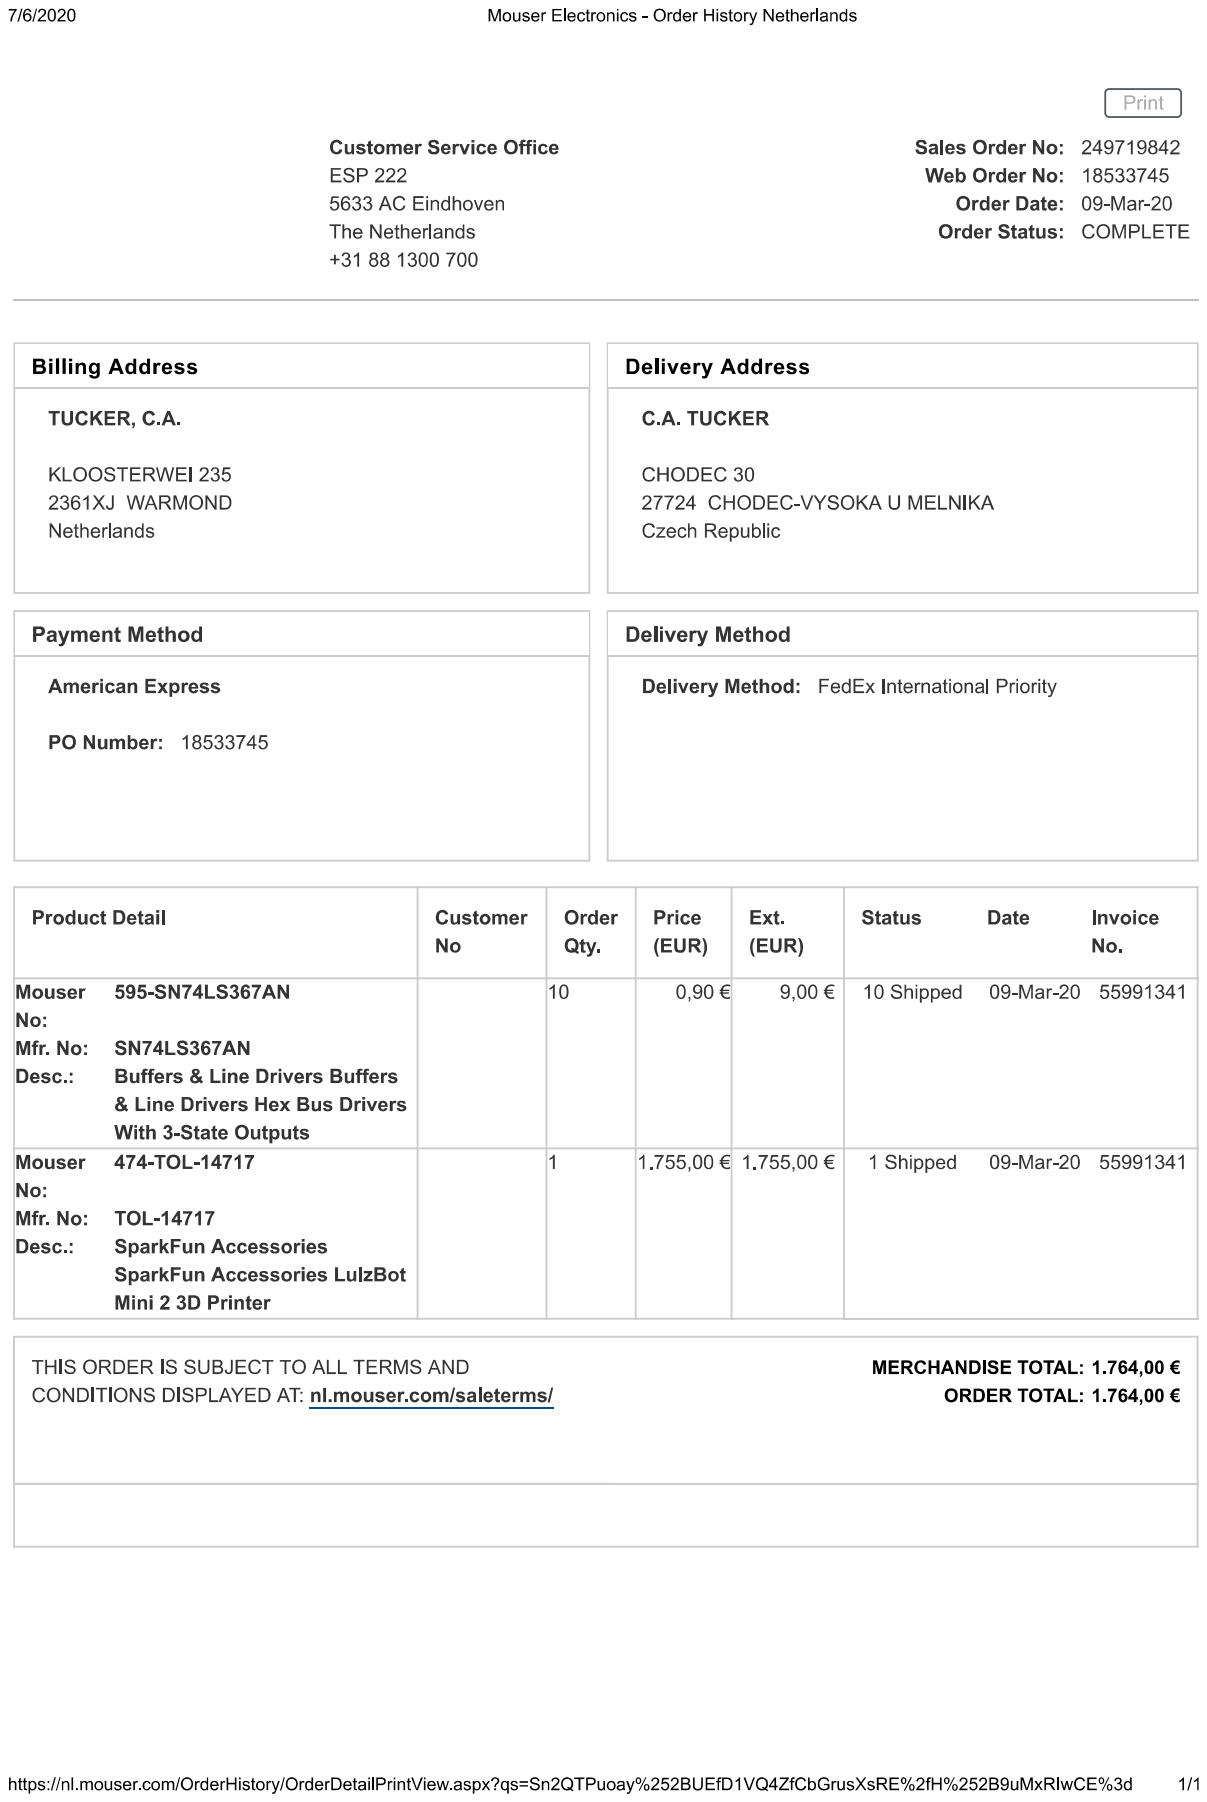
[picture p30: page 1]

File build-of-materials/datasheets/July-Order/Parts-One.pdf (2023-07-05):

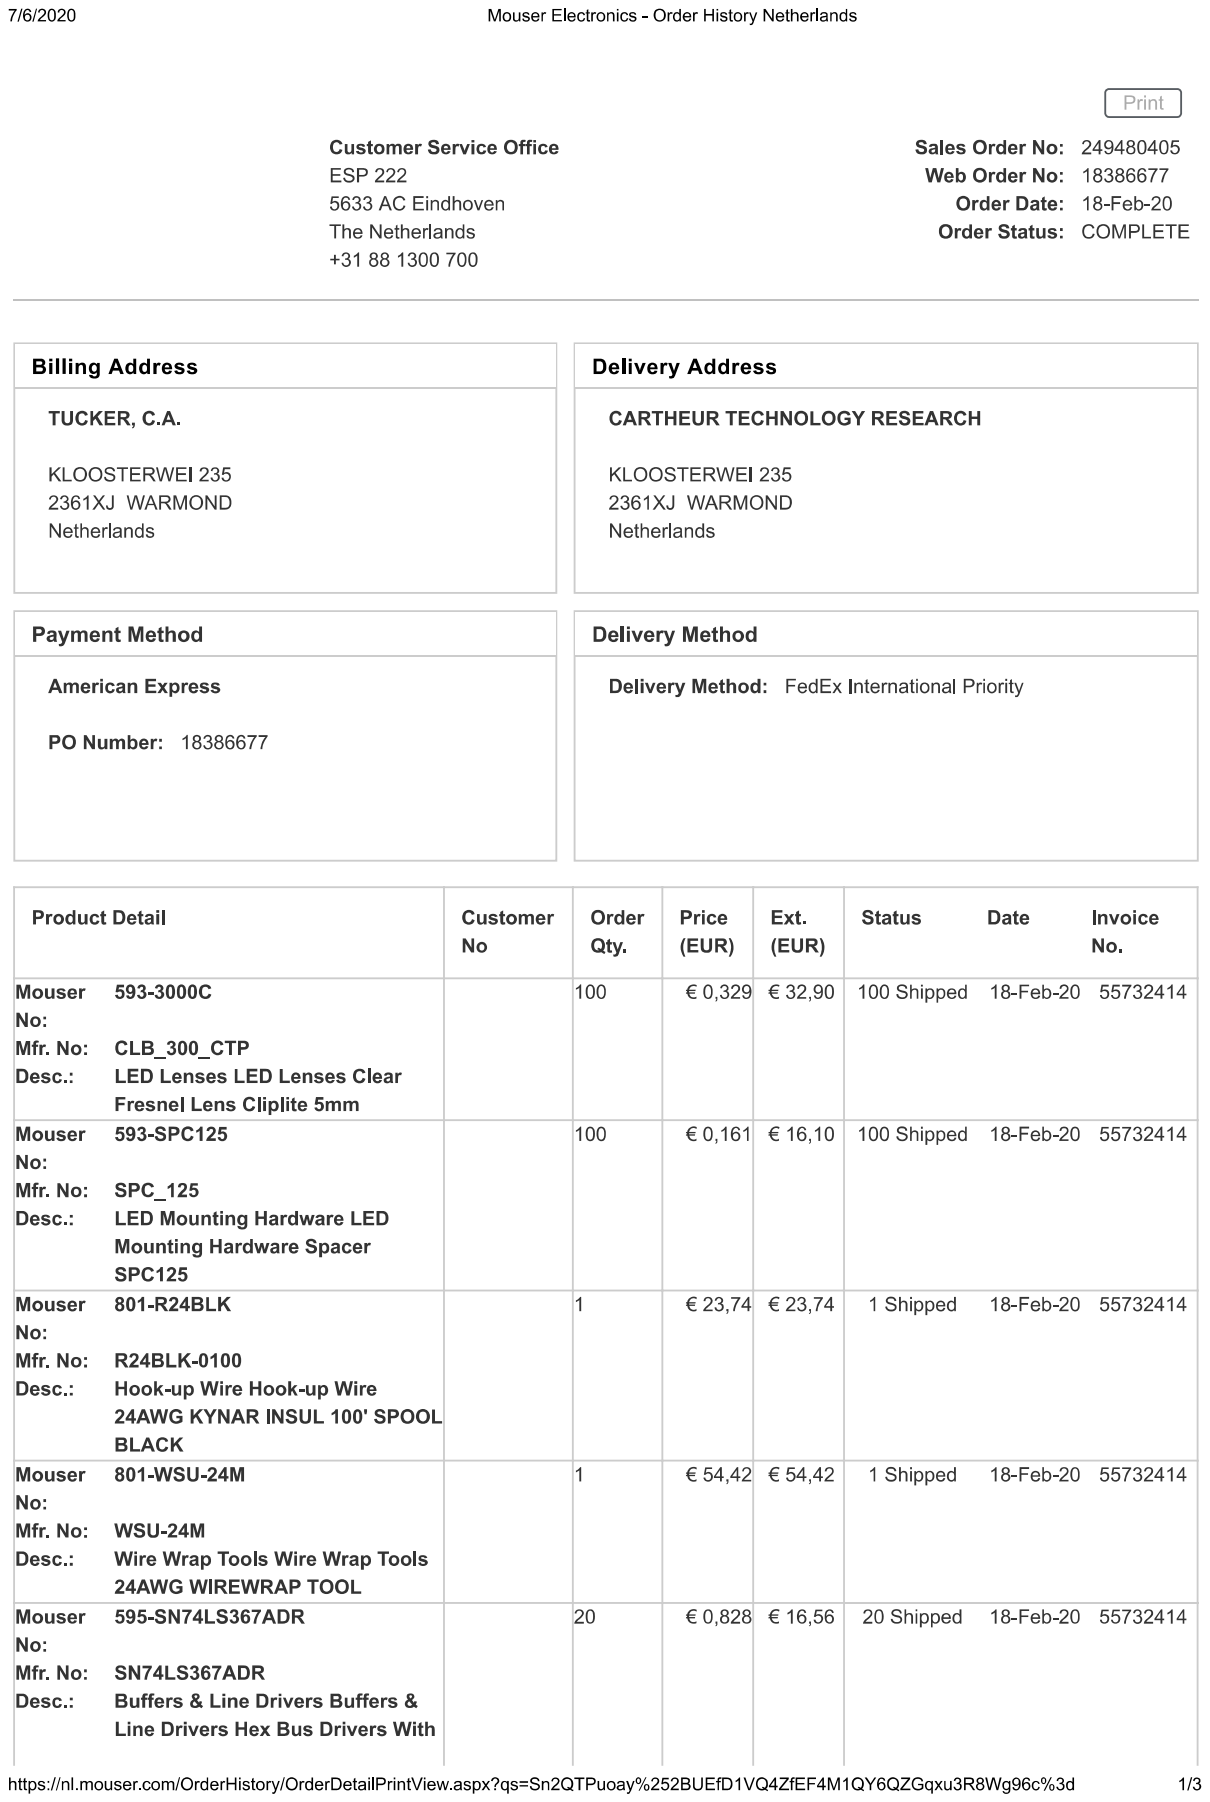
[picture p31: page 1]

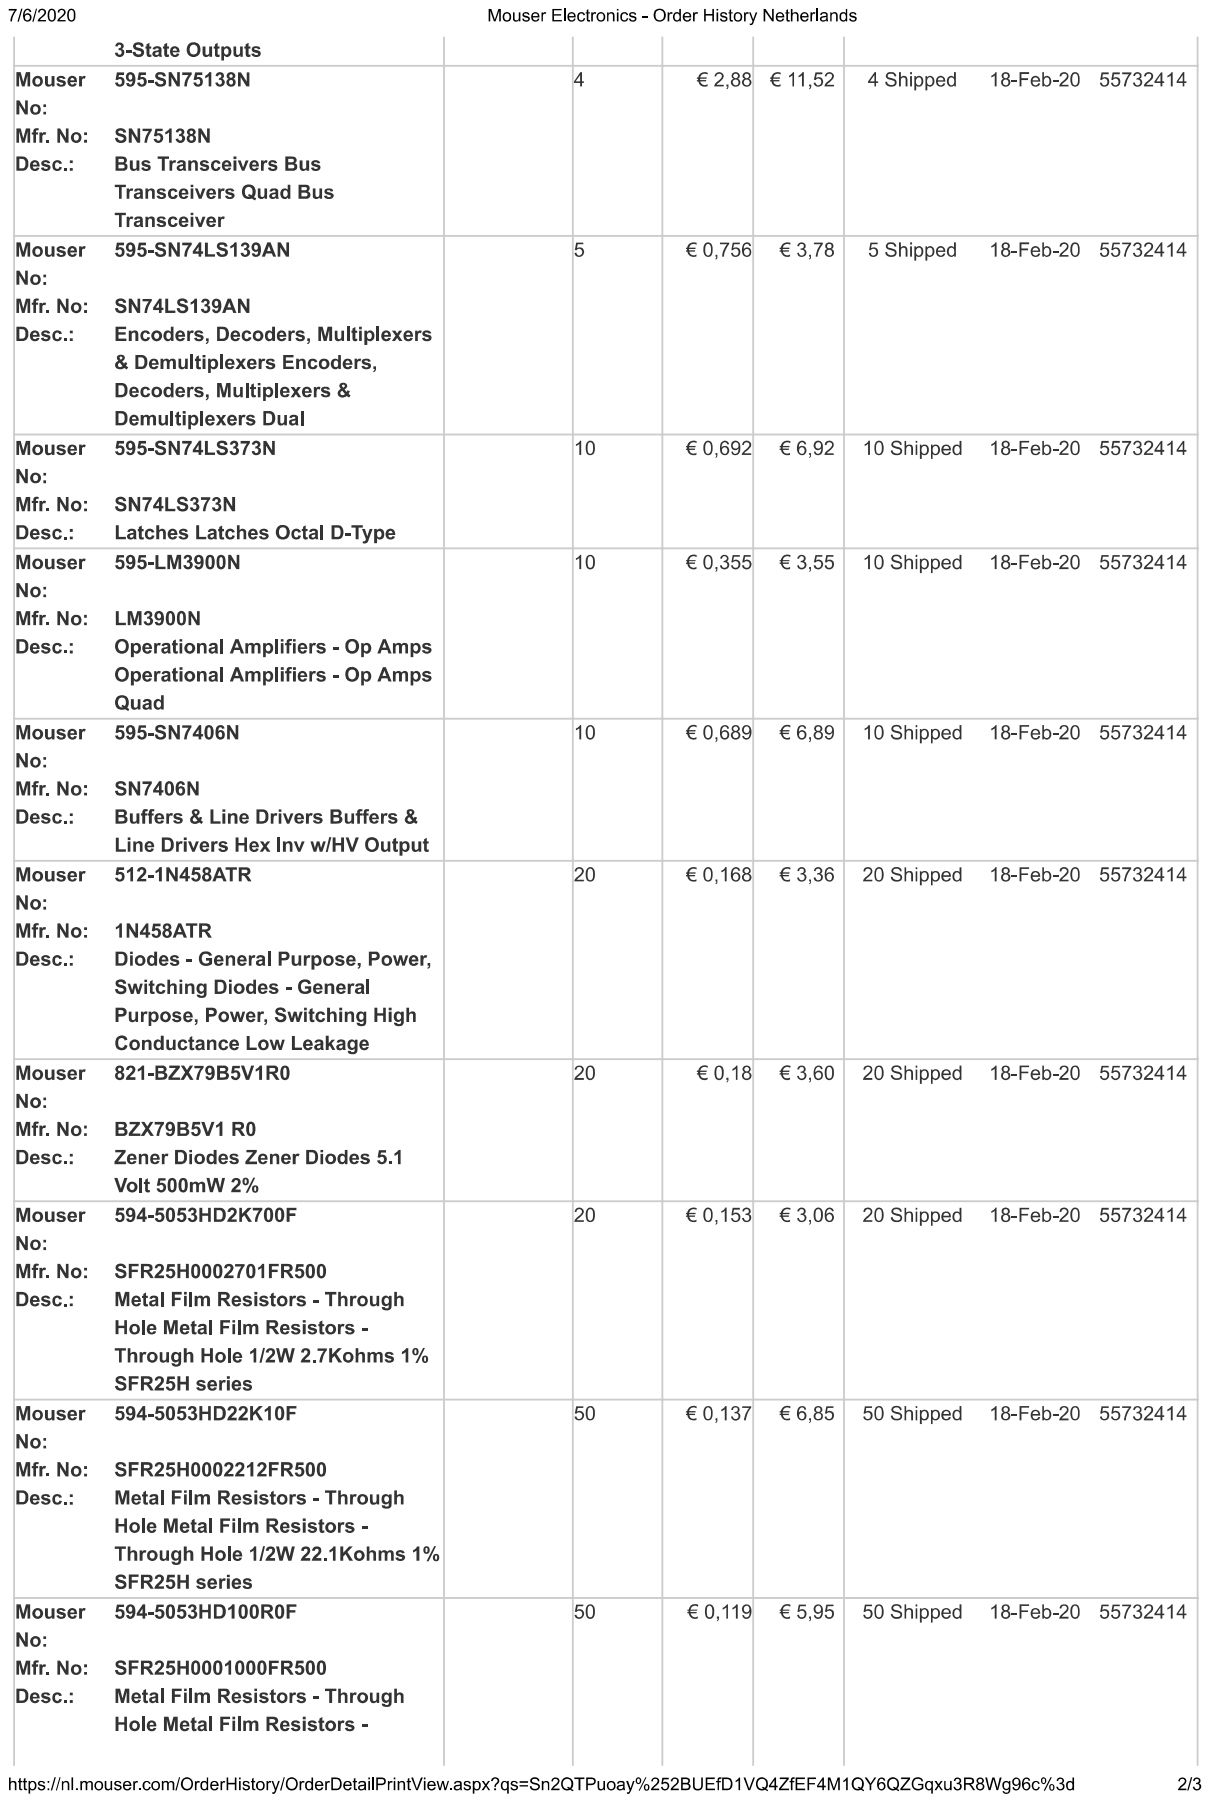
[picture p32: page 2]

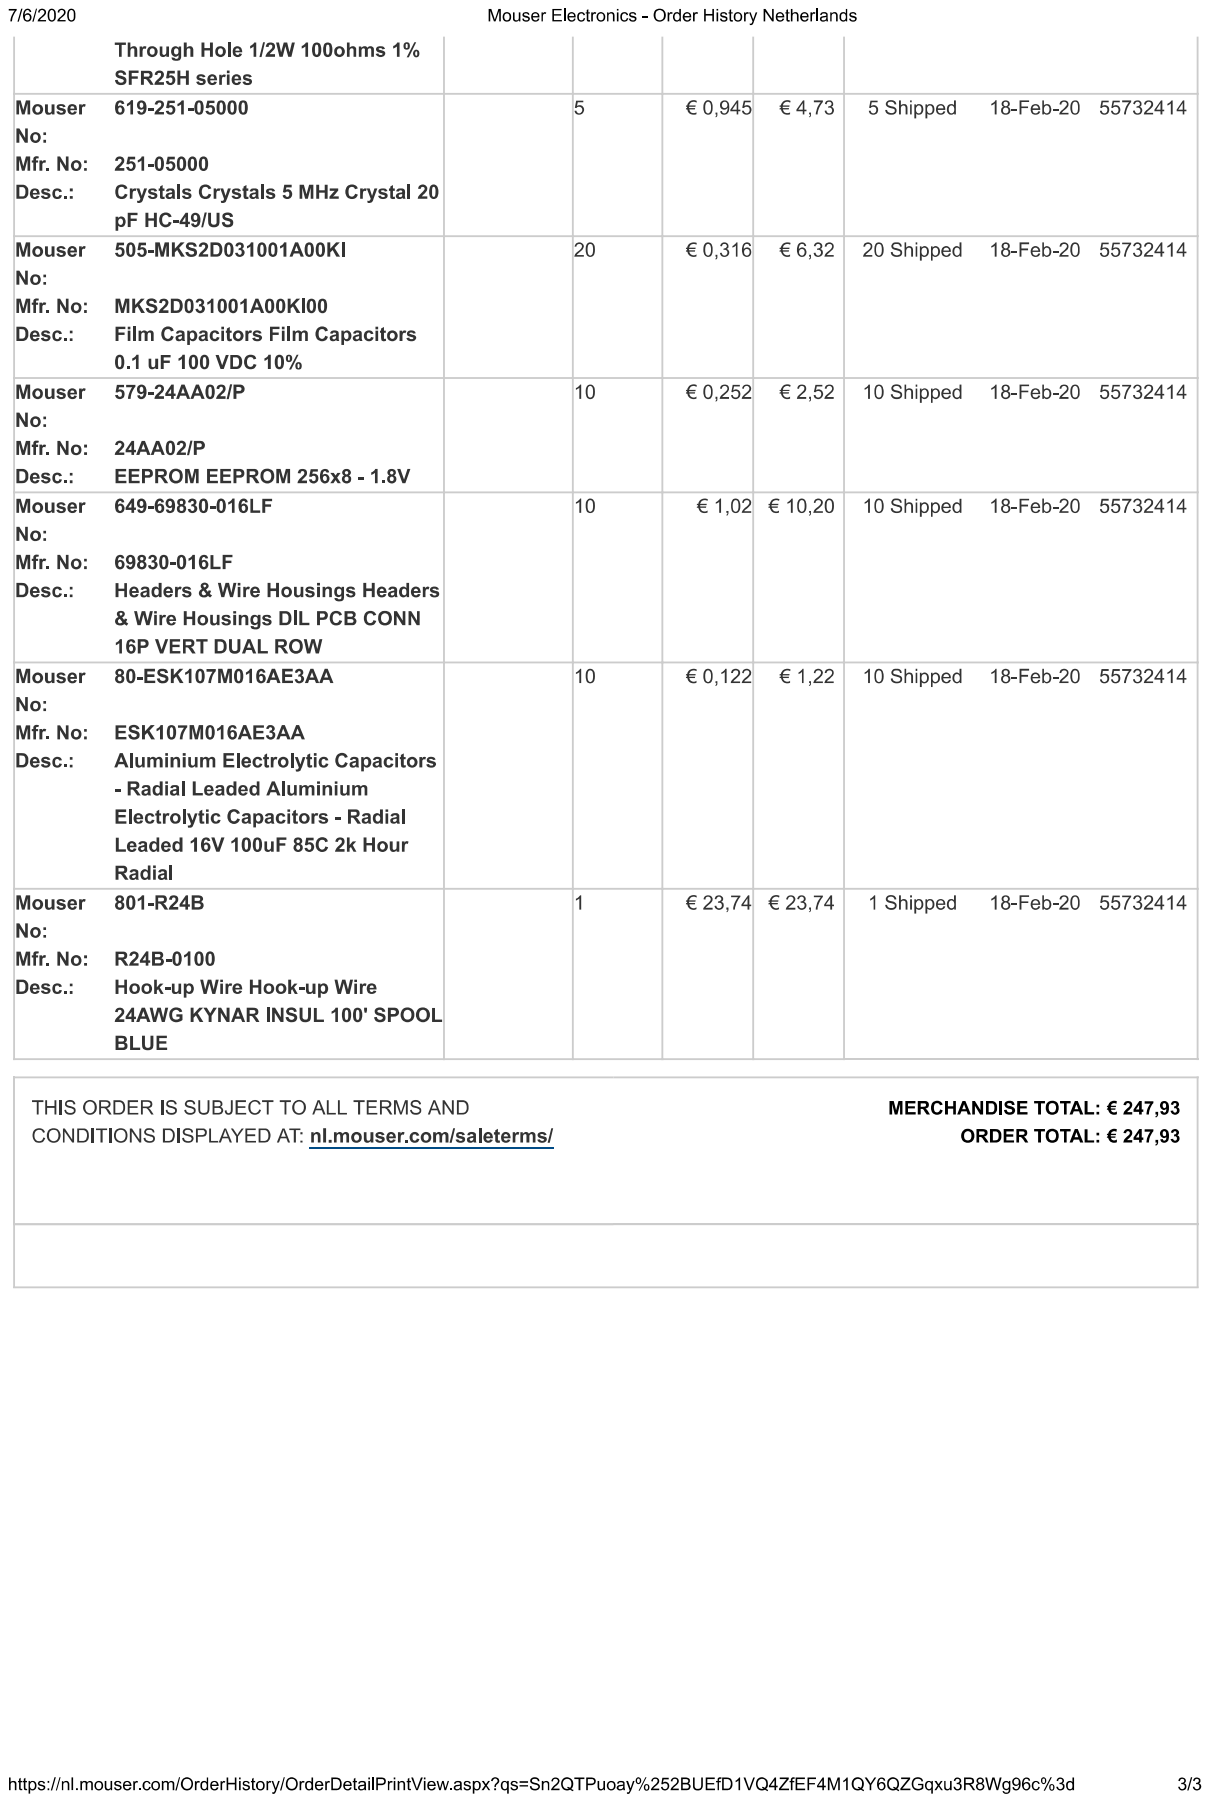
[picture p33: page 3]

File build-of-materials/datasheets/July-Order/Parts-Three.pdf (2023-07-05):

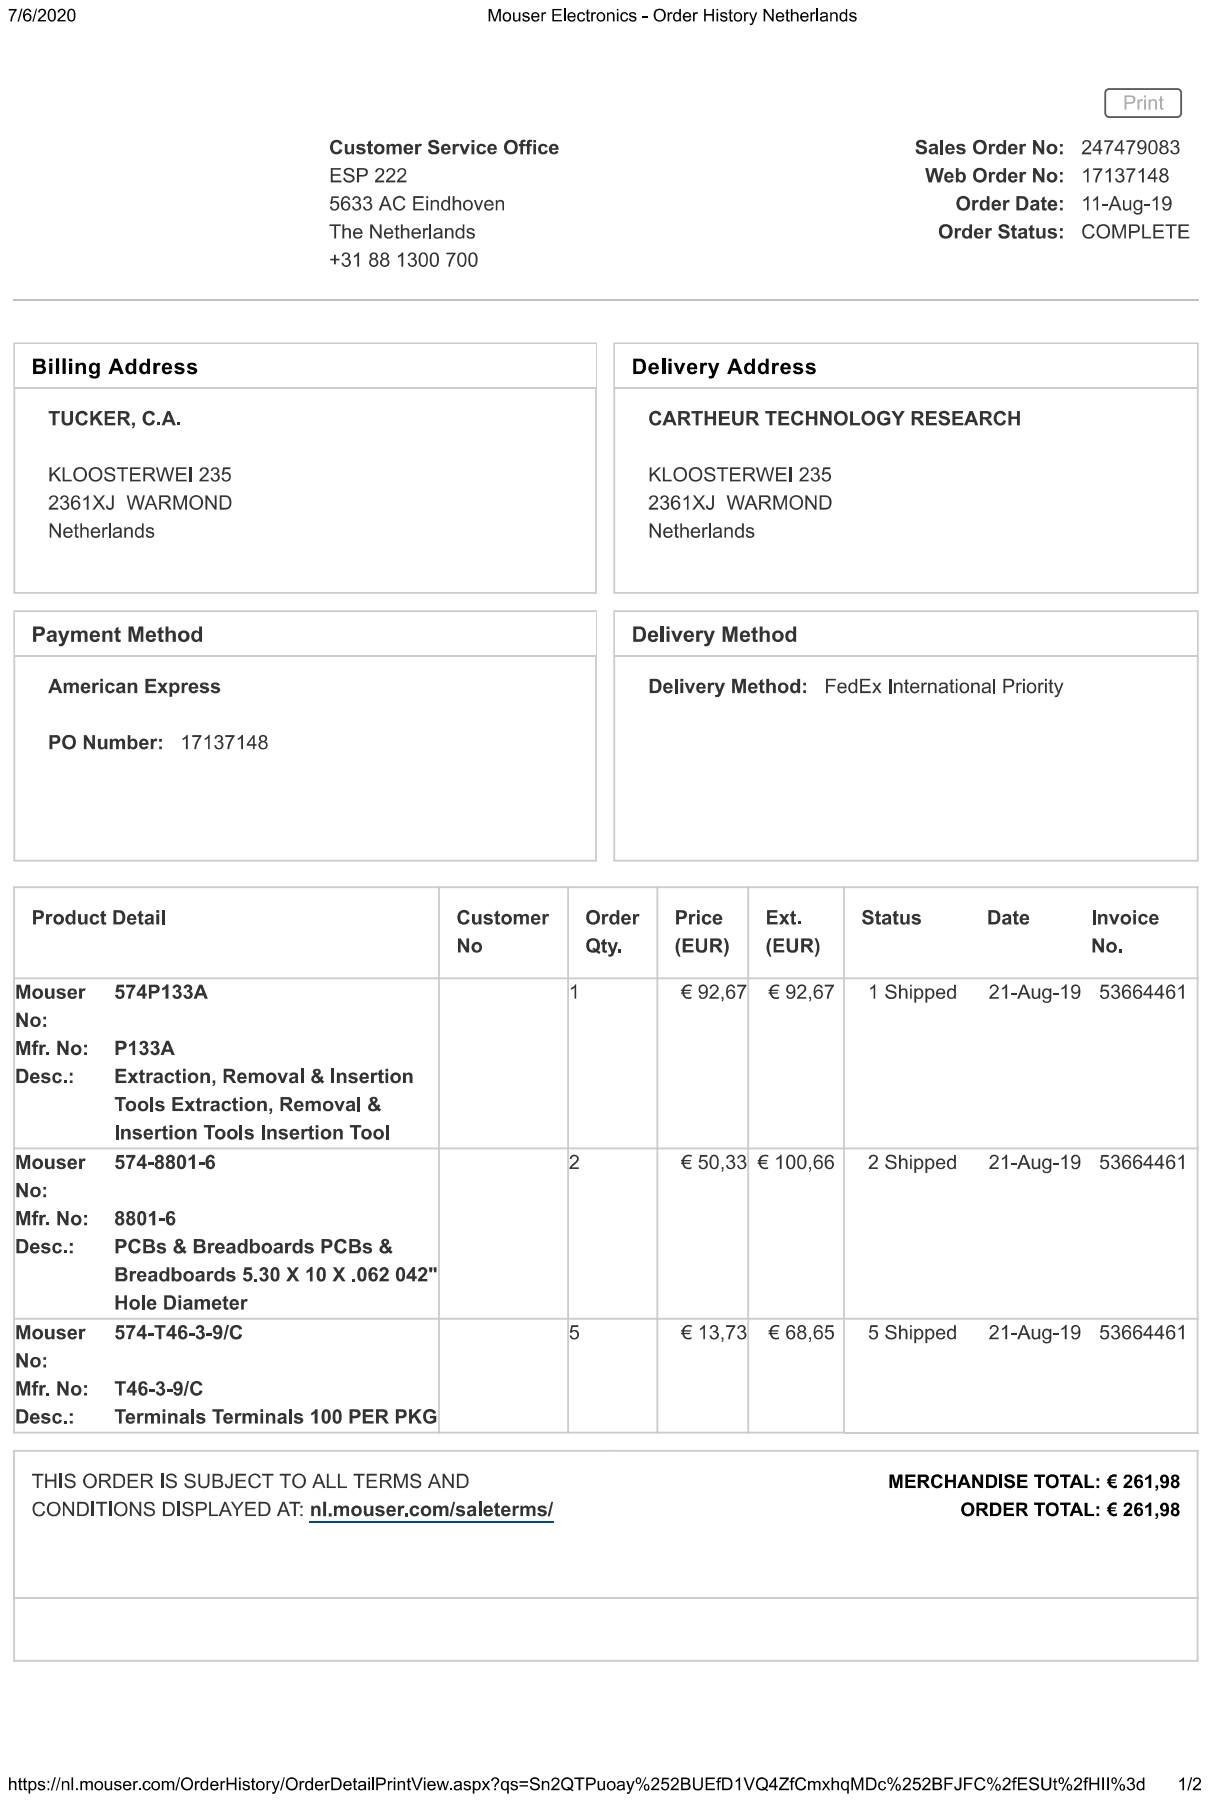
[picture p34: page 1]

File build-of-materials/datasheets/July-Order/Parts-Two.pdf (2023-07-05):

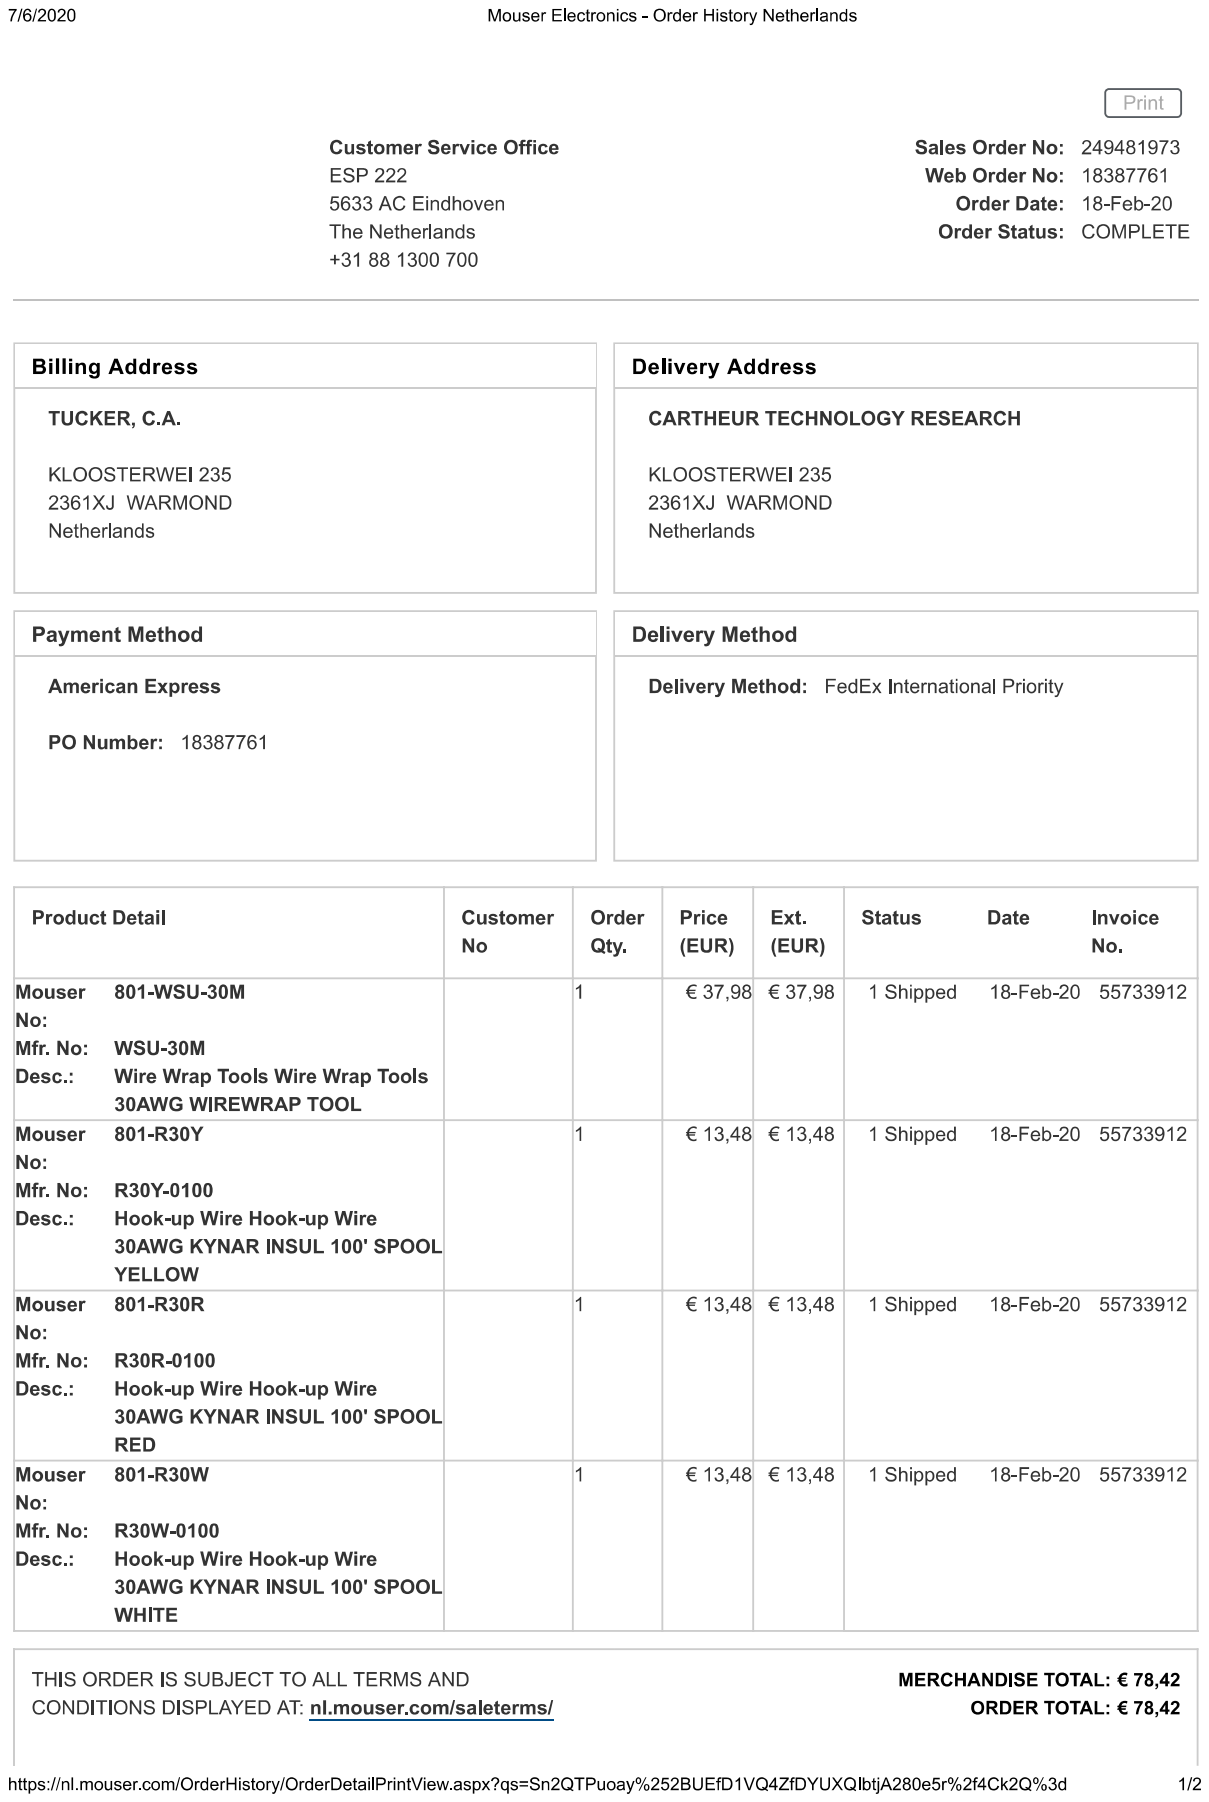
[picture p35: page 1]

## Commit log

2023-12-22 Add design files
    [board-holder.FCStd, vector-support.FCStd]
2023-12-22 Remove old designs
    [board-holder.FCStd, vector-support.FCStd]
2023-12-22 Add board supports
    [2-vector-support-lf.FCStd, 2-vector-support-lf.stl, 2-vector-support-rt.FCStd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]
2023-12-22 Adjust hole spread
    [2-vector-support-lf.FCStd, 2-vector-support-lf.stl, 2-vector-support-rt.FCStd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]
2023-12-22 Adjust board placement pegs
    [2-vector-support-lf.FCStd, 2-vector-support-lf.stl, 2-vector-support-rt.FCStd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]
2023-12-24 Revised vector mount
    [3-vector-support-rt.FCStd, 3-vector-support-rt.stl]
2023-12-25 Left side model
    [4-vector-support-lf.FCStd, 4-vector-support-lf.stl]
2023-12-25 Add draft hinge set
    [1-folding-hinge-pin.FCStd, 1-folding-hinge-pin.stl, 1-folding-hinge-rear-bar.FCStd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]
2023-12-25 Name component
    [1-folding-hinge.FCStd]
2023-12-26 Remove prototype files
    [2-vector-support-lf.FCStd, 2-vector-support-lf.stl, 2-vector-support-rt.FCStd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]
2023-12-26 Add wireboard mounting
    [1-folding-hinge-rear-bar.FCStd, 1-folding-hinge-rear-bar.stl]
2023-12-26 Shorten due to strange area indication on printer
    [2-folding-hinge-rear-bar.FCStd, 2-folding-hinge-rear-bar.stl]
2023-12-28 Rename files to those in production
    [vector-support-left.FCStd, vector-support-left.stl, vector-support-right.FCStd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]
2024-01-01 Add BoM
    [BOM_Rodney.csv]
2024-01-01 Add transitional bom
    [Parts-List.xlsx]
2024-01-01 Reorient repository
    [1-folding-hinge-pin.FCStd, 1-folding-hinge-pin.stl, 1-folding-hinge-rear-bar.FCStd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]
2024-01-01 Complete BoM
    [BOM_Rodney.csv]
2024-05-20 Add model
    [wrap-id-16.FCStd]
2024-05-20 Add wirewrap speciifications
2024-05-20 Update model
    [wrap-id-16.FCStd]
2024-10-10 Add 4-bit interface
    [4-bit-switcher.FCStd, 4-bit-switcher.stl]
2024-10-10 Add printer file
2025-05-19 Clean-up and centralize
    [4-bit-switcher.FCStd, 4-bit-switcher.stl, wrap-id-16.FCStd]
2025-05-19 Add UI wiring design pattern
2025-05-20 Add trainer start
    [8085_trainer.kicad_pcb, 8085_trainer.kicad_sch]
2025-05-20 Add sum schematic tries
    [8085_trainer.kicad_sch]
2025-05-20 Add connection-wire detail
2025-05-20 Add LED table
2025-05-20 Tally resistor banks
2025-05-21 Add 3D print details
2025-05-21 Add printy
2025-05-21 Add filament analysis
2026-08-22 Indexed ocr
    [ocr.tsv]
2026-08-22 Document Rodney 3-board build sockets and footprints
    [RODNEY-3BOARD-SINGLE-SHEET-BOM.csv]
2026-08-22 Record selected Alliance SRAM for Rodney build
    [RODNEY-3BOARD-SINGLE-SHEET-BOM.csv]
2026-08-22 Record exact Alliance 62256 SRAM selection
    [RODNEY-3BOARD-SINGLE-SHEET-BOM.csv]
2026-08-22 Standardize Rodney build on 74LS logic
    [RODNEY-3BOARD-SINGLE-SHEET-BOM.csv]
2026-08-22 Document Rodney switch and power selections
    [RODNEY-3BOARD-SINGLE-SHEET-BOM.csv]
2026-08-22 Document recommended Rodney ROM programmer
    [RODNEY-3BOARD-SINGLE-SHEET-BOM.csv]
2026-08-22 Update Rodney BOM and stock planning
    [RODNEY-3BOARD-SINGLE-SHEET-BOM.csv]
2026-08-22 Add to BoM
    [RODNEY-3BOARD-SINGLE-SHEET-BOM.csv]
2026-08-25 Update basket
    [basket-items.csv, basket-items.xls]
2026-08-25 Update inventory
    [list.csv]
2026-08-25 Refresh Rodney readiness status
    [basket-items.csv, list.csv]
2026-08-25 Document joy circuit trainer integration
    [list.csv]
2026-08-25 Basket checks
    [BASKET-FINAL-CHECK.csv, basket-items-clean.csv, basket-items.xls]
2026-08-25 Update list
    [list.csv]
2026-08-25 Add Rodney 6x09 redesign planning package
    [RODNEY-3BOARD-SINGLE-SHEET-BOM-6X09.csv, RODNEY-3BOARD-SINGLE-SHEET-BOM-8085-REFERENCE.csv]
2026-08-26 Refine Rodney 6x09 revision and clock notes
    [RODNEY-3BOARD-SINGLE-SHEET-BOM-6X09.csv, list.csv]
